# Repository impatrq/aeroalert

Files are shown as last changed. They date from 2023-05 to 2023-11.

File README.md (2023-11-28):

<div align="center">

# **AeroAlert**

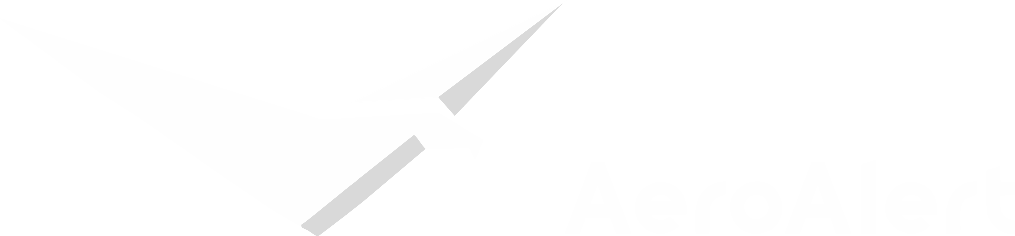
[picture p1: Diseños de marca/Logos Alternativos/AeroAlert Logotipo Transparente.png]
Logo proyecto


</div>

# ¿Qué es AeroAlert?

Aeroalert es un prototipo de sistema de emergencia para aeronaves basado en el monitoreo constante de parámetros de salud de los pilotos para prevenir accidentes aeronauticos.
El sistema cuenta con una pulsera dotada de los sensores necesarios. Si se detecta un estado de salud urgente que implique que el piloto este incapaz de controlar la aeronave, se le otorga el control al piloto automático nativo, el cual, a través de dos equipos de procesamiento diseñados por nosotros, entabla una comunicación con la CTRT correspondiente para llevar la aeronave a una situación que permita evitar el riesgo de accidente.

 * 🎞️ Video presentación: [Aeroalert](https://www.youtube.com/watch?v=lwCH7T5NRF8&ab_channel=ProyectoAeroAlert)

 * 📰 [Notas y difusión](https://docs.google.com/document/d/1UdKEXQvbZDQbbGeclpEPnfsf2L1TE1_X/edit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)

### ¿Quiénes lo desarrollan?
AeroAlert es un proyecto realizado por alumnos de 7mo Año de la **Escuela de Educación Secundaria Técnica N°7 "Taller Regional Quilmes"**, especialidad Aviónica.

<p align="center">
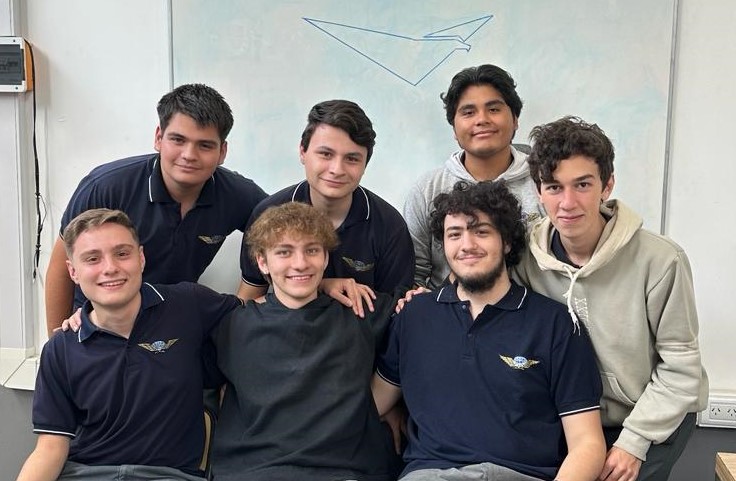
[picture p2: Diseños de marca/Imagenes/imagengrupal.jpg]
Imagen Grupal
  
</p>

# Integrantes

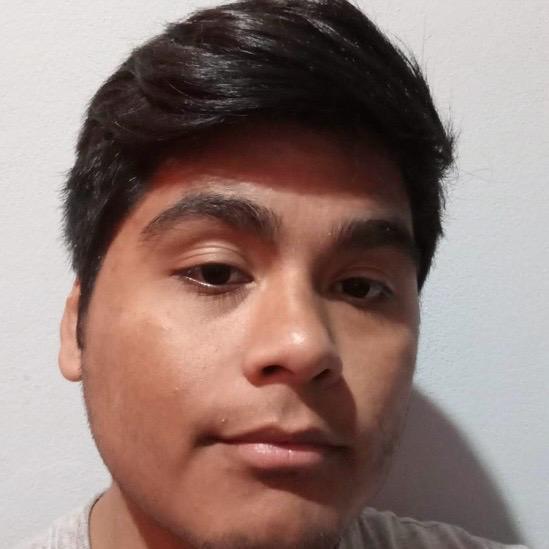
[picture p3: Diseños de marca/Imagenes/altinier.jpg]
Altinier
 * ### *Altinier, Mauro*

    *    📷 Instagram: [@agustin_altinier](https://www.instagram.com/agustin_altinier/)
    *    📧 Email: [mauro.altinier@gmail.com](mailto:mauro.altinier@gmail.com)         
    *    LinkedIn LinkedIn: [Mauro-Agustin-Altinier](https://www.linkedin.com/in/Mauro-Agustín-Altinier)

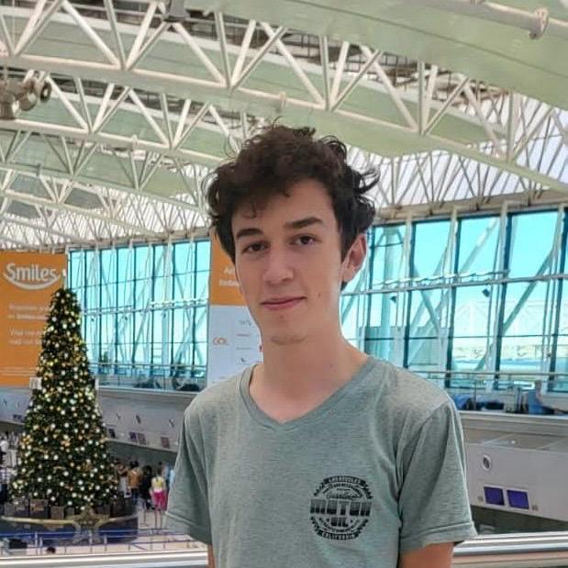
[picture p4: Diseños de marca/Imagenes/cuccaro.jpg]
Cuccaro
 * ###  *Cuccaro, Juan*

    *    📷 Instagram: [@cuccaro_juan](https://www.instagram.com/cuccaro_juan/)
    *    📧 Email: [manucucca10@gmail.com](mailto:manucucca10@gmail.com)
    *    LinkedIn LinkedIn: [juan-cuccaro](https://www.linkedin.com/in/juan-cuccaro/)

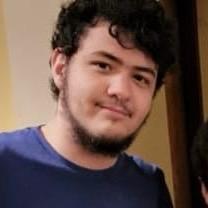
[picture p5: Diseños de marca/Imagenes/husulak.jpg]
Husulak
 * ###  *Husulak, Mateo*

    *    📷 Instagram: [@matehusu_2](https://www.instagram.com/matehusu_2/)
    *    📧 Email: [matehusu@gmail.com](mailto:matehusu@gmail.com)
    *    LinkedIn LinkedIn: [mateo-gaston-husulak-ledo](https://www.linkedin.com/in/mateo-gaston-husulak-ledo-52b742270/)

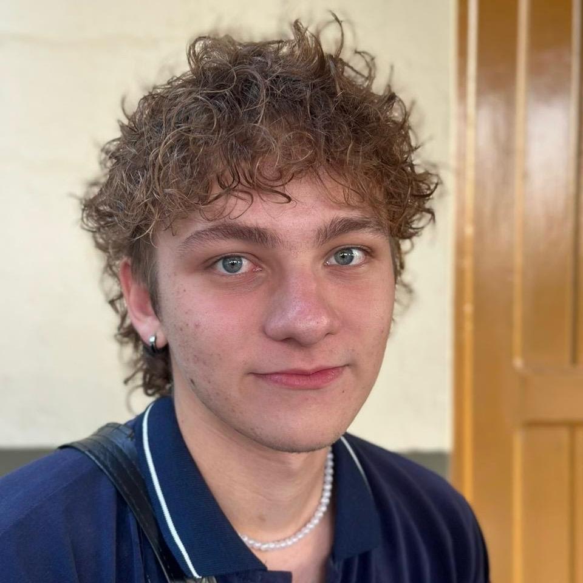
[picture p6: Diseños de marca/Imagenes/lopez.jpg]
Lopez
 * ###  *López, Teo*

    *    🧾 Curriculum vitae: [CVLópezTeoNicolas](https://drive.google.com/file/d/1_G5UPTjoewlIe7h19vwuFQ2f_dssRR7e/view?usp=sharing)
    *    📷 Instagram: [@nico67676](https://www.instagram.com/nico67676/)
    *    📧 Email: [teonicolaslopez8@gmail.com](mailto:teonicolaslopez8@gmail.com)
    *    LinkedIn LinkedIn: [teo-lópez](https://www.linkedin.com/in/teo-lópez/)

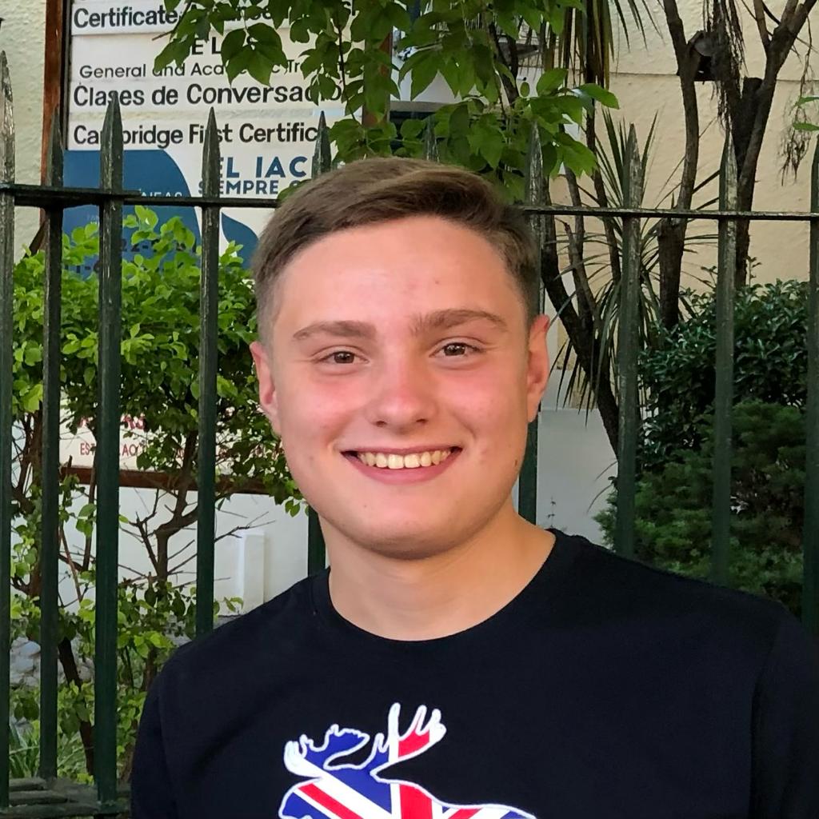
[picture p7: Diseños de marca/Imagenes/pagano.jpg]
Pagano
 * ###  *Pagano, Jonás*

    *    📷 Instagram: [@jonaspagano](https://www.instagram.com/jonaspagano/)
    *    📧 Email: [paganojonas@gmail.com](mailto:paganojonas@gmail.com)
    *    LinkedIn LinkedIn: [jonaspagano](https://www.linkedin.com/in/jonaspagano/)

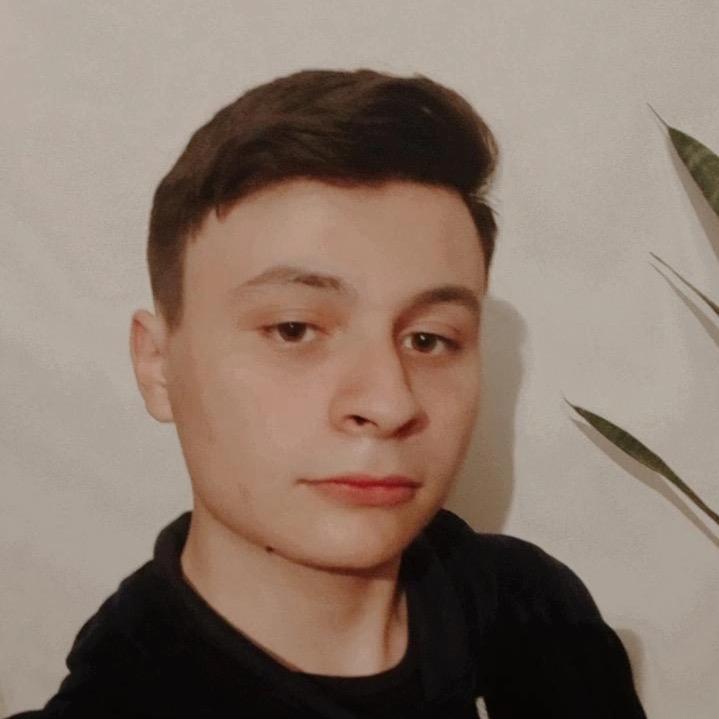
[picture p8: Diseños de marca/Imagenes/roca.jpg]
Roca
 * ###  *Roca, Leandro*

    *    📷 Instagram: [@lean_ro64](https://www.instagram.com/lean_ro64/)
    *    📧 Email: [leandroroca49@gmail.com](mailto:leandroroca49@gmail.com)
    *    LinkedIn LinkedIn: [leandro-roca](https://www.linkedin.com/in/leandro-roca/)

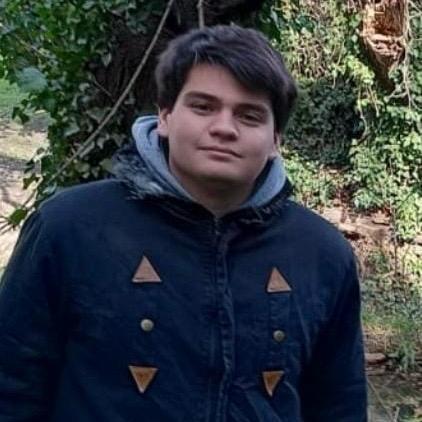
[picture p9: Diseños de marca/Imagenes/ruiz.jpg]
Ruiz
 * ###  *Ruíz, Nicolás*
    *    📷 Instagram: [@nicoo__ruiz](https://www.instagram.com/nicoo__ruiz/)
    *    📧 Email: [ruizagustinnicolas20@gmail.com](mailto:ruizagustinnicolas20@gmail.com)
    *    LinkedIn LinkedIn: [](https://www.linkedin.com/)

# **Contactos** 

* ####    📧 Email: [proyectoaeroalert@gmail.com](mailto:proyectoaeroalert@gmail.com)
* ####    🌐 Página Web: [www.aeroalert.com.ar](https://www.aeroalert.com.ar/)
* ####    📷 Instagram: [@aeroalert.impa](https://www.instagram.com/aeroalert.impa/)
* ####    LinkedIn LinkedIn: [AeroAlert](https://www.linkedin.com/company/aeroalert/)

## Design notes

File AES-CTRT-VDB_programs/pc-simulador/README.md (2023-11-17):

## Requerimientos

```shell
# Recepcion UART para reproduccion de alertas
$ pip install pyserial

# Reproducción alertas
$ pip install playsound==1.3

# Interfaz protocolos
$ pip install arcade
```
Tambien sera necesario instalar los plugins de X-plane

# Procedimiento

Luego de ejecutar el programa en el AES, ejecutar el programa GUI.py y ejecutar UART_X-plane mientras el simulador X-plane se esta ejecutando.

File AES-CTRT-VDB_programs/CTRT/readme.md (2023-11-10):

# Procedimiento
Guardar todos los archivos en la ESP32 con las carpetas en el orden en el que estan
Para esto se puede abrir una pestaña de thonny en  "ver" --> "archivos" y subir todos con click derecho

ejecutar "microdot_mas_keypad..... .py"

Luego de que se ejecuto el programa del AES en la ESP32 y el de la ESP32 de la CTRT , conectarse a la red WiFi ESP32 con la contraseña que este asignada en "accesssv9.py"
En la consola de la ESP32 aparecera la configuracion de la conexion wifi y en que direccion se hosteo la pagina web

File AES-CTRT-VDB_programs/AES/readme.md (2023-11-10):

# Procedimiento

Guardar ambos archivos en el microcontrolador ESP32
Manteniendola conectada a la PC se le da a reset para que se ejecute el programa (sin tener ninguna consola viendo la informacion de la ESP32 ya que esto interferiria en la comunicacion UART)

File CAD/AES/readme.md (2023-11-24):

<div align="left">

# **Automatic Emergency System (AES)**
Acrónimo en idioma inglés de Automatic Emergency System, es el módulo que se se encuentra alojado en cabina, encargado de recibir y procesar la información recopilada por la instrumentación sensorial del sistema (módulo V.D.B). Este equipo desempeña un papel crucial al emitir avisos pertinentes en cabina, establecer comunicación con el equipo en tierra y, en situaciones críticas, interactuar con el piloto automático nativo de la aeronave. La capacidad de establecer comunicación bidireccional con el equipo en tierra permite la transmisión efectiva de datos relevantes y la recepción de instrucciones actualizadas, lo cual es esencial para la coordinación durante operaciones de emergencia.

<p align="center">
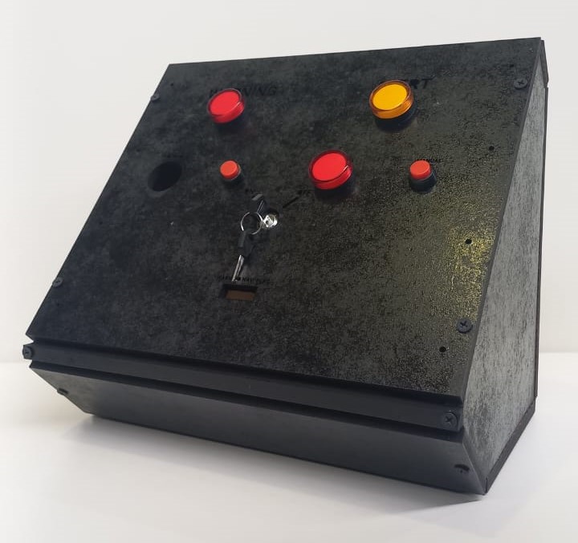
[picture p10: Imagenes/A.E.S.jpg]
AES
  
</p>

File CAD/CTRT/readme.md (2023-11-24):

<div align="left">

# **Control Tower Reciever - Transmitter (CTRT)**
Acrónimo en idioma inglés alusivo a Control Tower Reciever and Transmitter (en español: Receptor y Transmisor de la Torre de Control), es un módulo alojado en tierra y a disposición del control de tráfico aéreo, cuyo propósito es el de recibir, representar visualmente e informar a los controladores aéreos de emergencias, alertas y/o peticiones. Además de su rol informativo, el módulo C.T.R.T se encarga de generar y transmitir instrucciones al equipo en cabina, específicamente al módulo A.E.S. Su propósito primordial es facilitar la ejecución de aterrizajes de emergencia en caso de que esta acción sea necesaria, garantizando una comunicación efectiva y coordinada entre la torre de control y la aeronave, contribuyendo así a la seguridad y eficiencia en situaciones críticas.

<p align="center">
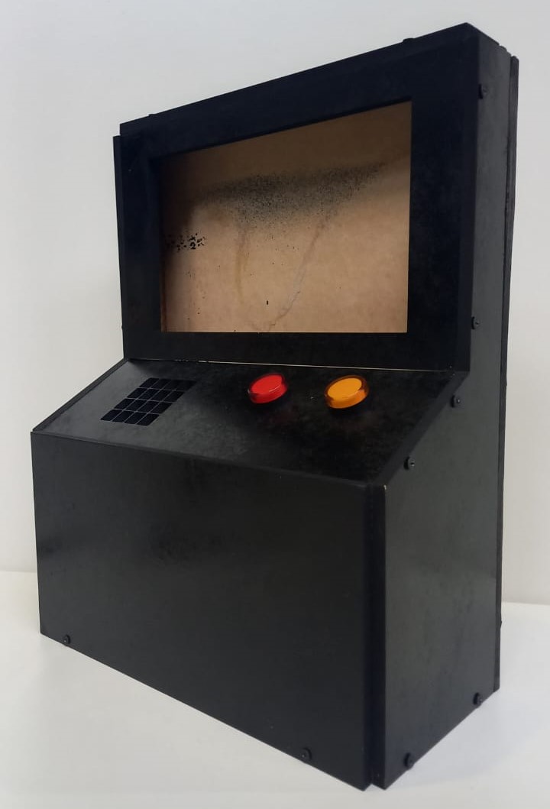
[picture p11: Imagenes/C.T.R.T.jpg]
CTRT
  
</p>

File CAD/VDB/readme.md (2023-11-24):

<div align="left">

# **Vital Data Bracelet (VDB)**
Acrónimo en idioma inglés de Vital Data Bracelet (en español: Pulsera Detectora de Signos Vitales), corresponde al dispositivo pulsera portado tanto por piloto como por copiloto (en caso de existir este último). Su función principal es aquella relacionada al relevamiento de datos asociados a la salud de los conductores de la aeronave (llámese comandante y su potencial compañero de fórmula en caso de existir), con el objetivo de proveer un monitoreo permanente de las variables a medir tanto en cabina como en tierra, de forma tal que exista la posibilidad de generar alertas y/o emergencias tanto de manera presencial (en el medio de transporte físico del vuelo) como remota (por medio del control de tráfico aéreo) en función de las variables de salud relevadas por el módulo descrito previamente, permitiendo la detección temprana de posibles problemas de salud y la toma de medidas adecuadas. La integración de esta tecnología se alinea con el enfoque del proyecto para garantizar la monitorización efectiva de los signos vitales y la rápida respuesta ante cualquier eventualidad.

<p align="center">
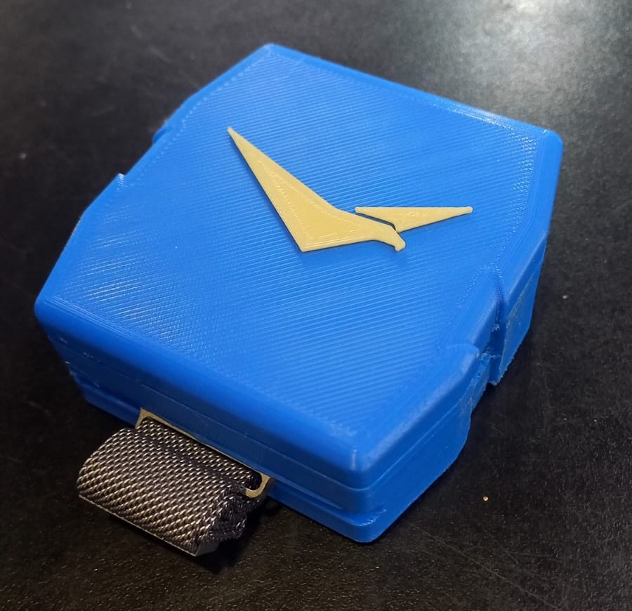
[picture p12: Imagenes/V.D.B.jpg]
VDB
  
</p>

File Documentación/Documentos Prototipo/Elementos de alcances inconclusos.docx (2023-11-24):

Alumnos: Altinier, Mauro / Cuccaro, Juan Manuel / Husulak, Mateo / López, Teo / Pagano, Jonás / Roca, Leandro / Ruiz, Nicolás

Curso y Comisión: 7mo 1ra Aviónica (Comisión A)

Nombre del Proyecto: AeroAlert

Listado de Pendientes

La evaluación del estado de finalización del proyecto en relación a los objetivos de desarrollo del mismo planteados durante el inicio del ciclo lectivo permitió arrojar las siguientes funcionalidades pendientes:

- Procedimientos para cambio de tripulación: El procedimiento de cambio de tripulación no alcanzó su desarrollo, concluyendo que su prueba resultaría desprolija y se alejaría del objetivo principal del proyecto en cuanto a detección y respuesta ante emergencias en vuelo, entorpeciendo su demostración funcional. Por lo tanto, se procedió al descarte del mismo.
- Base de datos de salud: Desde un principio, se planteó la idea de relevar las mediciones del dispositivo pulsera a una base de datos que por medio de la cual se enseñarían valores de salud en la página web del proyecto. Si bien se trabajó y logró un modelo de base de datos, por decisión del equipo de trabajo de dedicarse a demás áreas en pro de generar avances en cuanto a las funcionalidades demostrables del proyecto, el muestreo de datos en la web fue descartado.
- Procedimientos de descanso reglamentario: Este procedimiento, al igual que el anterior, se valdría de la utilización del dispositivo pulsera para su demostración funcional. Sin embargo, fue descartado bajo las mismas consignas que el pendiente anterior.
- Encendido de dispositivo pulsera: El pendiente en cuestión destacaba la implementación de componentes lumínicos y sonoros / vibratorios para la alerta de encendido del dispositivo. Sin embargo, dicha propuesta fue descartada tras la obtención de resultados similares por medio de la detección de encendido y operación del sensor integrado (el mismo emite un haz de luz cuando se encuentra en funcionamiento), lo cual permitió la optimización de espacio en la plaqueta, y un diseño de carcasa de mayor ergonomía.

Por otro lado, los distintos dispositivos requieren de conexión a una computadora por medio de un cable microUSB para alimentación, lo cual resulta en un impedimento para la autonomía de los equipos (necesaria para una demostración lo más fidedigna posible en relación al entorno aeronáutico). Sin embargo, y aunque resulte en una pérdida de calidad en el acabado de dichas unidades para con su funcionamiento, la autonomía de las mismas en cuanto a alimentación nunca fue planificada en el desarrollo del proyecto. Particularmente, un error de diseño en el dispositivo pulsera en cuanto a la regulación de voltaje requiere que el mismo se encuentre conectado a una fuente de alimentación externa por medio del módulo de carga integrado, siendo esta la única unidad del proyecto planteada como autónoma desde el inicio.

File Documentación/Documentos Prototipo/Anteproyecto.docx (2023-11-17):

AeroAlert

Presentación de anteproyecto

# Título del proyecto:

El nombre del proyecto busca encerrar en sí mismo el objetivo a alcanzar. El prefijo Aero enuncia la orientación aeronáutica del proyecto, mientras que la palabra Alert hace referencia al segmento en que se enfoca el sistema (la respuesta ante emergencias en vuelo).

# Integrantes:

- Altinier, Mauro Agustín
- Cuccaro, Juan Manuel
- Husulak Ledo, Mateo Gastón
- López, Teo Nicolás
- Pagano, Jonás
- Roca, Leandro Gabrel
- Ruiz, Nicolás Agustín

# Objetivo del proyecto:

AeroAlert es un sistema de emergencia, el cual tiene como meta prevenir un amplio rango de accidentes aéreos. En pro de tal objetivo, implementa un procesamiento y monitoreo constante de parámetros que involucran tanto a los pilotos de aeronaves como al entorno que los rodea.

Alrededor del 70% de los accidentes aéreos ocurren debido a fallas humanas, entre las cuales destacan algunas como las imprudencias, el cansancio y el vuelo en condiciones de salud no óptimas, entre otras.

En base a lo previamente dicho, AeroAlert propone el desarrollo de equipos que permitan no solo un monitoreo constante, sino también que provean de una respuesta eficiente ante emergencias que, al día de hoy, no son capaces de resolverse de forma íntegra, y con mínimos o nulos daños, lo cual reduciría enormemente los costos económicos y humanos para las distintas partes implicadas en la industria aeronáutica.

# Utilidades de el proyecto:

El sector aeronáutico ha tenido un progreso notable en todas las dimensiones a lo largo de las últimas décadas de la historia. Hoy en día, los aviones son ampliamente considerados como el medio de transporte más seguro que existe. A pesar de esto, y aunque ocurren con poca frecuencia, los accidentes aéreos siguen teniendo un enorme potencial destructivo: se cargan la vida de pasajeros y civiles, la reputación de empresas e ingenieros, e inclusive la existencia de corporaciones enteras.

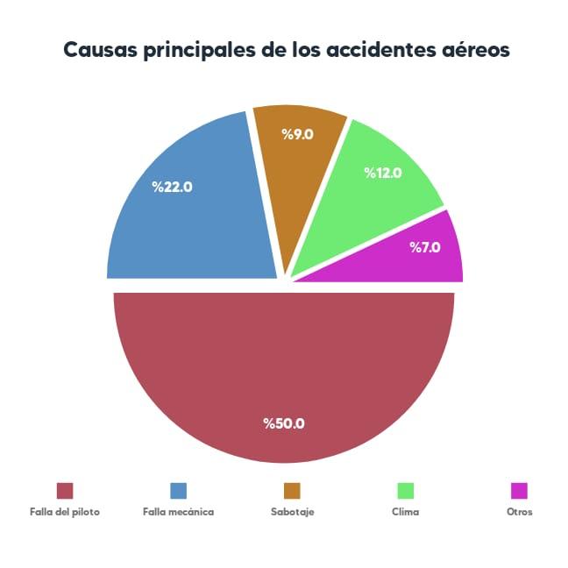
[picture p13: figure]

Estadísticas sobre las causas de accidentes aéreos

AeroAlert tiene como utilidad la prevención de accidentes aéreos, cuya principal causa sigue siendo el factor humano. El censado constante de las condiciones de salud de los pilotos, sumado a la implementación de equipos que permiten tener un control tanto automático como manual (a través del piloto) y externo (por medio de la torre de control) será capaz de reducir considerablemente el riesgo de siniestros aéreos, permitiendo la preservación de la vida y de recursos económicos en el sector aeronáutico.

Descripción del funcionamiento:

Para lograr el objetivo se confeccionará una pulsera, que enviará los datos al “PAE”(Piloto Automático de Emergencia) que estaría en la cabina, de este se enviará a un equipo que se encuentra en una torre de control donde se pueden analizar los datos recibidos y mandar instrucciones al PAE.

La pulsera tendra un sensor Max30102 que medira las pulsaciones y la saturación de oxígeno en sangre, con una Esp32 Wroom, este procesara los datos censados para que sean datos de menor peso y posteriormente mandarlos al sistema PAE mediante Bluetooth, la pulsera se alimentara con una batería de litio con un regulador de voltaje Step down 3,3v.

El PAE tendrá una Esp32 que los procesa y dependiendo el resultado pedirá una reacción del piloto, deberá tocar el botón para avisar que no es una urgencia, los datos se mandarán igualmente a la torre de control mediante una red WiFi (en caso real con otro protocolo), en la torre de control habrá otra persona que analizara los datos recibidos y enviar o no, instrucciones al PAE para mantener la seguridad del vuelo.

- En el caso del oxígeno en sangre, por ejemplo, si se está por debajo del 96%, se toma en cuenta junto a las pulsaciones para definir si el piloto podria está dormido y mandar una alerta, a la vez pedirá la reacción del piloto, si reacciona a tiempo entonces y no será una alerta; y en caso de inferioridad al 90% se envía un alerta de alta importancia al R.T.D.C, ya que probablemente el piloto se encuentre en riesgo.
- Cuando las pulsaciones sean inferiores a 20 ppm, también se mandará una alerta al R.T.D.C, ya que la vida del piloto corre peligro; si superan las 140 ppm también, ya que esto podría indicar algún problema, naturalmente en un vuelo no deberían tener tan altas las pulsaciones por minuto, por lo tanto podría significar un posible problema.
- En la ocasión de que el piloto decida activar el P.A.E de forma manual, lo puede hacer presionando el botón de activación manual.
- Si el P.A.E tiene alguna falla por índole eléctrico, el piloto podrá desactivar el sistema mediante un botón.
- También se pueden evitar accidentes con siniestros aeronáuticos, cuando se detecte la torre de control activará el piloto automático de emergencia sin que el avión pueda evitarlo.
- En adición, aunque como un tramo opcional del proyecto, se buscará realizar la implementación del sistema en el simulador Avis.

# Análisis de factibilidad:

En el grupo, decidimos dividir el trabajo del proyecto en 4 sectores:

- Diseño y construcción: Dentro de este sector de trabajo, se llevará a cabo el diseño estructural de los equipos, su ensamblaje y su disposición en un espacio que resulte no intrusivo.
  - El alumno Ruiz Nicolás Agustín se encargará del diseño estructural
  - El alumno Altinier Mauro Agustín llevará a cabo la tarea de ensamblaje y acabado final
- Electrónica: Este sector se encarga del diseño y planificación de circuitos electrónicos (a través de simulaciones y planos CAD), el ensamblaje de componentes, el armado de placas y de la instalación eléctrica del piloto automático de emergencia.
  - Los alumnos Pagano Jonás y Roca Leandro Gabriel trabajarán en conjunto en el diseño esquemático y simulación preliminar de los circuitos electrónicos de los equipos
  - El alumno Pagano Jonás se encargará de la implementación de los circuitos en PCB.
  - El alumno Lopez Teo Nicolás se encargará del ensamblaje de componentes y comprobación de correcto funcionamiento de los circuitos electrónicos.
- Programación: Este entorno de trabajo se encarga de toda la programación del sistema de emergencia propuesto (conexión bluetooth entre pulsera y PAE, PAE con RTdc, programa del PAE para cálculos, programa RTdc y el desarrollo del código de la página web).
  - Los alumnos Cuccaro Juan Manuel y Husulak Ledo Mateo Gastón trabajarán simultaneamente realizando los programas necesarios para la pulsera, el PAE y la RTdc
  - Los alumnos Pagano Jonás y Roca Leandro Gabriel trabajarán con el programa que permita entablar una comunicación entre el simulador X-Plane y el PAE.
  - Los alumnos Husulak Ledo Mateo Gastón y Ruiz Nicolás Agustín se encargarán del desarrollo de la página web del proyecto.
- Marketing: En esta área de trabajo se desarrollará un trabajo conjunto entre todos los miembros del grupo, los cuales tendrán como objetivo mantener actualizados los perfiles de redes sociales del proyecto con material informativo y avances de las labores realizadas. Al mismo tiempo, y complementandose con el área de programación, se desarrollará una página web que provea la información básica y esencial de nuestro proyecto.
  - El alumno Lopez Teo Nicolás se encargará del diseño de la representación visual y gráfica de la página web y sus elementos.
  - Todos los integrantes tendrán control directo sobre las redes sociales. Se prevé crear perfiles tanto en Instagram como en LinkedIn
  - El alumno López Teo Nicolás será el encargado de diseñar el material publicitario alternativo (pegatinas, folletos, etc.) Como un objetivo de cumplimiento opcional, nos propondremos la confección de camisetas AeroAlert para el equipo de trabajo.
  - También en este entorno, intentaremos encontrar empresas interesadas en apoyar el proyecto ya sea aportando dinero o alguna herramienta que podamos usar.

# Costo del proyecto:

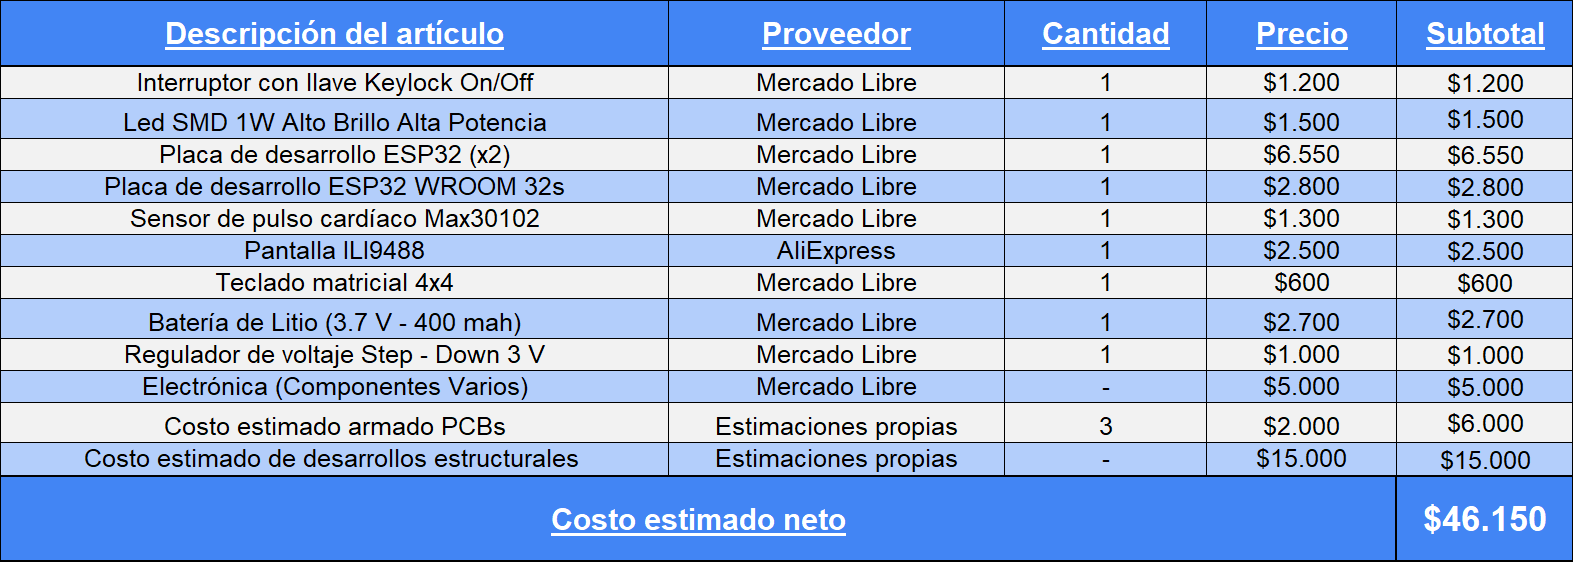
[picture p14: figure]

Nota: Los precios se encuentran actualizados al día 10/3/23.

# Análisis de costo/beneficio:

Inclusive siendo considerado como el medio de transporte más seguro en todo el mundo, el avión (así como quienes lo pilotan y se transportan en él) no se encuentra exento de sufrir accidentes por desperfectos técnicos y, principalmente, por cuestiones humanas.

Además, y por increíble que resulte en una industria tal como la aeronáutica, existen casos de emergencia que, al día de hoy, no tienen una respuesta completa que minimice el riesgo de accidentes y muertes tanto de pasajeros como de la tripulación y potenciales civiles en tierra. Tan solo se debe pensar qué ocurre si todos los ocupantes de una aeronave quedan inconscientes por hipoxia, o qué pasaría si un piloto desea acabar con su vida estrellando un avión comercial. A pesar de que existan protocolos contra estos casos, ninguno es capaz de reducir al mínimo la posibilidad de accidentes y muertes, ya sea a través de un control automático o el monitoreo de la situación por parte de la torre de control.

Durante las investigaciones preliminares llevadas a cabo por miembros de este grupo, se han detectado un total de 27 casos relacionados (de los cuales 15 cuentan con desenlaces fatales) en un lapso de 35 años hasta la actualidad). Esta idea sería capaz de despertar interés en fabricantes de equipos aeronáuticos, aerolíneas y/o agencias reguladoras nacionales e internacionales, que podrían buscar llevar a cabo la idea propuesta de una forma que hoy en día el grupo de trabajo, con sus recursos disponibles, no sería capaz.

# Diagrama en bloques del prototipo:

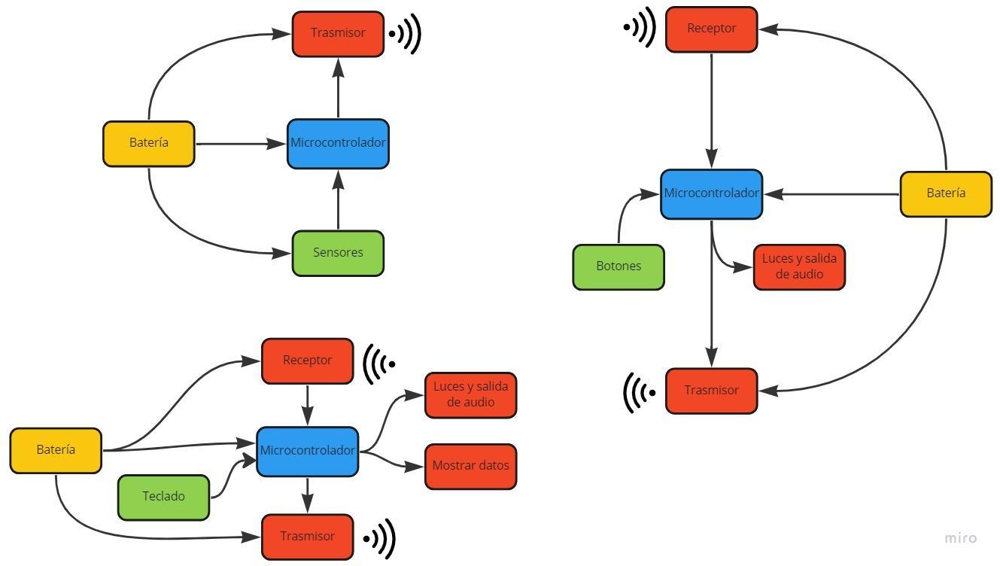
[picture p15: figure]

Diagrama de tiempo de desarrollo:

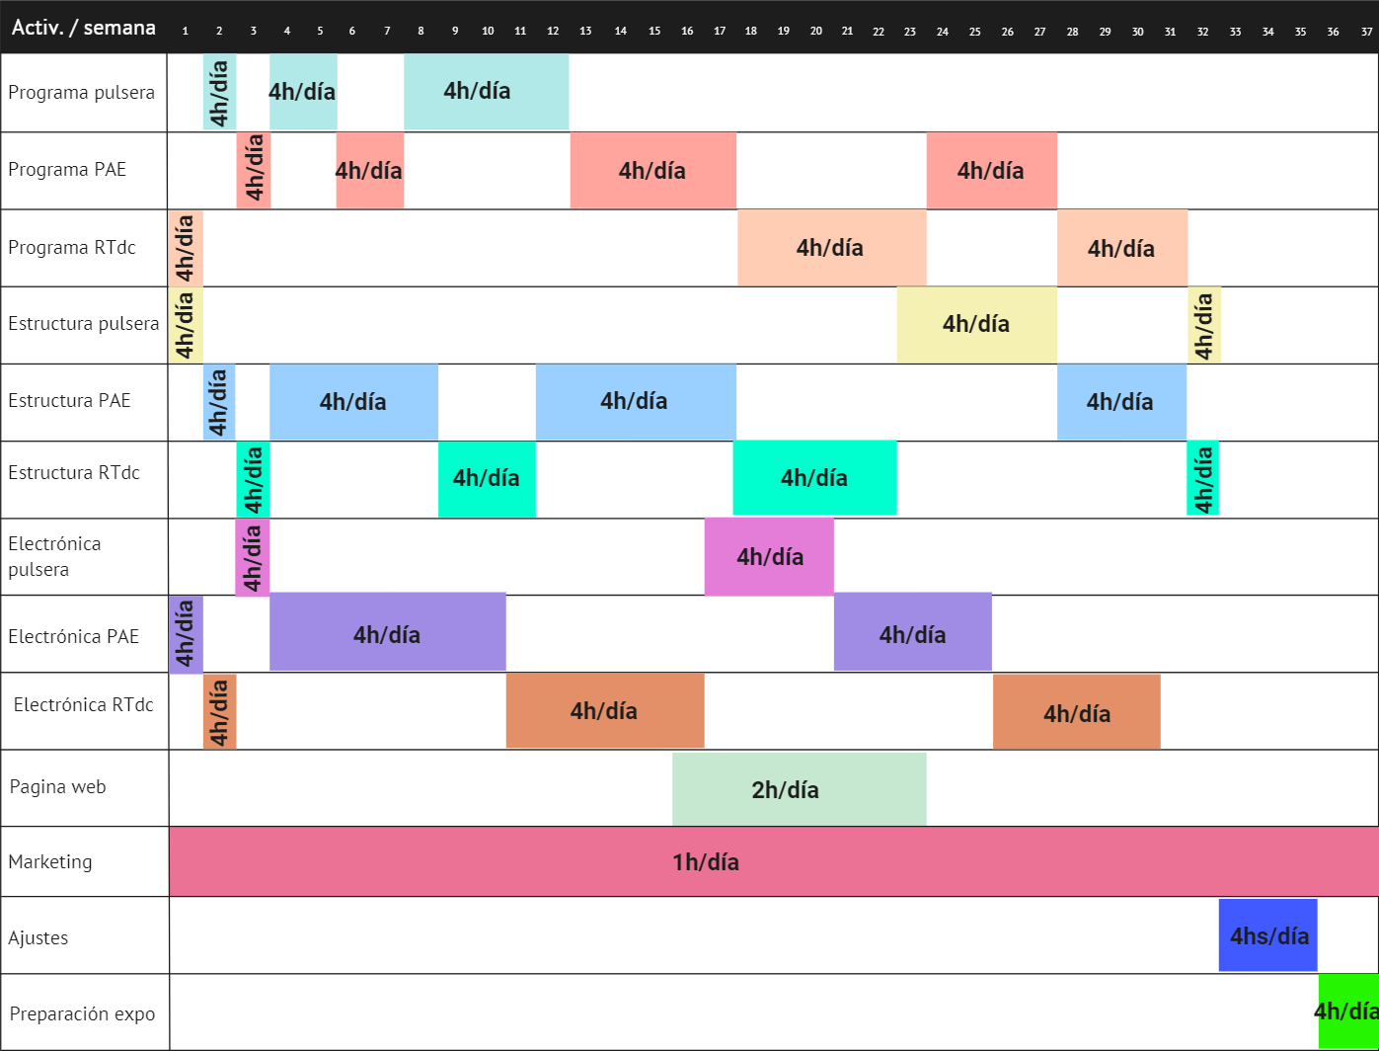
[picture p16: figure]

Fuentes

(1) https://docs.google.com/document/d/1L2hu_MUP8gzjOCmHIrkDrV9m0Blvit6O/edit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

Escuela de Educación Técnica Nº7 Taller Regional Quilmes Prácticas Profesionalizantes: Especialidad Aviónica

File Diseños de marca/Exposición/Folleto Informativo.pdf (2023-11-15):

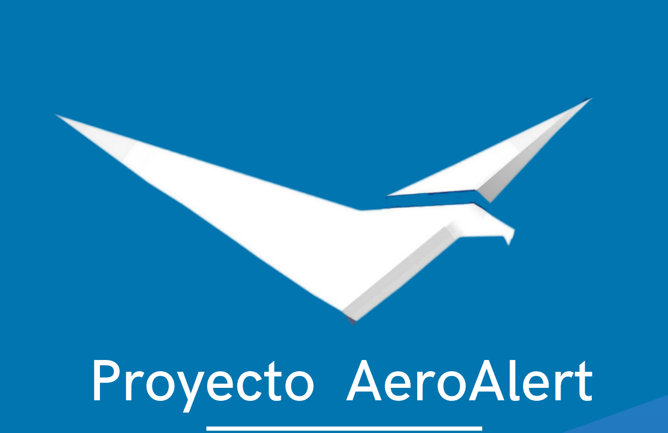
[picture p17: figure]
Proyecto AeroAlert

Sistema de emergencia para aeronaves

Hoy en día la seguridad de las aeronaves no ha parado de aumentar, pero a pesar de su crecimiento acelerado en las últimas décadas todavía hay determinados casos en los cuales no existen protocolos adecuados o eficientes.

Situaciones como desmayos de los pilotos, muerte de ambos, inconsciencia por hipoxia, casos de siniestros dolosos (secuestro, suicidio por parte de la tripulación), son ejemplos claros en donde no existe un protocolo eficaz.

Nuestra meta es proponer una solución funcional para estos casos, permitiendo así vuelos más seguros y desarrollar un sistema de control más sofisticado en las aeronaves.

Nuestro objetivo

### ¿Quiénes somos?

Somos un grupo de estudiantes de 7mo 1ra Aviónica, conformado por:

•Altinier Mauro
•Cuccaro Juan Manuel
•Husulak Mateo
•Lopez Teo

•Pagano Jonás
•Roca Leandro
•Ruiz Nicolás

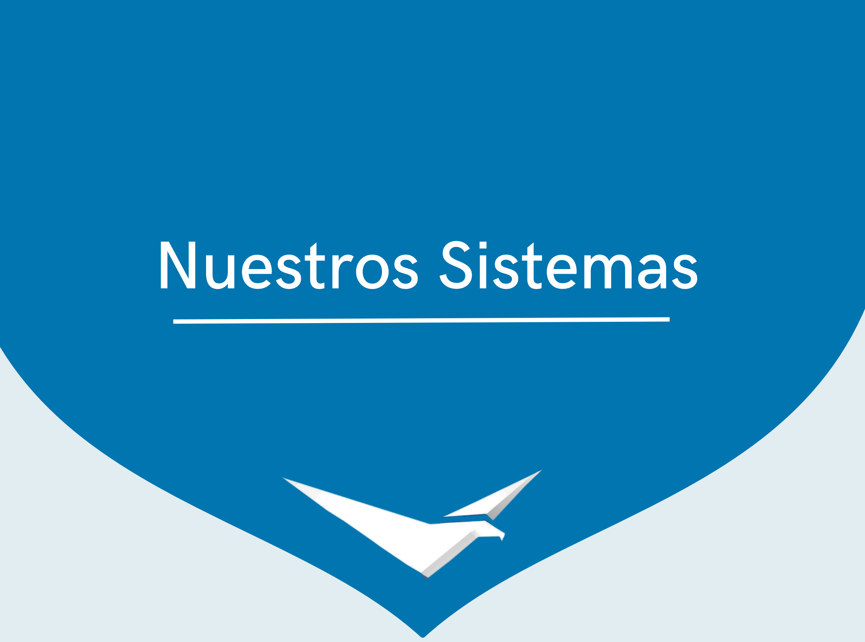
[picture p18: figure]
Nuestros Sistemas

ICERS - I | ICERS - II

## Características de ambos sistemas

No requiere de una
intervención estructural en la
cabina

Puede ser implementado
en cualquier aeronave

Prevé de alertas para los
pilotos

Puede alertar a tierra con precisión del hecho ocurrido

Permite que la aeronave
pueda realizar aterrizajes de forma automática

Prevé ocasiones de
índole doloso

Es el sistema más
completo, diseñado para
aeronaves modernas.

Este sistema pretende ser
básico y económico para la implementación en
aeronaves pequeñas y/o
antiguas. | Tiene como objetivo evitar accidentes y alertar los mismos entre
| sus equipos.

Prioriza la transmisión de alertas dentro y fuera de
la aeronave, para una
mayor seguridad.

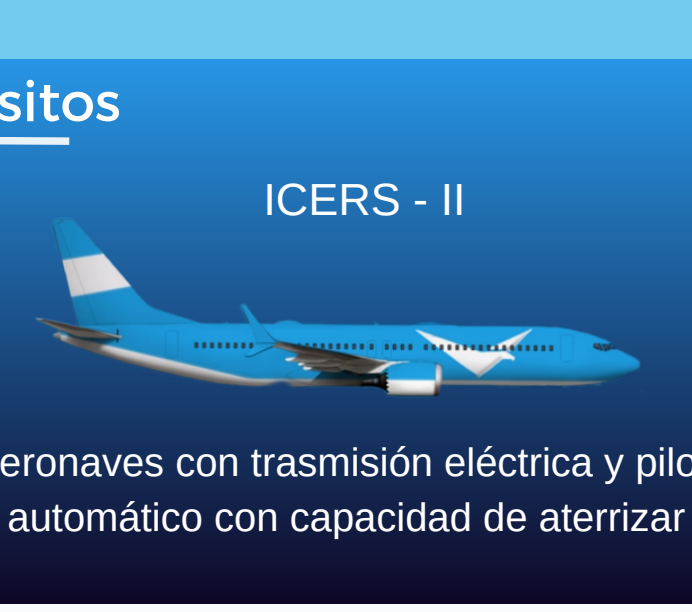
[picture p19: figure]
ICERS - II; automático con capacidad de aterrizar
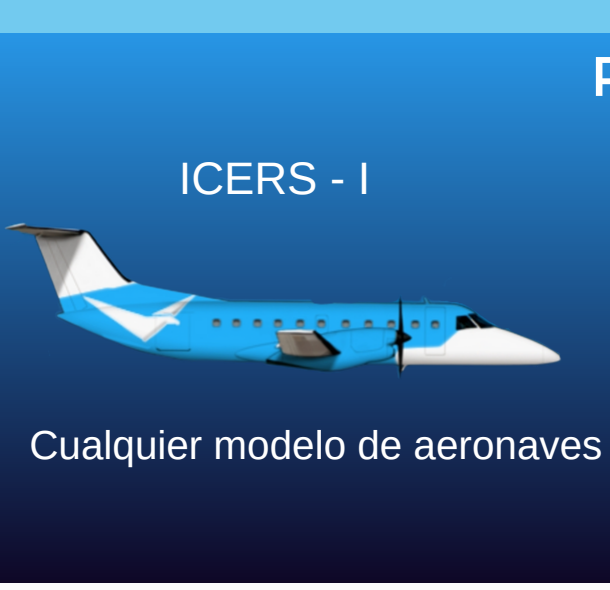
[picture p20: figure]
ICERS - I; Cualquier modelo de aeronaves

### Requisitos

Aeronaves con trasmisión eléctrica y piloto

In - Cockpit Emergency Resolution System - I In - Cockpit Emergency Resolution System - II

Además de poseer estas 2 versiones, también se puede adaptar el sistema ICERS para una aeronave en específico, obteniendo una versión personalizada.

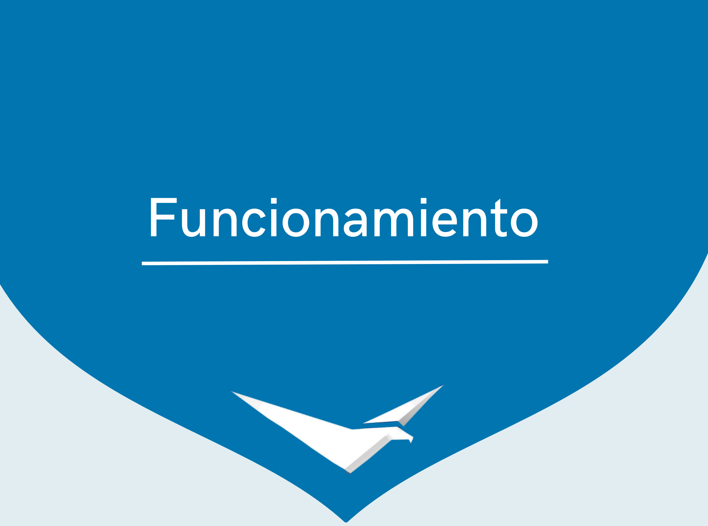
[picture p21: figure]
Funcionamiento

Posee 2 equipos, uno en cabina y otro en tierra, a disposición del control de trafico aéreo. El equipo en cabina se denomina A.E.S y debe procesar los datos enviados por los sensores y dependiendo de ellos activar o no un aviso, una alarma o una señal de emergencia.

Cuando esto último ocurre, procede a contactar con el equipo en tierra (denominado C.T.R.T), por medio del cual se transmiten comandos / instrucciones al A.E.S, cuya recepción y procesamiento de información transmitida desde tierra permitirá, por medio de una comunicación con la computadora de vuelo de la aeronave, efectuar aterrizajes de emergencia

## ICERS I

Solo posee un equipo y este es el de cabina, de igual manera puede poseer los mismos sensores que el ICERS II, pero en su funcionamiento se encuentran ligeras diferencias. A la hora de ocurrir un incidente, el A.E.S solo activa una baliza de radiofrecuencia de emergencia y muestra indicaciones en cabina.

## ICERS II

## Especificaciones del sistema

El sistema provee la implementación de cualquier tipo de sensor que pueda indicar un peligro para los tripulantes. En nuestro caso realizaremos las lecturas de las pulseras, que pueden medir las pulsaciones y la saturación del oxígeno de los pilotos.

El sistema posee protocolos para su utilización y para las acciones que deberán tomar los distintos actores (Pilotos y controladores aéreos) en caso de emergencia.

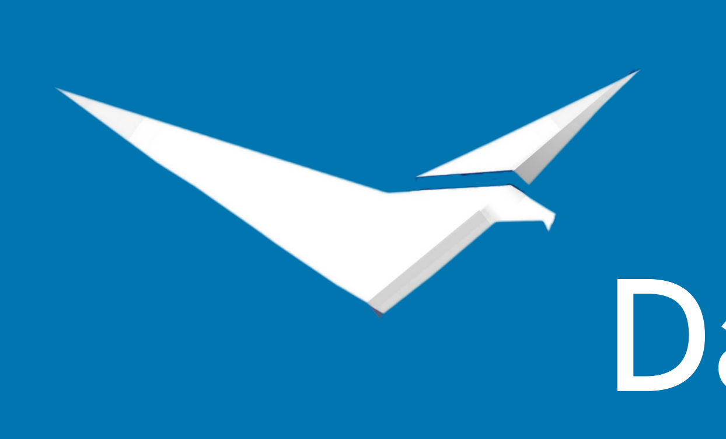
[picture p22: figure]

# Datos

Desde el año 1988 hasta la actualidad (2023) hemos registrando casi 40 accidentes producidos por los casos previamente dados, de los cuales 17 fueron fatales, llevándose consigo casi 1000 personas y con un costo estimado de 2 mil millones de dólares, sin contar indemnizaciones.

Algunos casos:

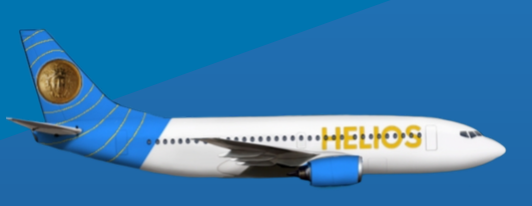
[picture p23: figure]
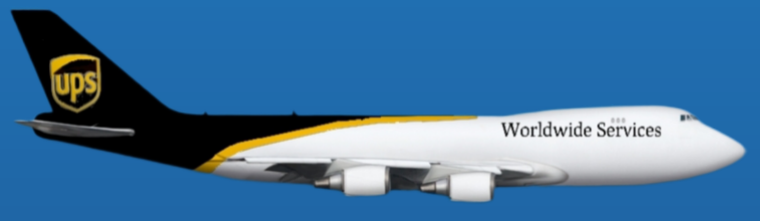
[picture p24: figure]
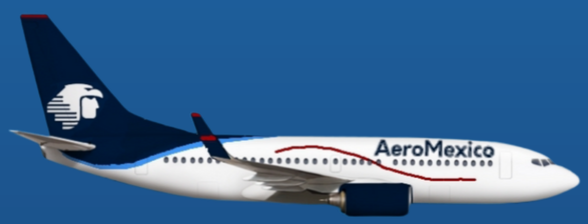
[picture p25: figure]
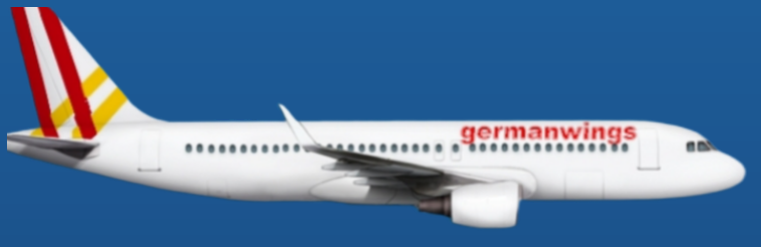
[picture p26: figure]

## Contacto

Vuelo 522 de Helios Airways | Vuelo 6 de UPS
Vuelo 9525 de Germanwings | Vuelo 576 de Aeroméxico

Empresas afectadas

American airlines
Helios Airways
Kalitta Flying
Aeroflot
Ups
United Airlines
British Airways
Germanwings
Royal Air marc
Air France
Singapore Airlines

Egyptair
Silkair
Continental Airlines
Etheopian Airlines
Citilink
Air India
Norwest Airlines
Envoy Air
China Eastern Airlines
Fedex
Scandinavian Airlines

Aeroméxico
LAM
Afriqiyah Airways
India Airlines
Avianca
All Nippon Airways
Air Botswana
Hemus Air
PIA
Lufthansa
Kuwait Airways
AeroAlert | proyectoaeroalert@gmail.com | aeroalert.impa

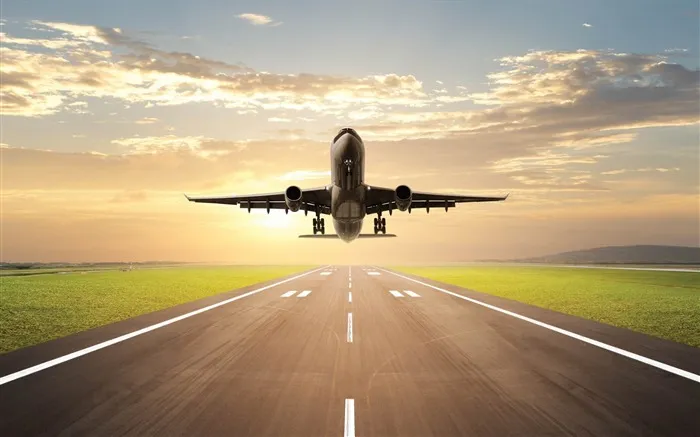
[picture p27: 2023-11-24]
Pagina Web/imgs/airplane_ready_to_take_off-Aircraft_HD_Wallpaper_medium.webp

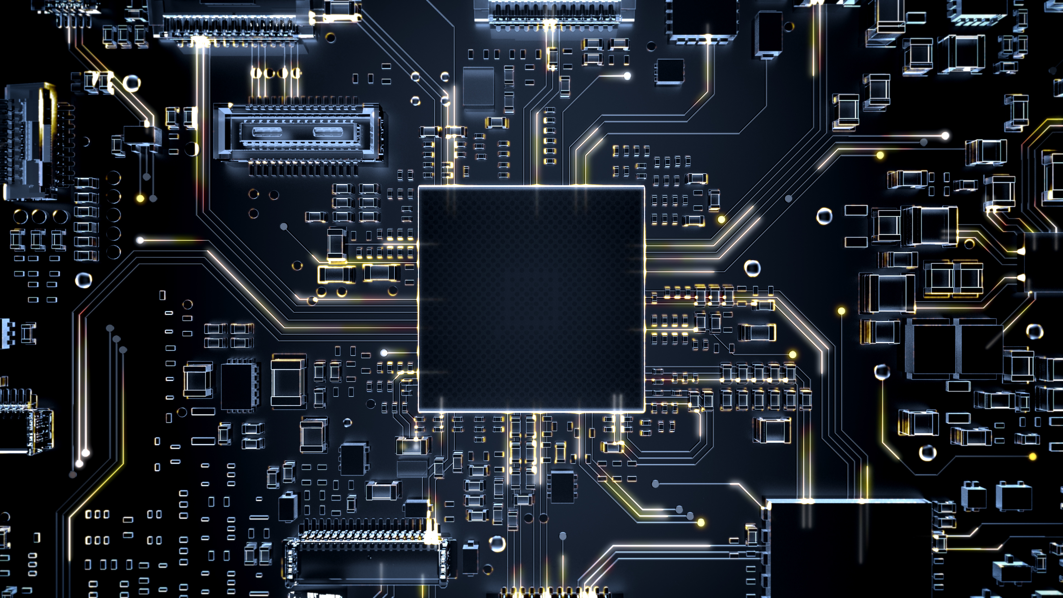
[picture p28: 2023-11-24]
Pagina Web/imgs/Electronica.jpg

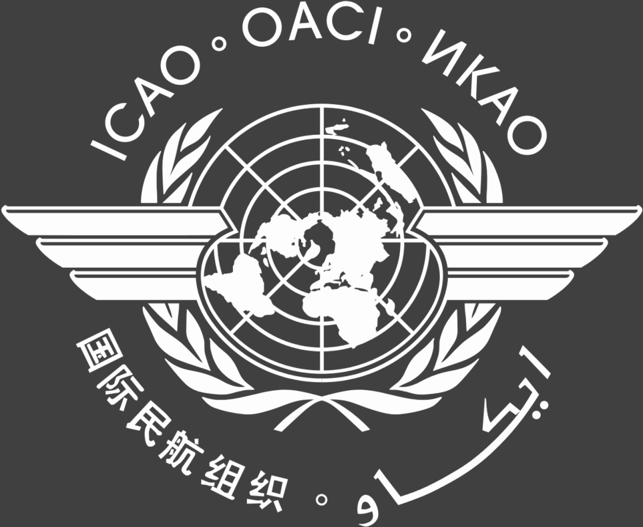
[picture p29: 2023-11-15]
Diseños de marca/Recursos adicionales/139-1392107_icao-united-nations-spa.png

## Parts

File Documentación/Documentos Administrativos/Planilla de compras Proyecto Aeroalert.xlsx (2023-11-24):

Adquirido | Cantidad | Componente | Link de referencia | Mejor precio | Por cantidad | Prestado? | Escuela? | Compra? | Proveedor | Devolver a:
TRUE | 1 | Interruptor con llave Keylock On/Off | CLICK (https://articulo.mercadolibre.com.ar/MLA-1297766235-interruptor-conllaves-%20keylock-switch-onoff-pc-omicron-%20_JM) | $800,00 | $800,00 | FALSE | TRUE | FALSE | Mercado Libre | -
TRUE | 1 | Teclado Matricial 4x4 | CLICK (https://articulo.mercadolibre.com.ar/MLA-726324320-tecladomembrana-%20matricial-4x4-keypad-arduino-autoadhesivo-_JM) | $450,00 | $450,00 | FALSE | TRUE | FALSE | Mercado Libre | -
TRUE | 2 | Modulo de desarrollo ESP32 | CLICK (https://articulo.mercadolibre.com.ar/MLA-1339854427-2-x-nodemcuesp32-%20wifi-bluetooth-38-pines-%20_JM) | $6.550,00 | $13.100,00 | FALSE | TRUE | FALSE | Mercado Libre | -
TRUE | 1 | Placa de desarrollo ESP32 WROOM 32s | CLICK (https://articulo.mercadolibre.com.ar/MLA-767959204-modulo-esp32wifi-%20y-bluetooth-41-esp-wroom-32-80211-b-g-n-_JM) | $2.900,00 | $2.900,00 | FALSE | TRUE | FALSE | Mercado Libre | -
TRUE | 1 | Sensor Pulsoximétrico Max 30102 | CLICK (https://articulo.mercadolibre.com.ar/MLA-1143512095-%20max30102oximetro-de-pulso-arduino-_JM) | $1.890,00 | $1.890,00 | FALSE | TRUE | FALSE | Mercado Libre | -
TRUE | 1 | Batería LiPol LP692530 | CLICK (https://articulo.mercadolibre.com.ar/MLA-835793454-bateria-37-%20v500mah-602530-3x25x60mm-_JM) | $2.160,00 | $2.160,00 | FALSE | TRUE | FALSE | Mercado Libre | -
TRUE | 1 | Regulador de voltaje LM2596T (3.3v) | CLICK (https://articulo.mercadolibre.com.ar/MLA-786025400-lm2596-) | $750,00 | $750,00 | FALSE | TRUE | FALSE | Mercado Libre | -
TRUE | 1 | Adaptador USB a UART PL2303 | CLICK (https://articulo.mercadolibre.com.ar/MLA-620762335-%20adaptadorconversor-usb-ttl-serie-pl2303-5v-33v-ptec-_JM) | $700,00 | $700,00 | FALSE | TRUE | FALSE | Mercado Libre | -
TRUE | 1 | Regulador de voltaje LM1117 (3.3v) | CLICK (https://articulo.mercadolibre.com.ar/MLA-721532318-lm-1117-lm-1117-lm-1117t-lm1117-lm1117t-33-ldo-8-a-to220-_JM) | $670,00 | $670,00 | FALSE | FALSE | TRUE | Electrónica RC | -
TRUE | 1 | Placa adaptadora para ESP32 | CLICK (https://articulo.mercadolibre.com.ar/MLA-737667310-wifi-esp32-placa-adaptador-para-esp32s-a-pines-itytarg-_JM) | $810,00 | $810,00 | FALSE | TRUE | FALSE | Mercado Libre | -
TRUE | 1 | Pack x10 unidades resistencias de 10KΩ SMD 0805 | CLICK (https://articulo.mercadolibre.com.ar/MLA-911446391-resistencia-10k-10000-ohm-0805-smd-10-unidades-5-_JM) | $629,00 | $629,00 | FALSE | TRUE | FALSE | Mercado Libre | -
TRUE | 1 | Integrado CD4027 Doble Flip Flop JK | CLICK (https://articulo.mercadolibre.com.ar/MLA-698259379-cd4027-doble-flip-flop-jk-pack-x1-unidades-_JM) | $1.513,00 | $1.513,00 | FALSE | TRUE | FALSE | Mercado Libre | -
TRUE | 1 | Pack x20 unidades capacitor 10uf SMD 0805 | CLICK (https://articulo.mercadolibre.com.ar/MLA-759069327-20x-capacitorsmd-0805-10uf-10-10v-106k-x5r-cl21a106kpfnnne-_JM) | $955,00 | $955,00 | FALSE | TRUE | FALSE | Mercado Libre | -
TRUE | 1 | Pack x10 unidades resistencias de 2,2KΩ SMD 0805 | CLICK (https://articulo.mercadolibre.com.ar/MLA-1108268953-resistencia-22k-ohm-0805-2201-smd-10-unidades-1-_JM) | $617,00 | $617,00 | FALSE | TRUE | FALSE | Mercado Libre | -
TRUE | 1 | Pack x50 unidades resistencias de 560Ω SMD 0805 | CLICK (https://articulo.mercadolibre.com.ar/MLA-1383276998-50-x-resistencia-smd-0805-18w-5-valores-a-eleccion-_JM) | $700,00 | $700,00 | FALSE | TRUE | FALSE | Mercado Libre | -
TRUE | 1 | Pack x20 unidades capacitor 1nf SMD 0805 | CLICK (https://articulo.mercadolibre.com.ar/MLA-759069327-20x-capacitorsmd-0805-10uf-10-10v-106k-x5r-cl21a106kpfnnne-_JM) | $955,00 | $955,00 | FALSE | TRUE | FALSE | Mercado Libre | -
TRUE | 1 | Pack x15 unidades resistencias de 10KΩ SMD 0603 | CLICK (https://articulo.mercadolibre.com.ar/MLA-1390167382-resistencia-10-k-ohm-01c-1-smd-0603-pack-x-15-unidades-_JM) | $587,00 | $587,00 | FALSE | TRUE | FALSE | Mercado Libre | -
TRUE | 2 | Módulo step - up MT 3608 | CLICK (https://articulo.mercadolibre.com.ar/MLA-1222236602-fuente-boost-elevador-de-tension-step-up-2a-mt3608-pack-x2-_JM) | $1.980,00 | $3.960,00 | FALSE | TRUE | FALSE | Mercado Libre | -
TRUE | 1 | Pack x2 relé 5v | CLICK (https://articulo.mercadolibre.com.ar/MLA-1129168135-pack-x2-rele-5v-simple-inversor-10a-relay-srd-05vdc-sl-c-_JM) | $2.029,00 | $2.029,00 | FALSE | TRUE | FALSE | Mercado Libre | -
TRUE | 1 | Display LED 3 digitos 7 segmentos rojo | CLICK (https://articulo.mercadolibre.com.ar/MLA-606854172-1-display-led-3-digitos-7-segmentos-color-rojo-catodo-comun-_JM) | $2.950,00 | $2.950,00 | FALSE | TRUE | FALSE | Mercado Libre | -
TRUE | 1 | Driver BCD a 7 segmentos | CLICK (https://articulo.mercadolibre.com.ar/MLA-698258898-cd4511-decodif-driver-latch-bcd-a-7-segmentos-_JM) | $1.583,00 | $1.583,00 | FALSE | TRUE | FALSE | Mercado Libre | -.
TRUE | 1 | Indicador luminoso ojo de buey 12V rojo | CLICK (https://articulo.mercadolibre.com.ar/MLA-898941925-ojo-de-buey-led-rojo-tablero-12v-22mm-indicador-led-rojo-_JM) | $2.765,00 | $2.765,00 | FALSE | TRUE | FALSE | Mercado Libre | -
TRUE | 1 | Indicador luminoso ojo de buey 12V amarillo | CLICK (https://articulo.mercadolibre.com.ar/MLA-898953384-ojo-de-buey-led-amarillo-tablero-12v-22mm-indicador-led-_JM) | $2.765,00 | $2.765,00 | FALSE | TRUE | FALSE | Mercado Libre | -
TRUE | 2 | Mecha dremel Router CNC (0,5mm y 0,7mm) | CLICK (https://articulo.mercadolibre.com.ar/MLA-1213164430-micro-mecha-dremel-router-cnc-tungsteno-varias-medidas-_JM) | $1.200,00 | $2.400,00 | FALSE | TRUE | FALSE | Mercado Libre | -
TRUE | 1 | Tira pines hembra 2.54mm 90° | CLICK (https://articulo.mercadolibre.com.ar/MLA-627587730-tira-de-pines-hembra-1x40-254mm-90-grados-ptec-_JM) | $435,00 | $435,00 | FALSE | TRUE | FALSE | Mercado Libre | -
TRUE | 1 | Módulo Step - up MT 3608 | CLICK (https://articulo.mercadolibre.com.ar/MLA-912188461-fuente-convertidor-mt3608-boost-elevador-dc-step-up-2a-28v-_JM) | $1.526,00 | $1.526,00 | FALSE | TRUE | FALSE | Mercado Libre | -
TRUE | 2 | Relé 5V | CLICK (https://articulo.mercadolibre.com.ar/MLA-927639709-rele-relay-5v-dc-simple-inversor-10a-220v-arduino-hobb-_JM) | $1.285,00 | $2.570,00 | FALSE | TRUE | FALSE | Mercado Libre | -
TRUE | 2 | Pack x5 borneras 5 vías | CLICK (https://articulo.mercadolibre.com.ar/MLA-1106799423-terminal-conector-pcb-2x1-5mm-calidad-electronica-hobb-_JM) | $1.626,00 | $3.252,00 | FALSE | TRUE | FALSE | Mercado Libre | -
TRUE | 1 | Pack x5 tiras 40 pines hembra 2.54mm | CLICK (https://articulo.mercadolibre.com.ar/MLA-927569939-pack-5-tiras-peine-40-pines-hembra-standard-paso-254mm-hobb-_JM) | $1.651,00 | $1.651,00 | FALSE | TRUE | FALSE | Mercado Libre | -
TRUE | 2 | Pack x5 Diodos Rectificadores | CLICK (https://articulo.mercadolibre.com.ar/MLA-904528470-pack-5-diodo-rectificador-1n4001-1a-50v-arduino-hobbytronica-_JM) | $1.029,00 | $2.058,00 | FALSE | TRUE | FALSE | Mercado Libre | -
TRUE | 1 | Display LED barras 10 segmentos rojo | CLICK (https://articulo.mercadolibre.com.ar/MLA-1161021649-display-led-barras-indicador-dip-10-segmentos-rojo-hobb-_JM) | $1.244,00 | $1.244,00 | FALSE | TRUE | FALSE | Mercado Libre | -
TRUE | 2 | Indicador luminoso ojo de buey 12V rojo | CLICK (https://articulo.mercadolibre.com.ar/MLA-898941925-ojo-de-buey-led-rojo-tablero-12v-22mm-indicador-led-rojo-_JM) | $5.006,00 | $10.012,00 | FALSE | TRUE | FALSE | Mercado Libre | -
TRUE | 1 | Indicador luminoso ojo de buey 12V amarillo | CLICK (https://articulo.mercadolibre.com.ar/MLA-898953384-ojo-de-buey-led-amarillo-tablero-12v-22mm-indicador-led-_JM) | $5.006,00 | $5.006,00 | FALSE | TRUE | FALSE | Mercado Libre | -
TRUE | 3 | Pack x3 transistor BJT NPN BC 337 (TO-92) | CLICK (https://articulo.mercadolibre.com.ar/MLA-729121617-bc-337-bc-337-bc337-transistor-npn-nxp-45v-08a-pack-x-3-_JM) | $608,00 | $1.824,00 | FALSE | TRUE | FALSE | Mercado Libre | -
TRUE | 1 | Plaquetas para circuitos (10x10, 10x5, 20x20 y 5x5) | CLICK (https://radian.com.ar/web/) | $2.845,65 | $2.845,65 | FALSE | TRUE | FALSE | Electrónica Radián | -
TRUE | 1 | Dominio "aeroalert.com.ar" | CLICK (https://nic.ar/) | $855,00 | $855,00 | FALSE | TRUE | FALSE | nic.ar | -
TRUE | 1 | Plaquetas para circuitos (10x10, 10x5, 20x20 y 5x5) (http://aeroalert.com.ar/) | CLICK (https://radian.com.ar/web/) | $2.785,65 | $2.785,65 | FALSE | TRUE | FALSE | Electrónica Radián | -
TRUE | 1 | Plaquetas para circuitos (10x10, 20x20 y 5x5) (http://aeroalert.com.ar/) | CLICK (https://radian.com.ar/web/) | $4.985,65 | $4.985,65 | FALSE | TRUE | FALSE | Electrónica Radián | -
TRUE | 1 | Pack x5 transistores BJT 2SB624 PNP SMD Sot-23 (http://aeroalert.com.ar/) | CLICK (https://articulo.mercadolibre.com.ar/MLA-928831291-5x-2sb624-marcado-bv4-transistor-pnp-30v-17a-sot23-_JM) | $963,56 | $963,56 | FALSE | TRUE | FALSE | Mercado Libre | -
TRUE | 1 | Transistor MOSFET Canal N BSH SMD Sot-23 (http://aeroalert.com.ar/) | CLICK (https://articulo.mercadolibre.com.ar/MLA-709287423-bsh-103-bsh-103-bsh103-transistor-mosfet-n-sot23-_JM) | $865,00 | $865,00 | FALSE | TRUE | FALSE | Mercado Libre | -
TRUE | 1 | Pack x20 capacitores 100nf SMD encapsulado 0805 | CLICK (https://articulo.mercadolibre.com.ar/MLA-759071956-20x-capacitorsmd-0805-100nf-10-50v-104k-x7r-cl21b104kbcnnn-_JM) | $1.431,00 | $1.431,00 | FALSE | TRUE | FALSE | Mercado Libre | -
TRUE | 2 | Relé 5V Simple inversor | CLICK (https://articulo.mercadolibre.com.ar/MLA-740724363-rele-5v-simple-inversor-contactos-de-10a-220v-nubbeo-_JM) | $1.244,00 | $2.488,00 | FALSE | TRUE | FALSE | Mercado Libre | -
TRUE | 1 | Placa de cobre virgen 20x20 cm (resina epoxi) | CLICK (https://radian.com.ar/web/) | $5.600,00 | $5.600,00 | FALSE | TRUE | FALSE | Electrónica Radián | -
TRUE | 2 | Kit x5 llave palanca (3 pines) | CLICK (https://articulo.mercadolibre.com.ar/MLA-745522981-kit-x-5-llave-palanca-simple-switch-on-on-3a-250v-_JM) | $3.490,00 | $6.980,00 | FALSE | TRUE | FALSE | Mercado Libre | -
TRUE | 4 | Relé Simple inversor (5V-10A) | CLICK (https://articulo.mercadolibre.com.ar/MLA-927639709-rele-relay-5v-dc-simple-inversor-10a-220v-arduino-hobb-_JM) | $1.728,00 | $6.912,00 | FALSE | TRUE | FALSE | Mercado Libre | -
TRUE | 2 | Pack x5 diodos rectificadores | CLICK (https://articulo.mercadolibre.com.ar/MLA-904528470-pack-5-diodo-rectificador-1n4001-1a-50v-arduino-hobbytronica-_JM) | $1.235,00 | $2.470,00 | FALSE | TRUE | FALSE | Mercado Libre | -
TRUE | 5 | Borneras PCB 2x1 Smm | CLICK (https://articulo.mercadolibre.com.ar/MLA-1106799423-terminal-conector-pcb-2x1-5mm-calidad-electronica-hobb-_JM) | $2.187,00 | $10.935,00 | FALSE | TRUE | FALSE | Mercado Libre | -
TRUE | 1 | Cables para protoboard Hembra - Hembra x40 | CLICK (https://articulo.mercadolibre.com.ar/MLA-661946678-cables-para-protoboard-hembra-hembra-20cm-40unidades-arduino-_JM) | $1.200,00 | $1.200,00 | FALSE | TRUE | FALSE | Mercado Libre | -
TRUE | 2 | Display barras Led 10 segmentos color rojo | CLICK (https://articulo.mercadolibre.com.ar/MLA-1161021649-display-led-barras-indicador-dip-10-segmentos-rojo-hobb-_JM) | $1.673,00 | $3.346,00 | FALSE | TRUE | FALSE | Mercado Libre | -
TRUE | 1 | Malla Loop Apple Watch 38 mm | CLICK (https://articulo.mercadolibre.com.ar/MLA-919663187-malla-metalica-loop-para-apple-watch-de-38mm-40mm-42mm-44mm-_JM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) | $5.980,00 | $5.980,00 | FALSE | TRUE | FALSE | Mercado Libre | -
TRUE | 1 | Pack x5 tira de 40 pines hembra 2.54 mm | CLICK (https://articulo.mercadolibre.com.ar/MLA-641854544-pack-x-5-tira-de-40-pines-hembra-paso-254mm-arduino-_JM) | $1.686,00 | $1.686,00 | FALSE | TRUE | FALSE | Mercado Libre | -
TRUE | 2 | Tira de 40 pines macho 90° | CLICK (https://articulo.mercadolibre.com.ar/MLA-732456359-tira-de-pines-macho-1x40-254mm-90-grados-arduino-_JM) | $822,00 | $1.644,00 | FALSE | TRUE | FALSE | Mercado Libre | -
TRUE | 1 | Selector con llaves 2 posiciones Keylock On/Off | CLICK (https://articulo.mercadolibre.com.ar/MLA-1311959311-selector-con-llaves-2-posiciones-keylock-switch-onoff-pc-_JM) | $2.455,00 | $2.455,00 | FALSE | TRUE | FALSE | Mercado Libre | -
TRUE | 1 | Ojo de buey rojo 12V | CLICK (https://articulo.mercadolibre.com.ar/MLA-898941925-ojo-de-buey-led-rojo-tablero-12v-22mm-indicador-led-rojo-_JM) | $5.006,00 | $5.006,00 | FALSE | TRUE | FALSE | Mercado Libre | -
TRUE | 1 | Ojo de buey amarillo 12V | CLICK (https://articulo.mercadolibre.com.ar/MLA-898953384-ojo-de-buey-led-amarillo-tablero-12v-22mm-indicador-led-_JM) | $5.006,00 | $5.006,00 | FALSE | TRUE | FALSE | Mercado Libre | -
TRUE | 1 | Servicio de ploteado placas MDF 9mm via láser | CLICK (https://articulo.mercadolibre.com.ar/MLA-1362379463-pulsador-retorno-de-resorte-22mm-1-na-schneider-xa2ea21-_JM) | $48.000,00 | $48.000,00 | FALSE | TRUE | FALSE | Mercado Libre | -
TRUE | 1 | Pack x5 interruptor dip switch 1 via | CLICK (https://articulo.mercadolibre.com.ar/MLA-759074811-pack-x-5-interruptor-mini-dip-switch-1p-dip-254mm-_JM) | $1.384,00 | $1.384,00 | FALSE | TRUE | FALSE | Mercado Libre | -
TRUE | 2 | Batería 9V | CLICK (https://radian.com.ar/web/) | $2.200,00 | $4.400,00 | FALSE | FALSE | FALSE | Electrónica Radián | -
TRUE | 2 | Lijas para madera | CLICK (https://ferreteriasanmartin.com.ar/) | $400,00 | $800,00 | FALSE | TRUE | FALSE | Ferretería San Martín (ferreteriasanmartin.com.ar) | -
TRUE | 3 | Brillosparay Max Negro | CLICK (https://www.colorshop.com.ar/) | $3.350,00 | $10.050,00 | FALSE | TRUE | FALSE | Colorshop (https://www.colorshop.com.ar/) | -
TRUE | 3 | Capuchones para pilas | CLICK (https://radian.com.ar/web/) | $500,00 | $1.500,00 | FALSE | FALSE | FALSE | Electrónica Radián | -
TRUE | 2 | Batería 9V | CLICK (https://radian.com.ar/web/) | $2.200,00 | $4.400,00 | FALSE | FALSE | FALSE | Electrónica Radián | -
FALSE | 1 | Cable micro USB | - | - | - | TRUE | FALSE | FALSE | - | Sergio Medina
TRUE | 1 | Pulsador Rasante 22mm | CLICK (https://articulo.mercadolibre.com.ar/MLA-1362379463-pulsador-retorno-de-resorte-22mm-1-na-schneider-xa2ea21-_JM) | $3.399,00 | $3.399,00 | FALSE | TRUE | FALSE | Mercado Libre | -
TRUE | 1 | Placa de Desarrollo ESP32 NodeMCU | CLICK (https://articulo.mercadolibre.com.ar/MLA-880524284-placa-nodemcu-esp32-wifi-bluetooth-dual-coret-_JM) | $9.999,00 | $9.999,00 | FALSE | TRUE | FALSE | Mercado Libre | -
TRUE | 2 | Sensor digital Max30102 | CLICK (https://articulo.mercadolibre.com.ar/MLA-881599272-sensor-de-pulso-cardiaco-y-oxigeno-max30102-arduino-nubbeo-_JM) | $4.257,00 | $8.514,00 | FALSE | TRUE | FALSE | Mercado Libre | -
TRUE | 1 | Módulo de Carga TP4056 18650 | CLICK (https://articulo.mercadolibre.com.ar/MLA-1393425773-modulo-carga-generico-tp4056-protect-micro-usb-37v-1a-18650-_JM) | $670,00 | $670,00 | FALSE | FALSE | TRUE | Electrónica RC | -

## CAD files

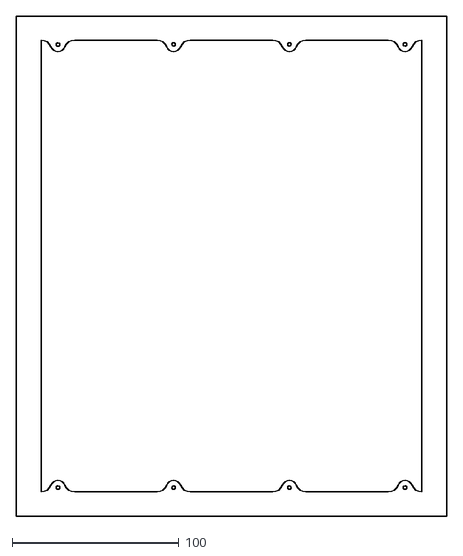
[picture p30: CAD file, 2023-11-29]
CAD/CNC Routing/AES/Part 1/C1 Main Case - Part 1.dxf
258.3 x 300.0

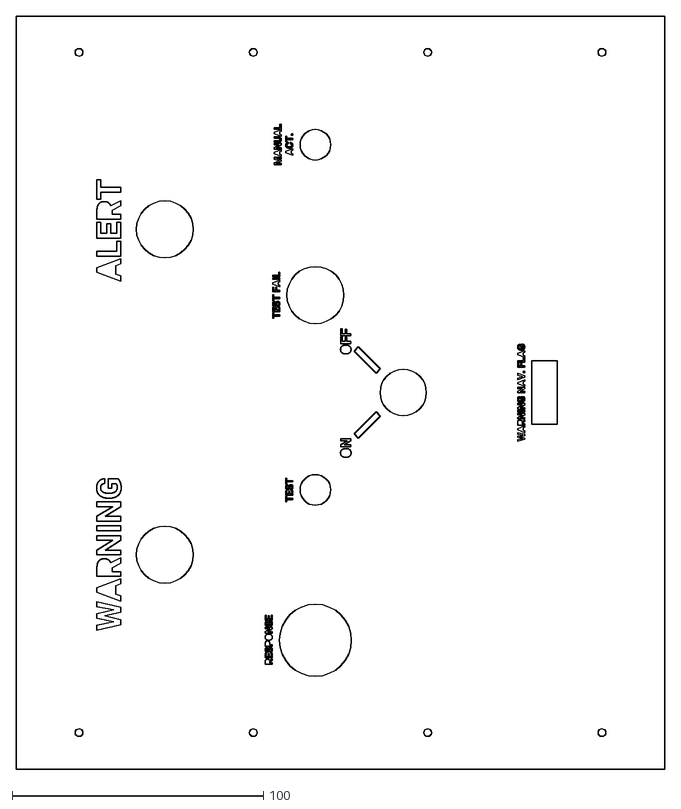
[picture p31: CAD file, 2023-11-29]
CAD/CNC Routing/AES/Part 4/C1 Main Case - Part 4.dxf
258.3 x 300.0

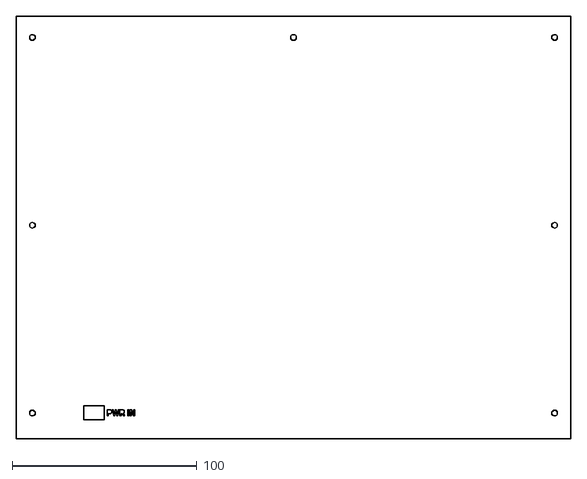
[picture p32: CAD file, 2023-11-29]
CAD/CNC Routing/AES/Part 5/C1 Main Case - Part 5.dxf
300.0 x 228.5

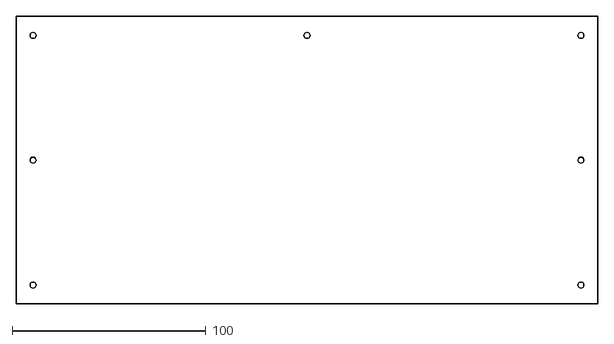
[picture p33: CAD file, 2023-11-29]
CAD/CNC Routing/AES/Part 6/C1 Main Case - Part 6.dxf
300.0 x 148.0

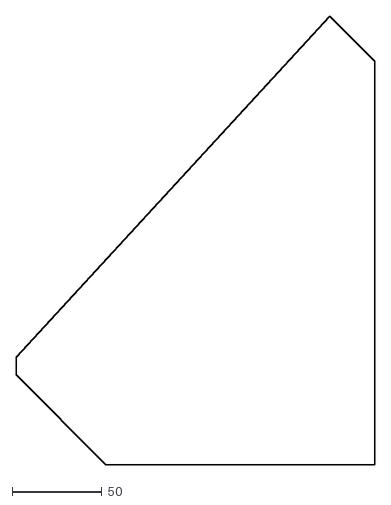
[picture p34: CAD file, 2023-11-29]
CAD/CNC Routing/AES/Part 1/C1 Main Case - Part 1-4.dxf
200.0 x 250.0

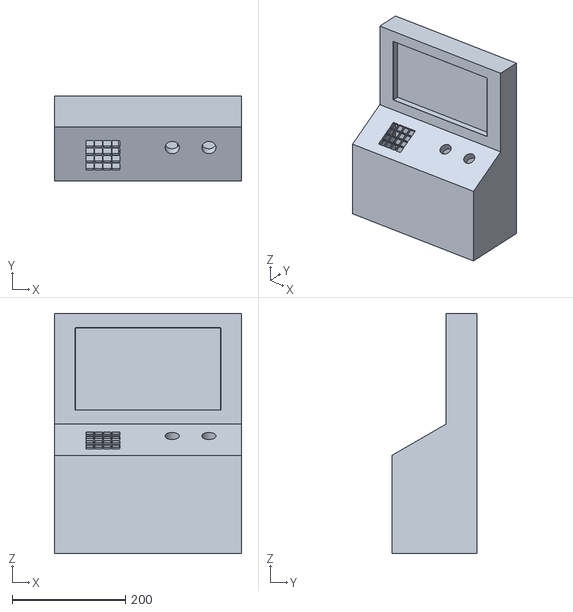
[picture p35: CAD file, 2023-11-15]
CAD/CTRT/CTRT - Main Struct.stl
330.0 x 150.0 x 423.0

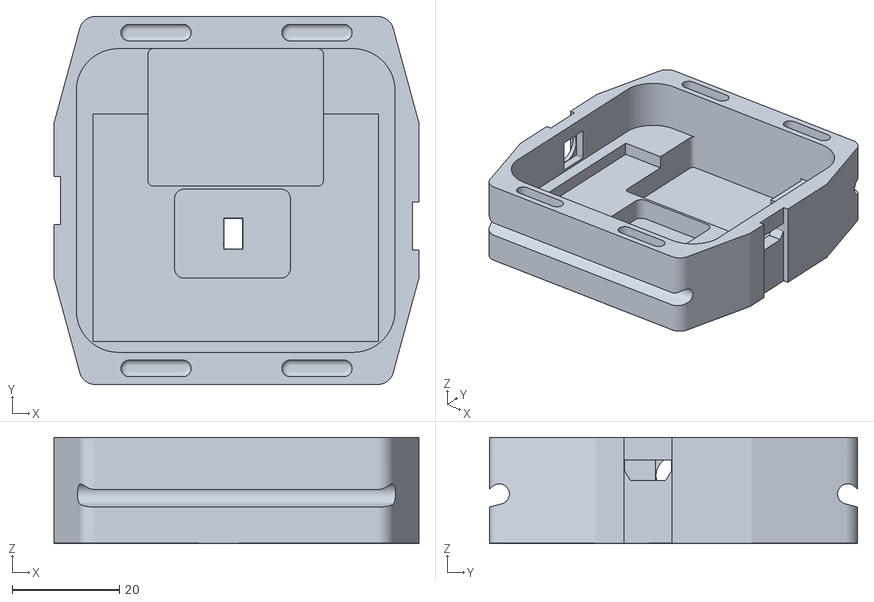
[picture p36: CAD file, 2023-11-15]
CAD/VDB/VDB - Main Struct.stl
68.0 x 68.6 x 19.8

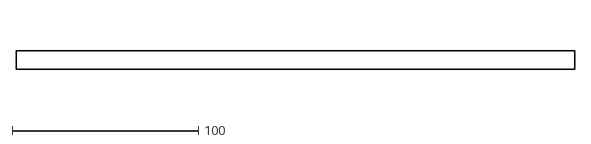
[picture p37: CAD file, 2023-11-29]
CAD/CNC Routing/AES/Part 1/C1 Main Case - Part 1-5.dxf
300.0 x 10.0

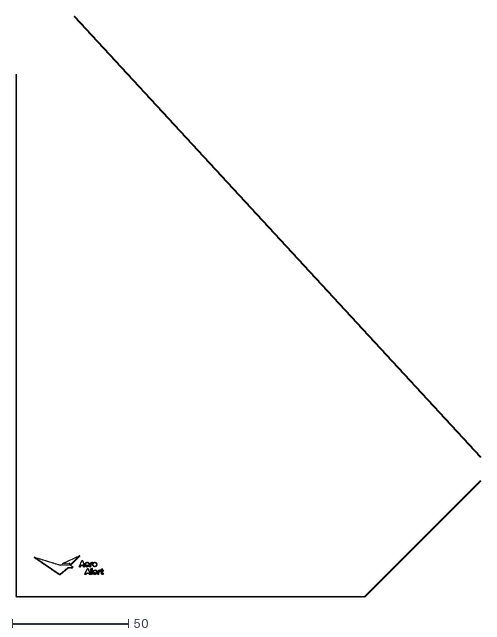
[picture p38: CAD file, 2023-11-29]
CAD/CNC Routing/AES/Part 1/C1 Main Case - Part 1-2.dxf
200.0 x 250.0

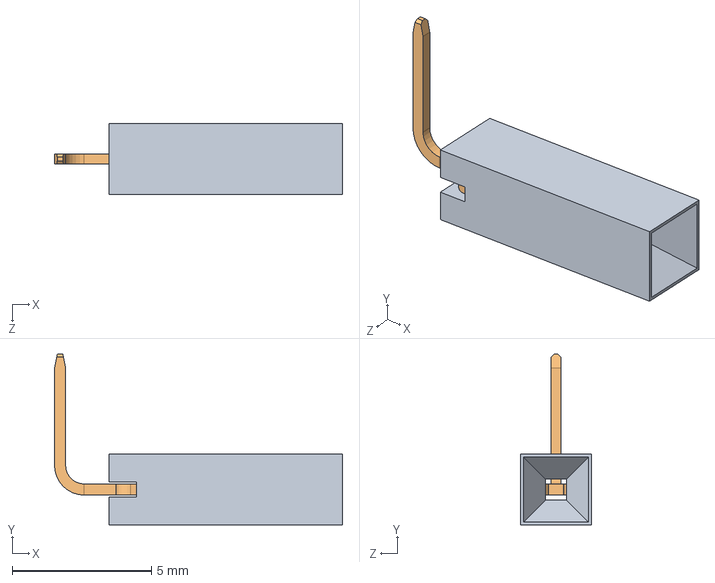
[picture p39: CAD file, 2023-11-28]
CAD/STEP Templates/FrameAndPin_H254_90deg.sldasm
10.4 x 6.14 x 2.54 mm
frame_H254
pin-90deg

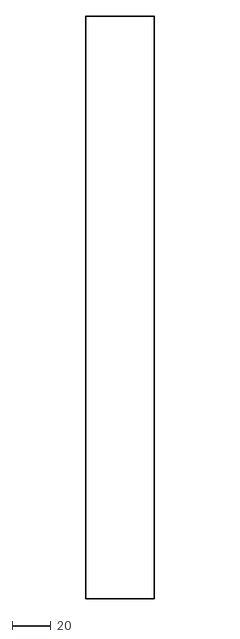
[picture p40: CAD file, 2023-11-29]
CAD/CNC Routing/AES/Part 1/C1 Main Case - Part 1-3.dxf
35.4 x 300.0

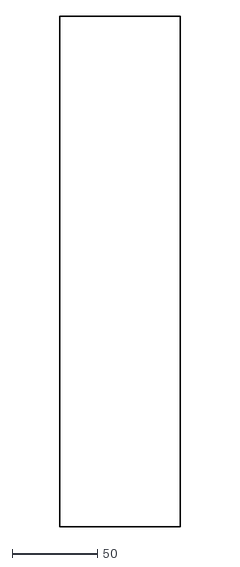
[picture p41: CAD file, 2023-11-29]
CAD/CNC Routing/AES/Part 1/C1 Main Case - Part 1-6.dxf
70.7 x 300.0

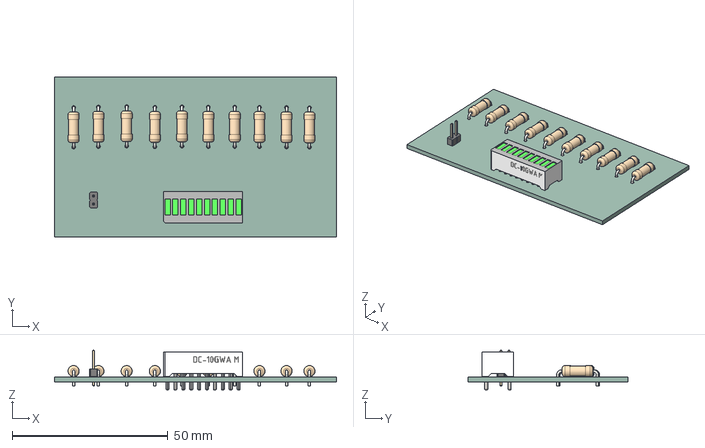
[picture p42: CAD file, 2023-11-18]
CAD/AES/A.E.S - STEP File.step
90.7 x 51.4 x 12.7 mm
PCB

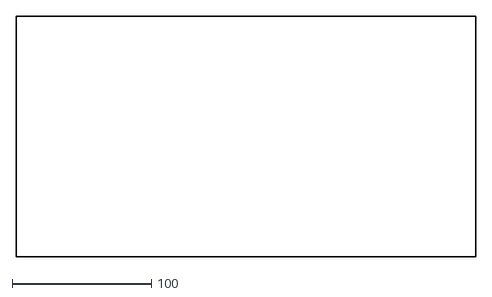
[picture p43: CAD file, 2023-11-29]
CAD/CNC Routing/CTRT/Part 1/Part Studio 1 - Part 1-6.dxf
330.0 x 173.0

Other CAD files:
CAD/CNC Routing/CTRT/Part 3/Part Studio 1 - Part 3.dxf
CAD/CNC Routing/Plancha 120 x 80 cm.dxf
CAD/CTRT/CTRT - Keycaps.stl
CAD/STEP Templates/10-segment-linear-display-1/Display_10SegBlue.SLDPRT
CAD/CNC Routing/CTRT/Part 1/Part Studio 1 - Part 1-2.dxf
CAD/CNC Routing/CTRT/Part 1/Part Studio 1 - Part 1-3.dxf
CAD/CNC Routing/CTRT/Part 1/Part Studio 1 - Part 1-4.dxf
CAD/CNC Routing/CTRT/Part 1/Part Studio 1 - Part 1-5.dxf
CAD/CNC Routing/CTRT/Part 1/Part Studio 1 - Part 1-7.dxf
CAD/CNC Routing/CTRT/Part 1/Part Studio 1 - Part 1.dxf
CAD/STEP Templates/10-Pin Header - Female - 2.54mm.step
CAD/STEP Templates/10-Pin Header - Male - 2.54mm.step
CAD/STEP Templates/10-segment-linear-display-1/Display_10Seg.SLDPRT
CAD/STEP Templates/10-segment-linear-display-1/Display_10Seg.STEP
CAD/STEP Templates/10-segment-linear-display-1/Display_10SegRed.SLDPRT
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

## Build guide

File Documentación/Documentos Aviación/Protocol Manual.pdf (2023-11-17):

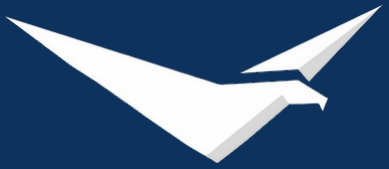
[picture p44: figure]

# PROTOCOL MANUAL

# For pilots and air traffic controllers

# AeroAlert Project

# INDEX

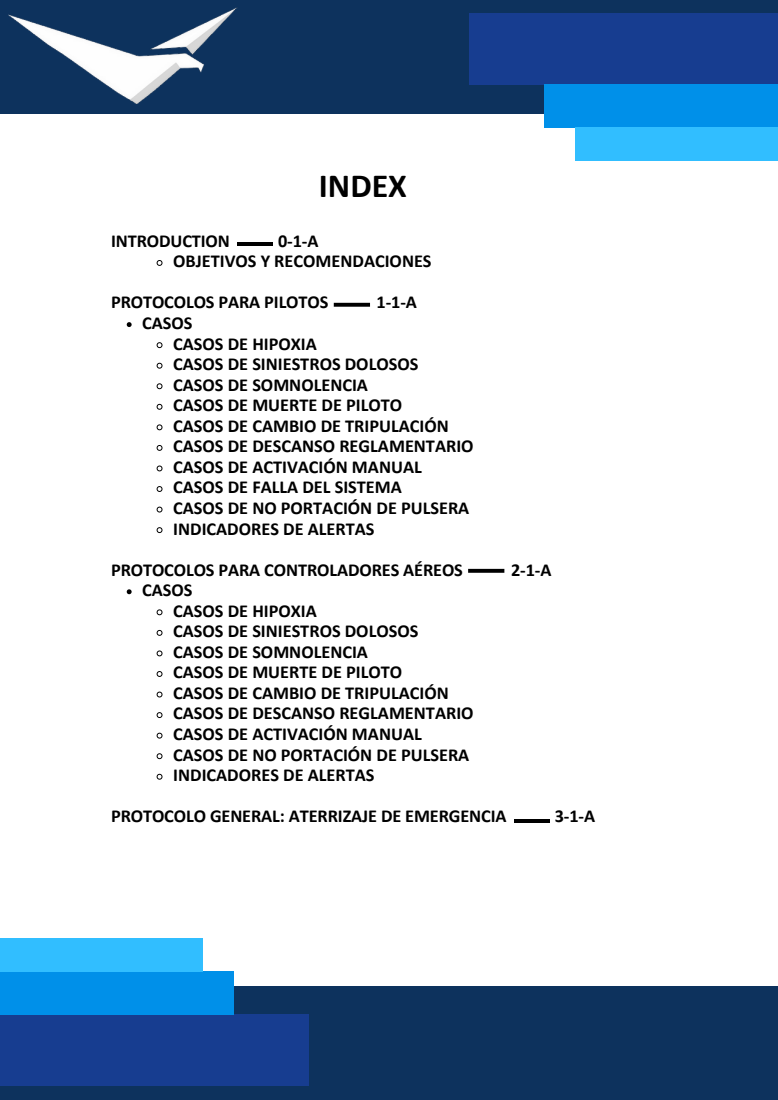
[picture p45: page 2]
OBJETIVOS Y RECOMENDACIONES; INTRODUCTION; PROTOCOLOS PARA PILOTOS; PROTOCOLOS PARA CONTROLADORES AÉREOS; PROTOCOLO GENERAL: ATERRIZAJE DE EMERGENCIA

CASOS
CASOS DE HIPOXIA
CASOS DE SINIESTROS DOLOSOS
CASOS DE SOMNOLENCIA
CASOS DE MUERTE DE PILOTO
CASOS DE CAMBIO DE TRIPULACIÓN
CASOS DE DESCANSO REGLAMENTARIO
CASOS DE ACTIVACIÓN MANUAL
CASOS DE FALLA DEL SISTEMA
CASOS DE NO PORTACIÓN DE PULSERA
INDICADORES DE ALERTAS

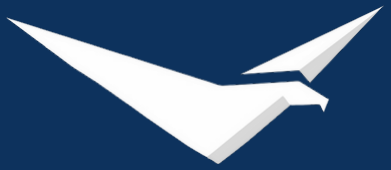
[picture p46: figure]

## Recommendations

0-1-A

# INTRODUCTION

CASES OF HYPOXIA
CASES OF INTENTIONAL ACCIDENTS CASES OF SOMNOLENCE
CASES OF PILOT'S DEATH
CASES OF CREW CHANGES
CASES OF REGULATORY REST
CASES OF SYSTEM FAILURE
CASES OF MANUAL ACTIVATION CASES OF NOT WEARING A WRISTBAND

Strict adherence to the protocols set forth in this document is strongly recommended to ensure satisfactory emergency operations, thus avoiding potential undesirable consequences.

Both pilots and air traffic controllers must rationally take into account the dimension of the situation that it presents, understand their responsibilities and competencies, as well as the consequences of their actions.

This manual has been prepared with the purpose of providing a reference, both for pilots and air traffic controllers, that will allow them to act satisfactorily given the functionalities of the ICERS system in the corresponding in-flight emergency situations covered by the aforementioned system.
The respective cases reached by ICERS and, as a consequence, with sufficient usefulness to be mentioned and analyzed in this document, are:

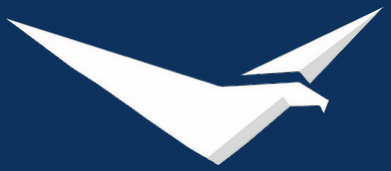
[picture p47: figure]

## Hypoxia Cases

1-1-A

# PROTOCOLS FOR PILOTS

When this condition is met, pilots must put on their oxygen masks and continue establishing contact with the corresponding A.T.C.

Hypoxia events warrant both manual activation (if symptoms are noticeable) and automatic activation (via the wrist device). It is recommended to reserve manual activation for situations in which the system is not able to protect.

In this section, we proceed to define the action protocols corresponding to pilots in cases covered by the ICERS system.
As previously mentioned, it is strongly recommended to strictly follow the procedures described in this document, in order to guarantee their effectiveness, as well as a satisfactory resolution to certain in-flight emergency situations.

By definition, in the event that the bracelet registers a blood oxygen saturation of less than 90% in the pilot and copilot, an alert will be provided in the cockpit, as well as to the A.T.C.

In the event that pilots feel that they are unable to continue the flight optimally due to the effects of hypoxia, they may activate the ICERS system manually or automatically with the bracelet, after due contact with the A.T.C., whether such activation is transient (pending recovery of their capabilities) or permanent under the condition that the effects suffered are such that the pilots are unable to continue the flight.

## Cases of fraudulent claims

## Cases of Sleepiness

1-2-A

In case the attack is perpetuated by a passenger (or group of them), pilots may communicate with the A.T.C., and wait for an activation of the Automatic Emergency System, or place the hijack code on the Transponder, in order to activate the same
system.

The recommended procedure is, first of all, to place the hijack code in the Transponder, and then to establish communication with the A.T.C. so that it can be established.

The initial response to cases of this nature, if it is only one pilot, will be the activation of a light in the cockpit, so that the pilot and/or third parties in question recognize the pilot's Sleepiness. After this, the pilot, by his own or third party means, will have to wake up and press the reaction button.

After an event of this category, the only way to generate an emergency response is for the A.T.C. to become aware of the situation and thus activate the Automatic Emergency System.
If the incident is caused by a crew member(s), contact the ground as soon as possible.

In case both pilots are in the same situation, the amber light in the cockpit and an alarm will be activated and a warning will be sent to the A.T.C. A maximum reaction time of 30 seconds will be contemplated for this specific situation, after which, if the reaction button has not been pressed, both pilots will be considered in a state of unconsciousness.
If the drowsy condition affects only one of the pilots, there is no emergency, it
is an alert.

## Cases of pilot death

## Crew change cases

1-3-A

Upon the death of a pilot the A.E.S. will detect it, and an amber light will be lit in the cockpit and the A.T.C. will be notified of the event.

If the crew change protocol is required during a flight, the buttons on the bracelet must be held down to execute the change.

After the procedure has been enabled, a 40-second period will be allowed for the changeover, at which time the previous crew must transfer their wristbands to the new crew.

In the event that both pilots are lifeless, the system will alert the A.T.C., and will turn on an amber light in the cockpit with a specific audible alert.

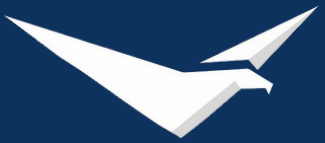
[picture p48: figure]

## System failure cases

## Statutory rest cases

1-4-A

In case of obvious failures in the ICERS system, either due to erroneous measurements of the wristbands or communication problems with the A.T.C., it is strongly recommended to deactivate the system, thus avoiding erroneous messages to the A.T.C.
If you notice that your wristband is malfunctioning, you may notify the
A.T.C. of such situation, after which it is recommended to proceed with its deactivation.

System failures can be determined in flight if there is an alert in the cockpit that has no correlation with the events taking place in the cockpit, or if the warning flag is
activated. The first case mentioned will determine that the failure is in the bracelet and/or its data reading system. The second case will indicate another type of technical failure, related to the power supply of the equipment, or in case of being out of range of any C.T.A.
To deactivate the system, the corresponding key must be connected to the override switch of the Automatic Emergency System.

On occasions in which the pilot wishes to use his regulatory rest, he should press the button to set his bracelet in rest mode, so as not to have any inconvenience.
If his rest is authorized, the pilot will have a period of 20 minutes in which his bracelet will not detect his low cardiac activity as a case of Sleepiness, although the bracelet will remain functional.
After 20 minutes, the system will resume its functions normally, and the pilot will have to wait a few minutes to be able to make another request within the same aircraft. It should be noted that only one pilot at a time will be able to activate this mode of operation, and only once per flight.

It is recommended to use 15 of the 20 minutes of the process for rest, allocating the
remaining 5 minutes to the recovery of the capabilities, thus preventing the bracelet
from taking erroneous and/or unwanted measurements.

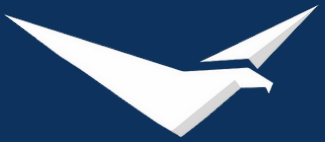
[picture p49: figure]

## Cases of non-wearing of bracelets

## Manual activation cases

## Alert indicators

1-5-A

Amber color: indicates unconsciousness, Sleepiness, death, not wearing a bracelet and high or low pulse rate.

In the aircraft cockpit, alerts will be displayed by means of light indicators under the following coding:

In case pilots are not wearing their bracelets, or are not wearing them correctly, they will be alerted with an amber light in the cockpit, warning of the lack of connection/incorrect connection of the bracelet.
The notice will be generated from the corresponding T.C.A.

Red color: indicates hypoxia conditions, manual activation and C.T.A. activation.

Manual activation is understood as a protocol of last resort. Therefore, it is
recommended only when the equipment does not have enough tools to give an alert by its own means, or if it is unable to generate alerts due to a failure.
Should such a situation occur, proceed by pressing the manual activation button, after which the Automatic Emergency System will be activated immediately.

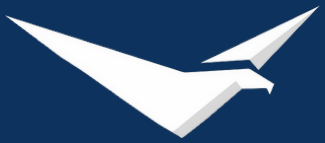
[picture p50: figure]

## Hypoxia Cases

2-1-A

# PROTOCOLS FOR AIR TRAFFIC CONTROLLERS

When a case of cabin hypoxia occurs, an emergency alarm will be activated and a red light will be illuminated in the air traffic control office. The A.T.C. shall immediately contact the aircraft by radio. In principle, it should be corroborated that the measurement given is real.

In this section, the emergency action protocols corresponding to air traffic controllers are defined, given the emergency cases covered by the ICERS system.
As previously mentioned, it is strongly recommended to strictly follow the procedures described in this document, in order to guarantee their effectiveness, as well as a satisfactory resolution to certain in-flight emergency situations.

After the A.T.C. contact with the crew, the pilots will return an answer or not according to the state of consciousness in which they are due to the effects of hypoxia. In case of answering, the veracity of the measurements will be corroborated. If this condition is met, an emergency landing will be made.
In case the pilots do not answer the A.T.C.'s query, it will be declared that they are not in optimal conditions to fly the aircraft after 3 unsuccessful attempts. Subsequently, a general unconsciousness alarm will be activated, and an emergency landing will be made, activating the automatic emergency system from the control tower.

## Cases of fraudulent claims

## Cases of Sleepiness

2-2-A

It is recommended to try to communicate with the aircraft in any case, mainly for safety reasons.

In cases of this nature, the air traffic controller must contact the aircraft immediately upon any indication that the aircraft is damaged, or in such process, if such suspicion is affirmed (either through the Transponder system, or via direct communication with the pilot), the Automatic Emergency System is activated remotely and, consequently, an emergency landing begins to be organized.
In cases of manual activation, system deactivation, death of one or both pilots, route deviations, deactivation of the Transponder and/or other communication systems and calls by the crew, the aircraft must always be marked as a possible hijack suspect, after which all its movements must be monitored.

In the event of Sleepiness, the air traffic controller will receive an audible alert and an amber light will turn on if both pilots are drowsy.
After such a stimulus, the A.T.C. shall contact the aircraft and wait for the pilots to wake up, giving a maximum response time of 40 seconds. In the affirmative case, the protocol will not entail any further action, but the aircraft should be monitored given the
potential fatigue of the pilots. In the negative case, an audible alarm and a red light will be activated at the air traffic office.
In the event that one of the pilots does not wake up, he/she will be classified as unconscious, after which the air traffic controller will contact his/her partner on board to make an emergency landing.

If no response is received from any of the pilots, the ICERS system itself will request
commands to the A.T.C. to perform the emergency landing.

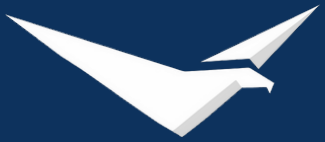
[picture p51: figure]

## Cases of pilot death

## System failure cases

2-3-A

In the event of system failures, the A.T.C. may be in a position to receive erroneous values and alerts for a given flight. For this reason, in any case, the A.T.C. must communicate with the aircraft in conflict to verify the veracity of the information received.
In the event that the information provided constitutes a system error, the air traffic controller may authorize the deactivation of the ICERS system taking into account the magnitude and severity of the errors present.

In case of death of both pilots, a red light and an audible alarm will be activated. In this case, the aircraft must be contacted and an emergency landing must be made.

In the event of a pilot's death, notification will be given by activation of an audible alarm and a warning light to notify.
The aircraft should be contacted immediately, in principle to verify the information received. If so, proceed with the execution of an emergency landing.

## Cases of non-wearing of bracelets

## Manual activation cases

## Alert indicators

2-4-A

Red color: for emergencies

Amber color: for alerts and warnings

In case of detecting the non-wearing (or incorrect wearing) of the corresponding bracelet, the air traffic control will be notified through the lighting of an amber light indicator in its office.
After such notice, the aircraft must be notified of the incorrect wristband.

In the control tower, the following arrangement of indicators is available to facilitate and optimize the understanding of the situation and its subsequent resolution:

When an aircraft manually activates the Automatic Emergency System, the air traffic controller in question will be notified by the lighting of a red indicator light in his control tower. In these cases, it is of utmost importance to contact the aircraft involved, in order to obtain details and reasons for the event.

3-1-A

# GENERAL PROTOCOL: EMERGENCY LANDING

It is important to note that the aircraft's A.E.S. will be in charge of sending the landing parameters sent from the CTRT to the aircraft's flight computer.

In order to send accurate commands to the A.E.S., the C.T.R.T. must take several
factors into account. First, the model of the aircraft in question must be known, since each model has its own characteristics and flight requirements. It must also consider nearby airports that may be suitable for an emergency landing and the maneuvers necessary to reach them safely, taking into account the surrounding air traffic, as this affects the aircraft's ability to maneuver safely.

When an air traffic controller receives an alert from an aircraft, which corresponds to the cases previously seen, quick and effective measures must be taken to ensure a safe emergency landing. Once the veracity of the alert has been verified, the air traffic controller should approach the C.T.R.T. and send commands to the aircraft's Automatic Emergency System for the aircraft to perform the necessary maneuvers.

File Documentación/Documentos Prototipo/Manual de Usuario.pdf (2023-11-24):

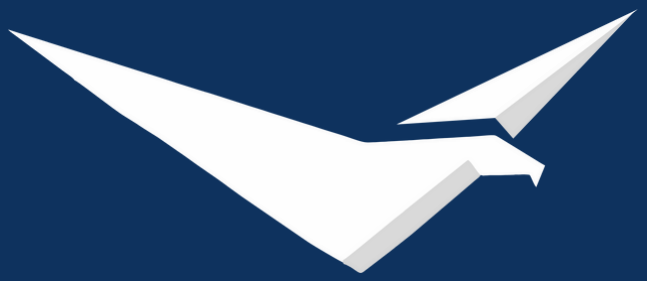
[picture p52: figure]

# MANUAL DE USUARIO

# Proyecto AeroAlert

# Índice

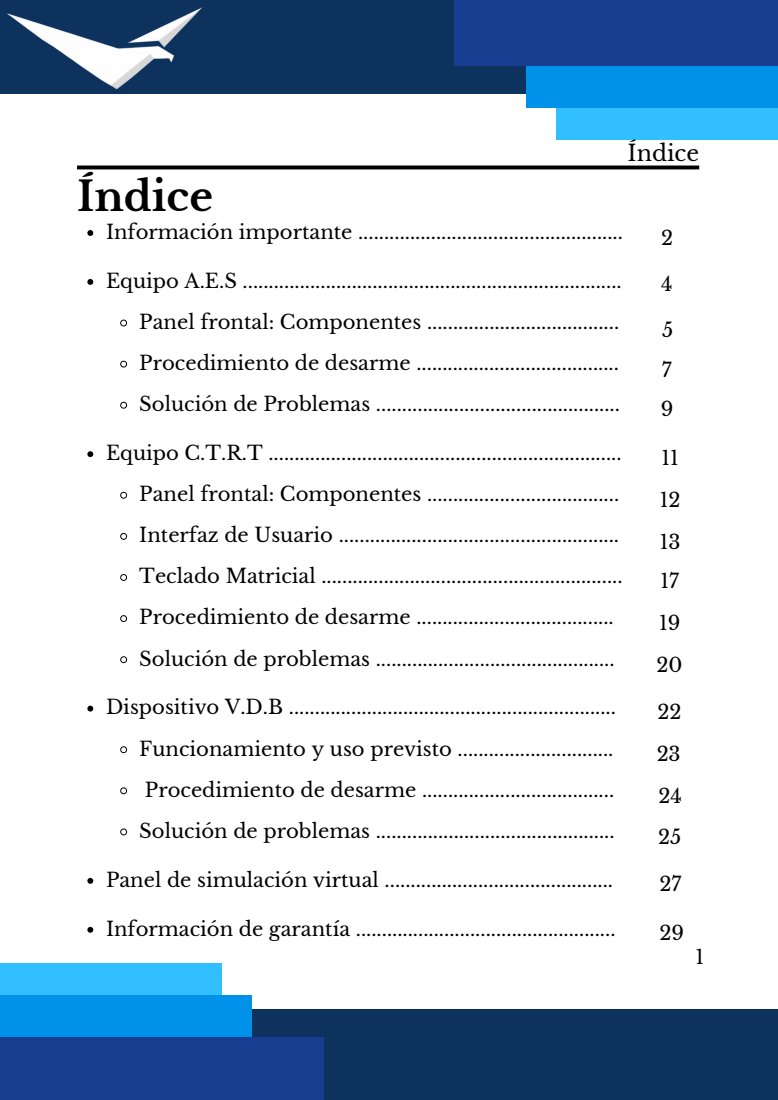
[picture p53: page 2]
Información importante ...................................................; Índice

Equipo A.E.S .........................................................................
Panel frontal: Componentes .....................................
Procedimiento de desarme .......................................
Solución de Problemas ...............................................

Equipo C.T.R.T ....................................................................
Interfaz de Usuario ......................................................
Teclado Matricial ..........................................................
Procedimiento de desarme ......................................
Solución de problemas ..............................................

Dispositivo V.D.B ...............................................................
Funcionamiento y uso previsto ..............................
Procedimiento de desarme .....................................

Panel de simulación virtual ............................................

Información de garantía ..................................................

### PRECAUCIÓN

Desde ya, AeroAlert agradece su confianza a la hora de adquirir el producto. Nuestro sistema proveerá de dispositivos y equipamiento aeronáutico para el monitoreo de la situación en cabina en función de parámetros asociados a las condiciones de salud del piloto.

Este manual abarca una enumeración de todas las piezas del producto, acompañadas de explicaciones técnicas para cada componente, así como los procedimientos que se deben seguir en relación con la operación del sistema con el objetivo de un manejo satisfactorio por parte del usuario. El presente manual detalla a su vez los correctos criterios de utilización, mantenimiento y solución de problemas con el fin de proteger al

usuario y el equipamiento incluido.

Este manual proporciona explicaciones técnicas respectivas al funcionamiento del sistema ICERS II. Recomendamos encarecidamente la lectura de los otros manuales, incluyendo Manual de Usuario, Guía de Piloto y Guía de C.T.R.T., antes de proceder a la utilización del producto. De lo contrario, existe un riesgo potencial para con su vida y la de terceros.

Es importante tener en cuenta que no se aceptan devoluciones por daños causados a los equipos debido a un uso inadecuado. Se recomienda encarecidamente utilizar el cargador proveído en la compra para alimentar el dispositivo V.D.B.

# Información importante

2

En caso de requerir asistencia, puede ponerse en contacto a través de nuestra página web aeroalert.com.ar o por medio de la dirección de correo electrónico proyectoaeroalert@gmail.com.

## Productos y accesorios incluidos

Manual de Usuario del sistema ICERS Guía de Piloto
Guía de C.T.R.T.
Dispositivo V.D.B.
Equipo A.E.S.
Equipo C.T.R.T.
Cargador de 20W para el dispositivo V.D.B. Software de simulación virtual

La adquisición del producto en cuestión incluye con su respectiva compra los siguientes elementos:

Se sugiere revisar la inclusión de los componentes previamente listados a la hora de recibir el sistema. En el caso de faltante de elementos, material informativo o desperfectos, el usuario tiene derecho a efectuar reclamos de cambio o devolución con reintegro económico completo.

AeroAlert se reserva todos los derechos sobre la publicación y distribución del presente documento.

3

Equipo A.E.S.

## Especificaciones

Equipo A.E.S.

4

El equipo A.E.S cumple la función de procesar la información recibida de la instrumentación sensórica, con el propósito de transmitir alertas en cabina y hacia el equipo en tierra.

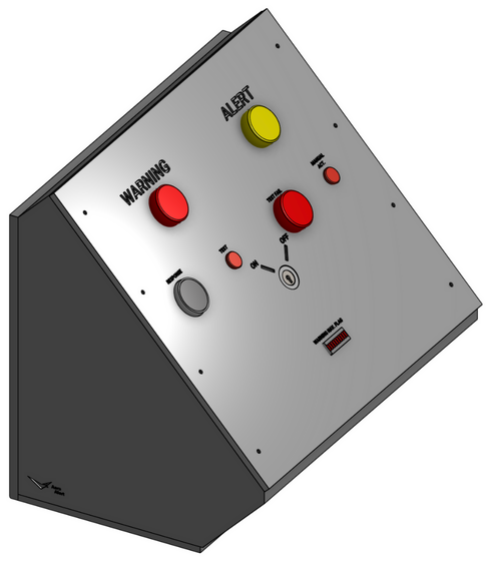
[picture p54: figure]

La disposición de componentes para la correcta representación visual y frontal de información se encuentra sujeta al ensamblaje en la respectiva carcasa del equipo, compuesta en un material de madera tipo MDF (espesor 9mm). La correspondiente imagen enseña las distintas aberturas asignadas a la luminaria del equipo, así como para los distintos interruptores relativos al ingreso manual de información e instrucciones inherente a la operación del equipo

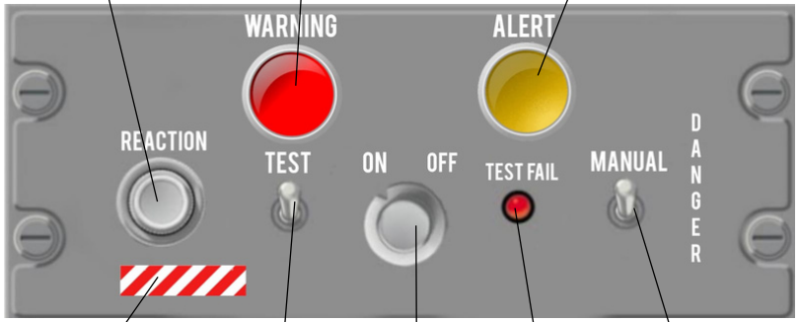
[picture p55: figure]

5

1 | 2 | 3
4 | 5 | 7 | 6 | 8

## Panel frontal.: Componentes

Equipo A.E.S.

REACTION: Refiere a un botón (de tipo pulsador sin retención mecánica) con la utilidad de generar el aviso de reconocimiento de alertas y capacidad de retomar normalmente las operaciones aéreas.

1.

El siguiente esquema enseña la topología de componentes del panel frontal del módulo AE.S, orientados tanto a la representación de alertas en vuelo como al ingreso manual de información e instrucciones.

Por medio de la nomenclatura numérica establecida en el esquema, se enseña, refiere y explica el componente asociado y su objetivo particular dentro del panel

WARNING: Luminaria indicadora en color rojo. Se activa en caso de presentarse emergencias en cabina (situaciones de inconsciencia por hipoxia, muerte de piloto y/o generación remota de instrucciones provenientes del control del tráfico aéreo)

ALERT: Luminaria indicadora en color ámbar, de activación sujeta a eventos en cabina que no
comprometan seriamente la integridad del vuelo (detección temprana de anomalías de salud del piloto o no portación de dispositivo de adquisición de datos).

WARNING NAVIGATION FLAG: Flag de advertencia del equipo A.E.S, con activación sujeta a la detección de casos de no recepción de señal C.T.R.T., falta de alimentación del equipo o pérdida de enlace con módulos C.T.R.T.

TEST: Switch dedicado a la inicialización de procesos de prueba del equipo. Cuenta con luminaria asociada para indicaciones de resultado de la prueba.

TEST FAIL: Luminaria asociada al interruptor de testeo previamente mencionado. Su activación es funcional a la detección de fallas.

SWITCH ON/OFF: Interruptor con funciones de permisión o anulación de la normal operación del equipo y sus funcionalidades.

MANUAL: Interruptor con funciones de activación manual de declaración de emergencia del equipo.
6

Equipo A.E.S.

7

## Procedimiento de desarme

Equipo A.E.S.

El procedimiento de desarme se encuentra detallado, para óptima comprensión del mismo, por medio de la siguiente imagen, a través de la cual se enseña una vista explotada del equipo, representando la ubicación y disposición tanto de componentes de representación externa, como aquellos presentes en la plaqueta madre y del flag de advertencia del circuito interno del módulo.

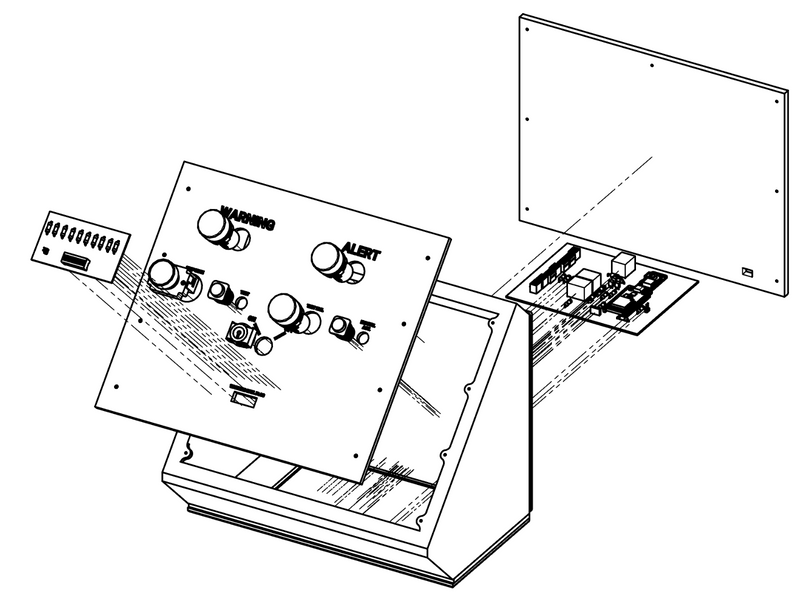
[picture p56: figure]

A fin de acceder al conexionado interno del equipo A.E.S, se sugiere remover la tapa trasera de la carcasa contenedora tal como enseña la imagen previa. De dicha forma, se reduce el contacto y rozamiento con circuitos y elementos conductores de los mismos. Posterior a ello, el usuario será capaz de acceder a las distintas plaquetas del equipo.

8

Equipo A.E.S.
En caso de requerirse intervención sobre el circuito del flag de advertencia, se deberá desmontar su correspondiente plaqueta, ajustada por medio de atornillamiento a la tapa frontal del módulo, según enseña la siguiente imagen. La segunda ilustración enseña la plaqueta del flag de advertencia desde una perspectiva isométrica.:

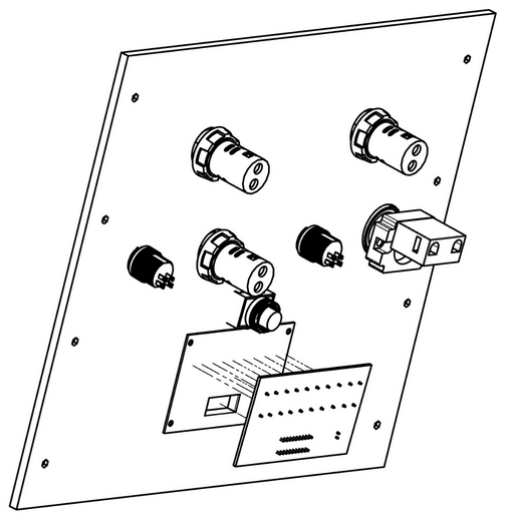
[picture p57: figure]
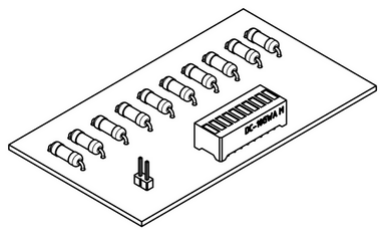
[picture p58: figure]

9

## Solución de problemas

Equipo C.T.R.T.

La siguiente sección sugiere una serie de procedimientos a ejecutar en caso de presentarse fallas en el funcionamiento del módulo A.E.S.. Los problemas más frecuentes a encontrar son:

La luminaria indicadora no se enciende tras recepción de alertas, o no se activan las alarmas sonoras:
Este tipo de casos pueden ocurrir principalmente debido a errores momentáneos de software y/o hardware (en este último caso, destacan potenciales falsos contactos entre componentes del circuito como principal factor). Para eventos de tal índole, se recomienda reiniciar el módulo. De persistir el inconveniente, contáctese con el fabricante: podría tratarse de una problemática que requiera de la intervención del servicio técnico. Si el artículo afectado se encuentra en garantía, el cliente tiene derecho a reclamar un reembolso o una reparación sin coste, así como la sustitución integra en caso de tratarse de un desperfecto crítico.

La luminaria indicadora se enciende o se activan las alarmas sonoras sin previa recepción de alertas:
En caso de ocurrir inconvenientes de este tipo (los cuales pueden surgir como consecuencia de desperfectos técnicos relacionados con el hardware y/o software del equipo), se recomienda proceder con el reinicio de la unidad, a fin de eliminar toda potencial falla ocasional que atente contra el

10

Equipo C.T.R.T.
correcto funcionamiento de la misma.
Si el inconveniente persiste, se deberá desactivar la unidad en su totalidad y contactar inmediatamente con el fabricante, notificando la decisión al control del tráfico aéreo. Si el producto se encuentra dentro de su garantía, el usuario tiene el derecho a reclamar un reembolso o una reparación sin coste alguno, así como una sustitución de la unidad en caso de la existencia de fallas críticas.

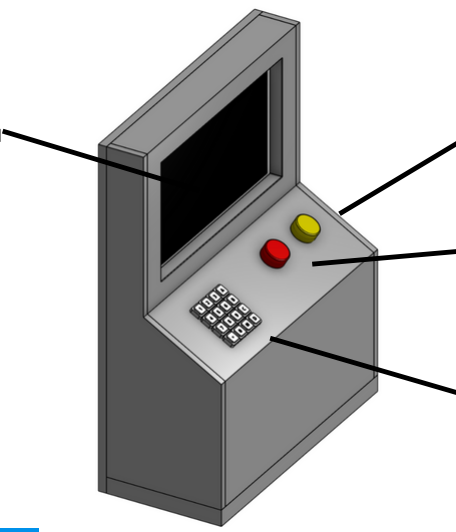
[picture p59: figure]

4

1

2

3
11

Equipo C.T.R.T.
Equipo C.T.R.T.

## Especificaciones

El equipo C.T.R.T. tiene como función objetivo el establecimiento de enlace para con módulos A.E.S circundantes, permitiendo así un seguimiento externo de la situación en cabina y el envío de instrucciones de maniobra en caso de ser estas requeridas. Se encuentra planeada su ubicación en tierra, a disposición del control del tráfico aéreo.

El acabado estructural del módulo C.T.R.T se encuentra desarrollado en material madera, del tipo MDF (9 mm de espesor). El mismo asume el alojamiento de un arreglo par de luminarias a modo de indicación del nivel del incidente en proceso, un teclado con objetivos de ingreso de instrucciones y navegación a través de la interfaz gráfica, así como un display para representación de información de vuelos y sus estados.

12

Luminaria color ámbar: Su encendido se encuentra sujeto a advertencias en vuelo, particularmente durante los primeros 30 segundos tras la detección sostenida de casos de hipoxia, casos de muerte de piloto, los primeros 30 segundos tras la detección de somnolencia, falta de portación de dispositivo de adquisición de datos y/o desactivación de equipo A.E.S. Se recomienda al usuario del equipo permanecer en constante alerta tras ocurrir un evento de dicha índole.
Luminaria color rojo: Su activación se reserva a casos de emergencia que requieren tiempos críticos de respuesta por parte del control del tráfico aéreo. Específicamente, dicha luminaria es encendida tras más de 30 segundos de la detección sostenida de hipoxia, muerte de ambos pilotos, detección sostenida de somnolencia por más de 30 segundos y toda activación manual efectuada.
Teclado: El teclado alojado en el módulo C.T.R.T cumple la función de interactuar con la información en pantalla, sea para generación de instrucciones o desplazamiento dentro de la interfaz gráfica.
Display: Por medio del mismo, se provee al usuario de una interfaz gráfica frontal que informa la situación en cabina de los vuelos circundantes sobre los cuales el módulo cuenta con enlace.

1.

2.

3.

4.

Equipo C.T.R.T.

## Panel frontal.: Componentes

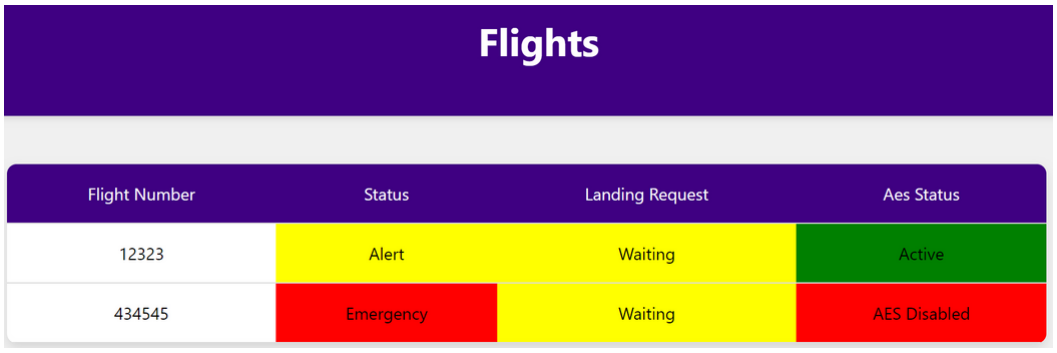
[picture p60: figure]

13

Equipo C.T.R.T.

## Interfaz de Usuario

Por medio del display embebido en el módulo C.T.R.T, se presenta una interfaz de usuario en la cual se lista el estado de las aeronaves circundantes que cuentan con enlace A.E.S -C.T.R.T.

En la pestaña inicial del sistema, se enseña una lista contenedora de vuelos a los que se ha logrado enlazar con el equipo A.E.S asociado a la aeronave. En esta vista, se proporciona información sobre el estado actual de cada vuelo, si se ha solicitado instrucciones de emergencia y si su equipo A.E.S. se encuentra activado y operativo. Se reservan los botones "2" y "8" para la navegación sobre los distintos ítems de la lista de vuelos, cumpliendo los mismos funciones de subida y bajada respectivamente.

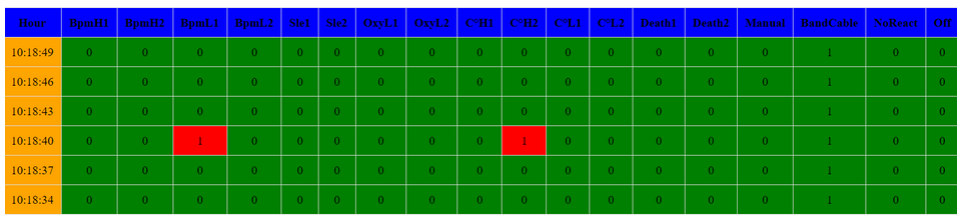
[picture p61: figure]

14

Equipo C.T.R.T.

La selección de un vuelo específico de la lista inicial llevará al usuario a la siguiente pestaña:

Hour (Hora): Indica el momento temporal en que ocurrió el evento.
BpmH1/2 (Frecuencia cardíaca, Piloto 1/2): Representa la frecuencia cardíaca en pulsaciones por minuto de los pilotos 1 y 2, respectivamente. Valores elevados en esta métrica indican un ritmo cardíaco anormalmente alto (umbral alto de la medición).
BpmL1/2 (Frecuencia cardíaca, Piloto 1/2): Estos campos denotan la frecuencia cardíaca de los pilotos 1 y 2, donde valores bajos señalan una frecuencia cardíaca anormalmente baja (umbral bajo de la medición).

En esta sección, se proporcionan detalles acerca del estado de la aeronave particular en un momento específico, indicando en color rojo las condiciones que generan una situación de alerta. Los datos presentados se desglosan de la siguiente manera:

Sle1/2 (Somnolencia, Piloto 1/2): Estos indicadores se encargan de enseñar la potencial existencia de somnolencia por parte del piloto.
Oxy1/2 (Nivel de Oxígeno en Sangre, Piloto 1/2): La activación de estos campos señala un nivel de oxígeno en sangre anormalmente bajo por parte de al menos uno de los pilotos.
C°H1/2 (Temperatura Alta, Piloto 1/2): Estos campos informan acerca de la existencia de sobrecalentamientos del módulo de adquisición de datos.
C°L1/2 (Temperatura Baja, Piloto 1/2): Estos indicadores denotan una temperatura de operación excesivamente baja en el módulo de adquisición de datos.
Death 1/2 (Muerte, Piloto 1/2): La activación de estos campos indica el fallecimiento por parte de uno de los pilotos. Manual (Activación Manual): Esta condición se registra en

casos de activación manual por parte de la tripulación. BandCable (Desconexión del Cable): Se utiliza este campo para informar la desconexión del módulo de adquisición de datos.
NoReact (Sin Reacción): Este indicador se activa ante la falta de reacción frente a estímulos de alerta por parte de los pilotos.
Off (Desconexión): Se emplea este campo si se detecta que el equipo A.E.S asociado no se encuentra operativo.
15

Equipo C.T.R.T.

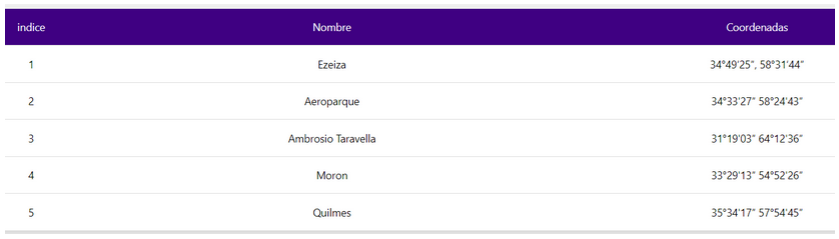
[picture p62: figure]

16

Equipo C.T.R.T.

A través del menú principal previamente descrito, es posible enviar instrucciones que permitan efectuar un aterrizaje de emergencia. Por medio de la utilización de la tecla “A” del teclado, el usuario es enviado a una nueva pestaña con la siguiente información:

Nota: En caso de presionar accidentalmente la tecla “A”, se puede
anular sus efectos al pulsar el botón “B”.
Por medio de la interfaz gráfica de esta pestaña, se puede proceder a seleccionar el aeropuerto en el cual efectuar las maniobras de emergencia. Haciendo uso de las teclas numéricas, se podrá seleccionar el aeropuerto de destino para la aeronave en conflicto con solo presionar el número asociado al aeropuerto de interés (se destaca que, como se puede apreciar en la ilustración, cada aeropuerto tiene un carácter numérico asociado para su selección). En caso de equivocaciones al momento de la selección de destino, el pulsado de la tecla “B” permite el borrado de la opción previamente elegida.

17

Equipo C.T.R.T.

## Teclado Matricial

Por medio de la utilización del teclado embebido del módulo C.T.R.T, el usuario es capaz de navegar a través de las distintas opciones de aeronaves y sus parámetros relevados que se presenten en pantalla, haciendo uso de la interfaz gráfica. Los caracteres reservados para la navegación dentro de la mencionada interfaz son:

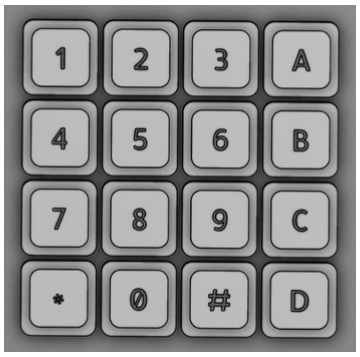
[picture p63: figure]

"2" para subida dentro de la selección principal de vuelos.

"8" para bajada dentro de la selección principal de vuelos.

"6" para ingresar al historial de estados del vuelo.

Dentro de la interfaz inicial:

18

Equipo C.T.R.T.

"4" para retroceder en la interfaz de vuelos.
"6" para cambiar a la interfaz de aeropuertos.
"A" para enviar instrucciones de emergencia al vuelo seleccionado en la primer interfaz.
"B" para cancelar la instrucción de emergencia previamente establecida.

"<numero>" A cada aeropuerto de alcance se le asigna un número dentro de la interfaz. Al apretar el numero asociado en el teclado se procede a seleccionar el aeropuerto equivalente como destino de la serie de maniobras de emergencia.
"B" Eliminar la selección de instrucciones de emergencia previas.
"C" Para retroceder hacia la página anterior de la interfaz gráfica.
"D" Refresca la información presentada en la interfaz.

En la interfaz de historial de estados del vuelo:

En la interfaz de aeropuertos:

19

## Procedimiento de desarme

Equipo C.T.R.T.

El procedimiento de desarme se encuentra detallado, para óptima comprensión del mismo, por medio de la siguiente imagen, a través de la cual se enseña una vista explotada del equipo, representando la ubicación y disposición tanto de componentes de representación externa, como aquellos presentes en la plaqueta madre del circuito interno del módulo.

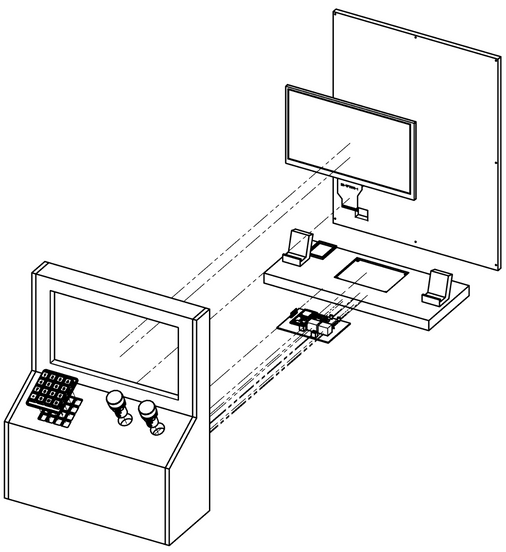
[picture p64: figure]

A fin de acceder al conexionado interno del equipo C.T.R.T, se sugiere remover la tapa trasera de la carcasa contenedora tal como enseña la imagen previa, reduciendo así el contacto y rozamiento con circuitos y elementos conductores de los mismos. Posterior a ello, el usuario será capaz de acceder a la plaqueta madre, el ordenador embebido y su respectiva fuente de alimentación.

20

## Solución de problemas

Equipo C.T.R.T.

La siguiente sección sugiere una serie de procedimientos a ejecutar en caso de presentarse fallas en el funcionamiento del módulo C.T.R.T.. Los problemas más frecuentes a encontrar son:

La luminaria indicadora no se enciende tras recepción de alertas, o no se activan las alarmas sonoras:
Este tipo de casos pueden ocurrir principalmente debido a errores momentáneos de software y/o hardware (en este último caso, destacan potenciales falsos contactos entre componentes del circuito como principal factor). Para eventos de tal índole, se recomienda reiniciar el módulo. De persistir el inconveniente, contáctese con el fabricante: podría tratarse de una problemática que requiera de la intervención del servicio técnico. Si el artículo afectado se encuentra en garantía, el cliente tiene derecho a reclamar un reembolso o una reparación sin coste, así como la sustitución integra en caso de tratarse de un desperfecto crítico.

La luminaria indicadora se enciende o se activan las alarmas sonoras sin previa recepción de alertas:
En caso de ocurrir inconvenientes de este tipo (los cuales pueden surgir como consecuencia de desperfectos técnicos relacionados con el hardware y/o software del equipo), se recomienda proceder con el reinicio de la unidad, a fin de eliminar toda potencial falla ocasional que atente contra el

21

Equipo C.T.R.T.
correcto funcionamiento de la misma.
Si el inconveniente persiste, se deberá desactivar la unidad en su totalidad y contactar inmediatamente con el fabricante, notificando la decisión a la autoridad de aviación civil y las aeronaves dentro del espacio aéreo. Si el producto se encuentra dentro de su garantía, el usuario tiene el derecho a reclamar un reembolso o una reparación sin coste alguno, así como una sustitución de la unidad en caso de la existencia de fallas críticas.

La información presente por medio de la interfaz gráfica no es actualizada debidamente:
El presente problema sugiere la existencia de un desperfecto de software, o un inconveniente crítico de hardware, relacionado con el sistema de recepción y procesamiento de información.
A modo de solución, se sugiere el reinicio de la unidad y posterior recuperación de enlace con equipos A.E.S de aeronaves circundantes, eliminando cualquier desperfecto ocasional que afectara el normal funcionamiento del sistema. De persistir el problema tras la ejecución de la previa instrucción, se deberá proceder a la desactivación inmediata de la unidad, notificando a la autoridad de aviación civil, así como a las aeronaves que se encuentren dentro del espacio aéreo. Si el producto se encuentra dentro de su ventana de garantía, el cliente se encontrará en su derecho a efectuar reclamos de reintegro económico, reparación sin coste o reemplazo de la unidad de ser la falla encontrada de orden crítico.

22

Dispositivo V.D.B.
Dispositivo V.D.B.

## Especificaciones

El dispositivo V.D.B. cumple el rol de adquisición de datos referenciados a signos vitales básicos de los pilotos a cargo del vuelo. La información relevada por medio de este dispositivo es posteriormente transmitida al equipo A.E.S en cabina.
La carcasa del mismo cuenta con dimensiones de 1,85 cm de alto, 6,8 cm de largo y 5,8 cm de ancho. Se encuentra construido con material plástico de tipo PLA, por medio de técnicas de impresión 3D de filamento. El instrumento de adquisición de datos que integra el dispositivo para las respectivas mediciones es el sensor digital MAX30102 dedicado a la medición de ritmo cardíaco y saturación de oxígeno en sangre, valiéndose de la capacidad que posee la sangre para absorber y reflejar distintos espectros de luz conforme a su composición .

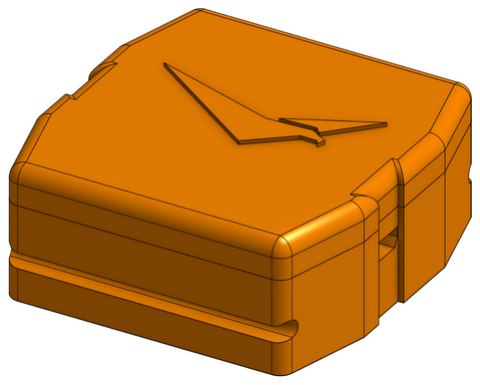
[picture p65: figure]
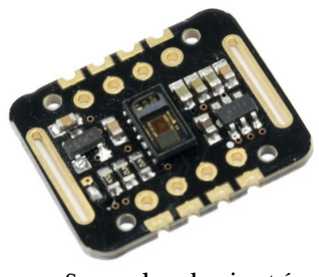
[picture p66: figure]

Sensor de pulsoximetría
MAX30102

23

Dispositivo V.D.B.

## Funcionamiento y uso previsto

El dispositivo se encuentra operativo una vez encendido el módulo A.E.S. Integra un sensor de temperatura por medio del sensor, a través del cual se puede llevar registro de potenciales temperaturas críticas de operación (>40 ºC o <5ºC pueden resultar en comportamientos indeseados en materia de relevamiento de parámetros asociados a la salud de su usuario)
El dispositivo, desarrollado en calidad de pulsera, debe ser colocado a 1 cm del hueso escafoides como indica la imagen, así como correctamente ajustado para garantizar una satisfactoria adquisición de datos (si el instrumento sensor no se encuentra lo suficientemente cercano a la superficie dérmica, podrían producirse mediciones erróneas)

El dispositivo debe encontrarse completamente cargado al inicio de cada vuelo, contando con una autonomía máxima de 24 horas.

24

## Procedimiento de desarme

Dispositivo V.D.B..

El procedimiento de desarme se encuentra detallado, para óptima comprensión del mismo, por medio de la siguiente ilustración, a través de la cual se enseña una vista explotada del dispositivo, representando la ubicación y disposición interna de componentes presentes en la plaqueta interna.

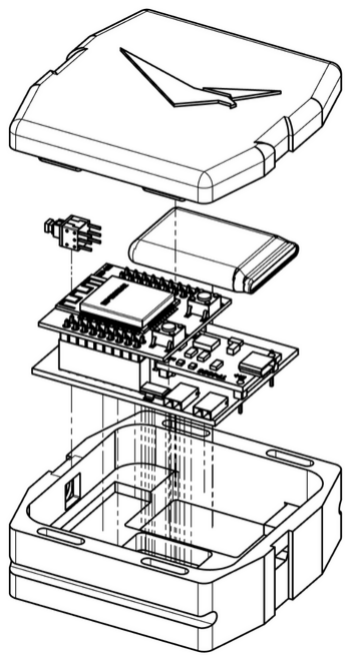
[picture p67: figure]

A fin de acceder al conexionado interno de la plaqueta del dispositivo V.D.B, se debe remover la tapa superior de la carcasa contenedora (sujeta por medio de encastres mecánicos) tal como enseña la imagen previa.

25

## Solución de problemas

Dispositivo V.D.B..

En el caso de presentarse fallas en el funcionamiento del dispositivo V.D.B., se sugiere implementar los procedimientos descritos en la siguiente sección, en la cual se detallan los problemas más frecuentes a encontrar, los cuales son:

Los resultados de las mediciones no coinciden con la manera en que el piloto se siente:
La presencia de errores de medición por parte del dispositivo V.D.B. podría resultar en avisos luminosos en cabina y/o alertas para con la estación terrena inadecuados en relación al corriente estado de salud del portador del dispositivo en cuestión.
Se destaca que se contempla una cierta tolerancia para con las mediciones de signos vitales, por lo que podría simplemente tratarse de un error momentáneo. En tal caso, se recomienda esperar un momento y verificar nuevamente que la operación del dispositivo no accione erróneamente ningún tipo de alerta.
Por otro lado, como fue mencionado anteriormente, ante cualquier evento en el que se produzca una alerta errónea en cabina y/o para con el control del tráfico aéreo, se debe inmediatamente presionar el botón de reacción presente en el panel frontal del equipo A.E.S., dando fe del óptimo estado de salud del portador en cabina.
Si el problema persiste, se recomienda reiniciar el dispositivo V.D.B, para su posterior reenlace con el equipo A.E.S.

26

Dispositivo V.D.B.

Si aún luego de proceder con el reinicio y reenlazamiento del dispositivo, el problema persiste, podría tratarse de un inconveniente relacionado a desperfectos de hardware. Ante tal situación, contáctese con el fabricante del artículo. Si el mismo se encuentra aún dentro de la ventana de garantía, puede solicitar un reembolso económico o el reemplazo por un nuevo dispositivo V.D.B.

27

## Panel de Simulación Virtual

El panel de simulación virtual proporciona una interfaz gráfica especializada para llevar a cabo testeos de funcionamiento, a fin de verificar la correcta operación del sistema, así como en identificar posibles defectos en el mismo. Este se estructura en torno a la disposición de botones que permiten accionar distintos escenarios acordes a la cobertura funcional del sistema. Asimismo, otorga la capacidad de ingresar valores específicos de saturación de oxígeno en sangre y ritmo cardíaco de manera intuitiva mediante el empleo de barras de desplazamiento, aspecto de particular utilidad para llevar a cabo pruebas personalizadas de transmisión de las variables adquiridas por el Vital Data Bracelet.

El panel requiere el accionamiento de un solo botón por vez. Posteriormente, se deberá presionar doblemente el botón de envío, tras lo cual el estado de simulación será forzado en el sistema para el testeo pertinente. Por último, se indica el accionamiento del interruptor de activación, con lo cual se enuncia la utilización del panel hacia el equipamiento. Para casos de simulación con dos (2) pilotos, se deberá presionar el botón de “siguiente”, por medio del cual se presenta una pestaña con la información del segundo piloto (los pasos a seguir para la configuración de escenarios de dicho tripulante son los mismos especificados previamente)

El software de simulación virtual es proveído exclusivamente por medio de la adquisición del sistema.

Panel de Simulación Virtual

## Configuración de escenarios por piloto

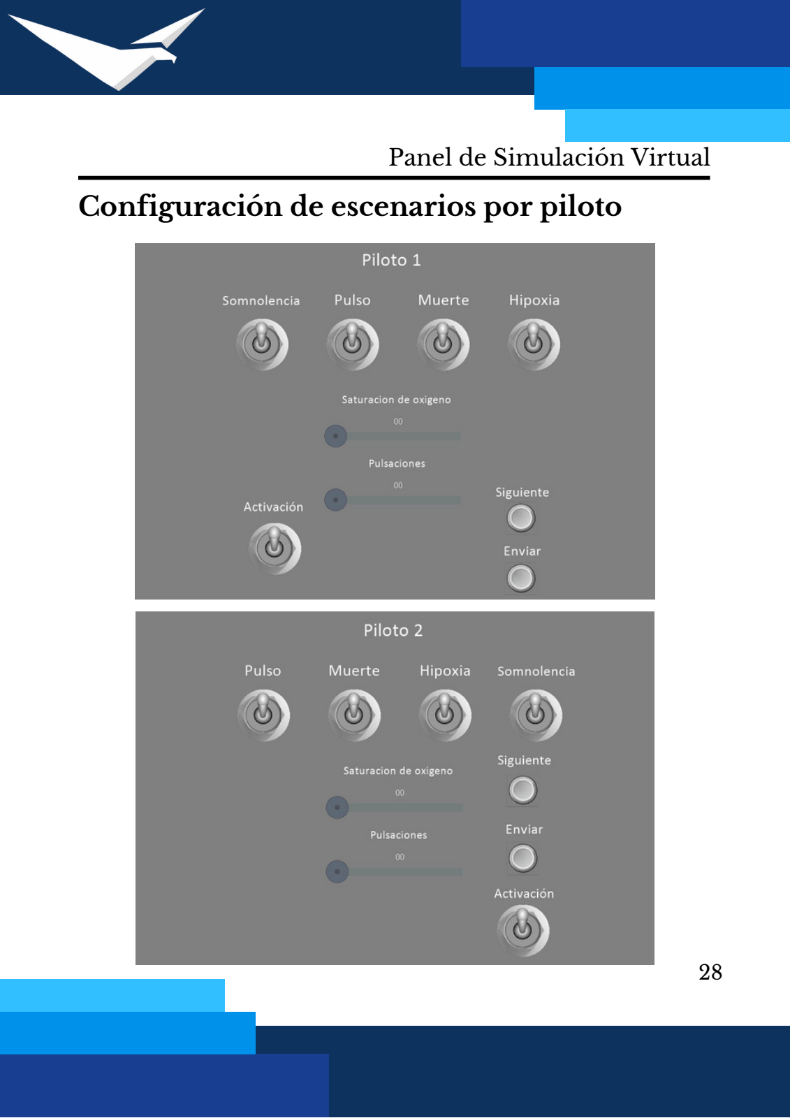
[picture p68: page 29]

28

Panel de Simulación Virtual

29

# Información de garantía

AeroAlert garantiza a sus clientes y usuarios que las unidades proveídas con la adquisición integral del sistema no poseen defectos en su construcción y funcionamiento durante el período de un (1) año. Los equipos deben, durante tal lapso, haberse utilizado en forma y condiciones tal como se encuentra estipulado.
La garantía de cualquier componente del sistema es destituida ante modificaciones y/o reparaciones desautorizadas, o manejos inadecuados de los mismos.
AeroAlert se encuentra con la responsabilidad de reparar y/o reemplazar parcial o totalmente unidades defectuosas sin costo alguno, así como resarcir económicamente al usuario si la situación lo amerita, siempre y cuando el producto adquirido se encuentre cubierto por la presente garantía.
En concordancia con dicha política, se reembolsará el importe pagado por el cliente siempre y cuando ello sea solicitado. La devolución puede ser realizada por medios electrónicos o presenciales, sea frente al fabricante o al distribuidor con el que fue adquirido el sistema íntegro o la unidad afectada.
Para consultas, puede contactarse por medio de la página web aeroalert.com.ar o a través del correo electrónico proyectoaeroalert@gmail.com.

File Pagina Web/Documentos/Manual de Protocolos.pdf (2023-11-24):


# MANUAL DE PROTOCOLOS

# Proyecto AeroAlert

# Para pilotos y controladores aéreos

# ÍNDICE

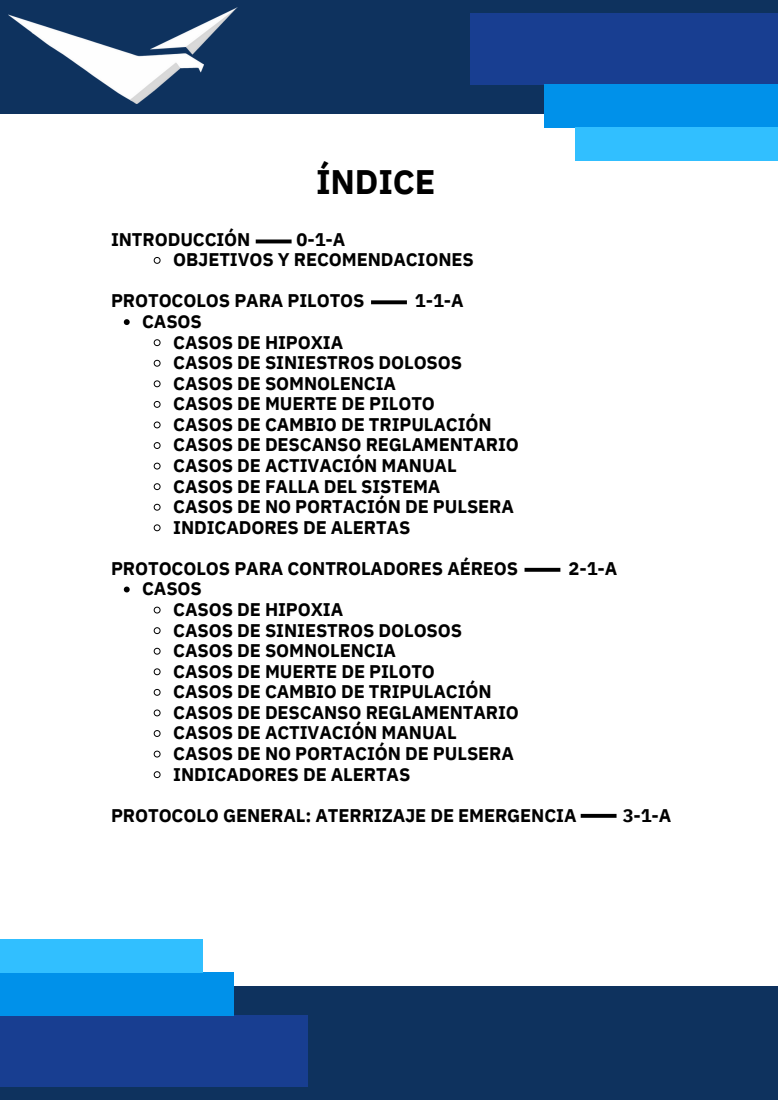
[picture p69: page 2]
INTRODUCCIÓN; PROTOCOLOS PARA PILOTOS; PROTOCOLOS PARA CONTROLADORES AÉREOS; PROTOCOLO GENERAL: ATERRIZAJE DE EMERGENCIA

OBJETIVOS Y RECOMENDACIONES
CASOS
CASOS DE HIPOXIA
CASOS DE SINIESTROS DOLOSOS
CASOS DE SOMNOLENCIA
CASOS DE MUERTE DE PILOTO
CASOS DE CAMBIO DE TRIPULACIÓN
CASOS DE DESCANSO REGLAMENTARIO
CASOS DE ACTIVACIÓN MANUAL
CASOS DE FALLA DEL SISTEMA
CASOS DE NO PORTACIÓN DE PULSERA
INDICADORES DE ALERTAS

CASOS DE HIPOXIA
CASOS DE SINIESTROS DOLOSOS CASOS DE SOMNOLENCIA
CASOS DE MUERTE DE PILOTO
CASOS DE CAMBIO DE TRIPULACIÓN CASOS DE DESCANSO REGLAMENTARIO CASOS DE FALLA DEL SISTEMA
CASOS DE ACTIVACIÓN MANUAL CASOS DE NO PORTACIÓN DE PULSERA

El presente manual ha sido confeccionado bajo propósito de brindar una referencia, tanto a pilotos como a controladores aéreos, que permita obrar de manera satisfactoria dadas las funcionalidades del sistema ICERS en las correspondientes situaciones de emergencia en vuelo que cuenten con cobertura del mencionado sistema.
Los respectivos casos alcanzados por ICERS y, como consecuencia, con una utilidad suficiente como para ser mencionados y analizados en este documento, son:

## Recomendaciones

Tanto pilotos como controladores aéreos deben tomar en cuenta de manera racional la dimensión de la situación que se presente, entender sus responsabilidades y competencias, así como también las consecuencias de sus actos.

Por lo tanto, se recomienda fuerte e imperiosamente el seguimiento estricto de los protocolos enunciados en el presente documento, lo cual permita garantizar operaciones de emergencia satisfactorias, evitando así potenciales consecuencias no deseadas.

# INTRODUCCIÓN

0-1-A

# PROTOCOLOS PARA PILOTOS

En este apartado, se procede a definir los protocolos de actuación correspondientes a pilotos en los casos que se encuentran cubiertos por el sistema ICERS.
Como fue previamente mencionado, se recomienda imperiosamente el estricto seguimiento de los procedimientos descriptos en el presente documento, para así garantizar la efectividad de los mismos, así como una resolución satisfactoria a ciertas situaciones de emergencia en vuelo.

## Casos de Hipoxia

Los eventos de hipoxia ameritan tanto una activación manual (en caso de que los síntomas sean perceptibles) como automática (a través del dispositivo pulsera). Se recomienda reservar la activación manual para situaciones en las cuales el sistema no sea capaz de proteger.

Por definición, en caso de que la pulsera registre en el piloto y el copiloto una saturación de oxígeno en sangre menor al 90%, se brindará una alerta en cabina, así como al A.T.C.

Cuando esta condición se cumpla, los pilotos deberán ocupar sus mascarillas de oxígeno y proseguir estableciendo contacto con el A.T.C correspondiente.

En caso de que los pilotos denoten que no se encuentran en condiciones de continuar óptimamente el vuelo debido a los efectos de hipoxia, pueden activar manualmente el sistema ICERS o de forma automatica con la pulsera, tras el debido contacto con el A.T.C, ya sea que tal activación sea transitoria (a la espera de la recuperación de sus capacidades) o permanente bajo la condición de que los efectos sufridos sean tales que los pilotos no se vean en condiciones de continuar con el vuelo.

1-1-A

## Casos de siniestros dolosos

Tras un evento de esta categoría, la única manera de poder generar una respuesta de emergencia es que el A.T.C tome noción de la situación y, con ello, proceda a activar el Sistema Automático de Emergencia.
De ser el siniestro ejercido por parte de miembro/s de la tripulación, se debe contactar con tierra lo antes posible.

En caso de que el ataque sea perpetuado por parte de un pasajero (o grupo de ellos), los pilotos podrán comunicarse con el A.T.C, y esperar una activación del Sistema Automático de Emergencia, o colocar el código de secuestro en el Transponder, para así poder activar el mismo sistema.

El procedimiento recomendado es, en primer lugar, colocar el código de secuestro en el Transponder, para consecutivamente entablar comunicación con el A.T.C. asi se podra establecer.

## Casos de somnolencia

La respuesta inicial frente a casos de esta índole, si es solo un piloto, será la activación de una luz en cabina, con el objetivo de que el piloto y/o terceros en cuestión reconozcan el estado de somnolencia del primero. Tras esto, el piloto, por medios propios o ajenos, deberá despertarse y presionar el botón de reacción.

En caso de que ambos pilotos se encuentren en la misma situación, de igual manera se activará la luz ámbar en cabina y una alarma, además se enviará un aviso al A.T.C. Se contemplará un tiempo de reacción máximo de 30 segundos para esta situación específica, tras lo cual de no haber presionado el botón de reacción, se considerará a ambos pilotos en estado de inconsciencia.
Si la condición de somnolencia afecta únicamente a uno de los pilotos no hay emergencia, sino que es una alerta.

1-2-A

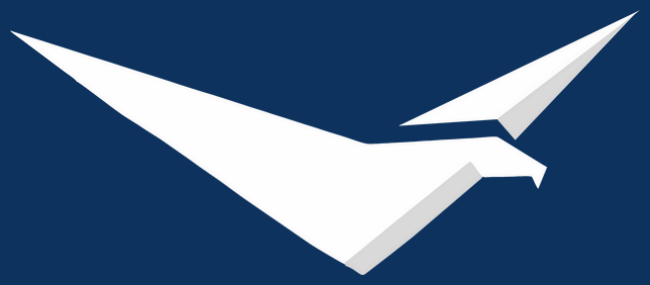
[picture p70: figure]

## Casos de muerte de piloto

Tras la muerte de un piloto el A.E.S lo detectara, y se encenderá una luz ámbar en cabina y se notificará al A.T.C del evento sucedido.

En caso de que ambos pilotos se encuentren sin vida, el sistema avisara al A.T.C, y encenderá una luz ámbar en cabina con una alerta sonora especifica.

## Casos de cambio de tripulación

De ser requerida la ejecución del protocolo de cambio de tripulación durante un vuelo, se deberá mantener pulsado los botones de la pulsera, para poder ejecutar el cambio.

Tras ser el procedimiento habilitado, se otorgará el lapso de 40 segundos para efectuar el cambio, momento en el cual la tripulación anterior deberá traspasar sus pulseras a la tripulación ingresante.

1-3-A

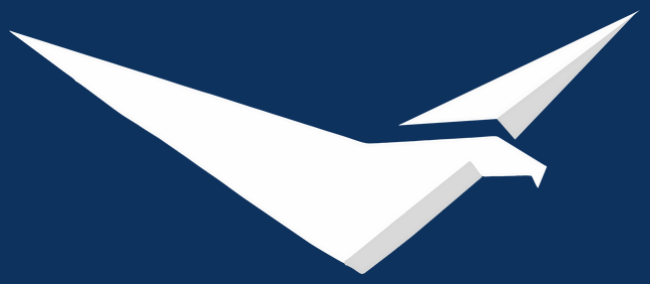
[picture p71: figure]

## Casos de descanso reglamentario

En ocasiones en las cuales el piloto desee hacer uso de su descanso reglamentario, deberá presionar el botón para establecer a su pulsera en modo descanso, y así no tener ningún inconveniente.
De ser su descanso autorizado, el piloto contará con un período de 20 minutos en los cuales su pulsera no detectará su baja actividad cardíaca como un caso de somnolencia, aunque la misma se mantendrá funcional.
Pasados los 20 minutos, el sistema retomará sus funciones normalmente, y se deberá esperar unos minutos para poder realizar otra petición dentro de la misma aeronave. Se destaca que solo un piloto a la vez podrá activar dicho modo de operación, y que solamente podrá hacerlo una vez por vuelo.

Se recomienda usar 15 de los 20 minutos del proceso para descanso, destinando los 5 minutos restantes a la recuperación de las capacidades, evitando así que la pulsera tome mediciones erróneas y/o indeseadas.

## Casos de falla del sistema

En caso de que se presenten notorias fallas en el sistema ICERS, sean estos por mediciones erróneas de las pulseras o por problemas en la comunicación con el A.T.C, se recomienda imperiosamente desactivar el sistema, evitando así avisos erróneos hacia el A.T.C.
De notarse que su pulsera se encuentra funcionando erróneamente, se podrá notificar al A.T.C de tal situación, tras lo cual se recomienda proceder con su desactivación.

Las fallas del sistema pueden determinarse en vuelo de efectuarse alguna alerta en cabina que no tenga correlación con los hechos que transcurren en la misma, o de activarse el flag de advertencia. El primer caso mencionado determinará que la falla se encuentra en la pulsera y/o su sistema de lectura de datos. El segundo caso indicará otro tipo de fallas técnicas, relacionadas a la alimentación del equipo, o en caso de encontrarse fuera de alcance de cualquier A.T.C.
Para efectuar la desactivación del sistema, se deberá conectar la llave correspondiente en el interruptor de anulación del Sistema Automático de Emergencia.

1-4-A

Color rojo: enuncia condiciones de hipoxia, activación manual y activación desde la A.T.C

Color ámbar: enuncia casos de inconsciencia, somnolencia, muerte, no portación de pulsera y altas o bajas pulsaciones.

## Casos de activación manual

La activación manual es entendida como un protocolo de último recurso. Por lo tanto, se recomienda efectuarla exclusivamente cuando el equipo no posea las herramientas suficientes como para dar una alerta por sus propios medios, o en su defecto, que sea incapaz de generar alertas debido a una falla.
De ocurrir una situación de tal índole, se deberá proceder presionando el botón de activación manual, tras lo cual inmediatamente se activará el Sistema Automático de Emergencia.

## Casos de no portación de pulsera

En caso de que los pilotos no se encuentren portando sus pulseras, o no lleven las mismas correctamente colocadas, serán alertados con una luz color ámbar en cabina, dando aviso de la falta de conexión/incorrecta conexión de la pulsera.
El aviso será generado desde el A.T.C correspondiente.

## Indicadores de alertas

En la cabina de la aeronave, las alertas serán mostradas mediante indicadores lumínicos bajo la siguiente codificación:

1-5-A

# PROTOCOLOS PARA CONTROLADORES AÉREOS

En este apartado, se procede a definir los protocolos de actuación en emergencia correspondientes a controladores aéreos dados los casos de emergencia que se encuentran cubiertos por el sistema ICERS.
Como fue previamente mencionado, se recomienda imperiosamente el estricto seguimiento de los procedimientos descriptos en el presente documento, para así garantizar la efectividad de los mismos, así como una resolución satisfactoria a ciertas situaciones de emergencia en vuelo.

## Casos de Hipoxia

Cuando un caso de hipoxia en cabina ocurre, se activará una alarma de emergencia y se encenderá una luz roja en la oficina de control de tráfico aéreo. El A.T.C deberá establecer contacto con la aeronave de forma inmediata por radio. En principio, se deberá corroborar que la medición arrojada sea real.

Tras el contacto del A.T.C con la tripulación, los pilotos devolverán una respuesta o no de acuerdo al estado de consciencia en el que se encuentren producto de los efectos de hipoxia. En caso de contestar, se corroborará la veracidad de las mediciones. De cumplirse dicha condición, se procederá a efectuar un aterrizaje de emergencia.
En caso de que los pilotos no contesten ante la consulta del A.T.C, se declarará que los mismos no se encuentran en condiciones óptimas para la conducción de la aeronave tras 3 intentos fallidos. Posteriormente, se activará una alarma de inconsciencia general, y se procederá a realizar un aterrizaje de emergencia, activando el sistema automático de emergencia desde la torre de control.

2-1-A

## Casos de siniestros dolosos

En casos de esta índole, el controlador aéreo deberá contactarse con la aeronave inmediatamente ante cualquier indicio de que la aeronave se encuentre siniestrada, o en tal proceso, si dicha sospecha se afirma (ya sea mediante el sistema Transponder, o vía comunicación directa con el piloto), se procede a activar el Sistema Automático de Emergencia de forma remota y, por consiguiente, se comienza a organizar un aterrizaje de emergencia.
En casos de activación manual, desactivación del sistema, muerte de uno o ambos pilotos, desvíos de ruta, desactivación del Transponder y/o demás sistemas de comunicación y llamados por parte de la tripulación, siempre se debe marcar la aeronave como posible sospechosa de secuestro, tras lo cual se deberá monitorear todos sus movimientos.

## Casos de somnolencia

Dado un caso de somnolencia, el controlador aéreo recibirá una alerta sonora, así como el encendido de una luz color ámbar en caso de que ambos pilotos se encuentren en dicho estado.
Tras dicho estímulo, el A.T.C deberá contactar con la aeronave y esperar a que los pilotos despierten, dando un tiempo máximo de respuesta de 40 segundos. En caso afirmativo, el protocolo no conllevará más acciones, pero se deberá monitorear la aeronave dada la potencial fatiga de los pilotos. En caso negativo, se activará una alarma sonora y una luz roja en la oficina de tráfico aéreo.
En caso de que uno de los pilotos no despierte, se lo calificará de inconsciente, tras lo cual el controlador aéreo se pondrá en contacto con su compañero a bordo para efectuar un aterrizaje de emergencia.

De ocurrir que no se reciba respuesta de ninguno de los pilotos, el mismo sistema ICERS pedirá comandos al A.T.C para realizar el aterrizaje de emergencia.

Se recomienda tratar de comunicarse con la aeronave bajo cualquier caso, principalmente por razones de seguridad.

2-2-A

## Casos de muerte de piloto

En caso de muerte de un piloto, se notificará mediante la activación de una alarma sonora y una luz de alerta para notificar.
Se debe contactar con la aeronave inmediatamente, en principio para verificar la información recibida. De ser así, se deberá proceder con la ejecución de un aterrizaje de emergencia.

En caso de muerte de ambos pilotos, se notificará mediante la activación de una luz roja y una alarma sonora. En este caso se debe proceder contactando la aeronave y procediendo a realizar un aterrizaje de emergencia.

## Casos de falla del sistema

En caso de que se presenten fallas del sistema, el A.T.C podría encontrarse en situación de recibir valores y alertas erróneas respecto a determinado vuelo. Para ello, ante cualquier caso, deberá comunicarse con la aeronave en conflicto para verificar la veracidad de la información recibida.
En caso de que la información proporcionada constituya un error del sistema, el controlador aéreo podrá autorizar la desactivación del sistema ICERS teniendo en cuenta la magnitud y gravedad de los errores presentes.

2-3-A

Color rojo: para emergencias

Color ámbar: para alertas y avisos

## Casos de activación manual

Cuando una aeronave active manualmente el Sistema Automático de Emergencia, el controlador aéreo en cuestión será notificado con el encendido de un indicador lumínico de color rojo en su torre de control. En estos casos, es de suma importancia contactar con la aeronave involucrada, para así obtener detalles y razones del evento ocurrido.

## Casos de no portación de pulsera

En caso de detectarse la no portación (o incorrecta portación) de la correspondiente pulsera, el control aéreo será notificado a través del encendido de un indicador lumínico de color ámbar en su oficina.
Tras dicho aviso, se deberá notificar a la aeronave la incorrecta portación de pulsera.

## Indicadores de alertas

En la torre de control, se dispone del siguiente arreglo de indicadores, para así facilitar y optimizar el entendimiento de la situación y su posterior resolución:

2-4-A

# PROTOCOLO GENERAL: ATERRIZAJE DE EMERGENCIA

Cuando un controlador aéreo recibe una alerta de una aeronave, el cual corresponda a los casos previamente vistos,se deben tomar medidas rápidas y eficaces para garantizar un aterrizaje de emergencia seguro. Una vez que se ha verificado la veracidad de la alerta, el controlador aéreo deberá acercarse al C.T.R.T y enviar comandos al Sistema Automático de Emergencia de la aeronave para que esta realice las maniobras necesarias.

Es importante destacar que el A.E.S. de la aeronave será el encargado enviar los parámetros para aterrizar, enviados de la CTRT a la computadora de vuelo de la aeronave.

Para poder enviar comandos precisos al A.E.S, el C.T.R.T debe tener en cuenta varios factores. En primer lugar, se debe saber el modelo de la aeronave en cuestión, ya que cada modelo tiene sus propias características y requerimientos de vuelo. También debe considerar los aeropuertos cercanos que puedan ser adecuados para un aterrizaje de emergencia y las maniobras necesarias para llegar a ellos de manera segura para esto se tienen en cuenta el tráfico aéreo circundante, ya que esta afecta la capacidad de la aeronave para maniobrar de manera segura.

3-1-A

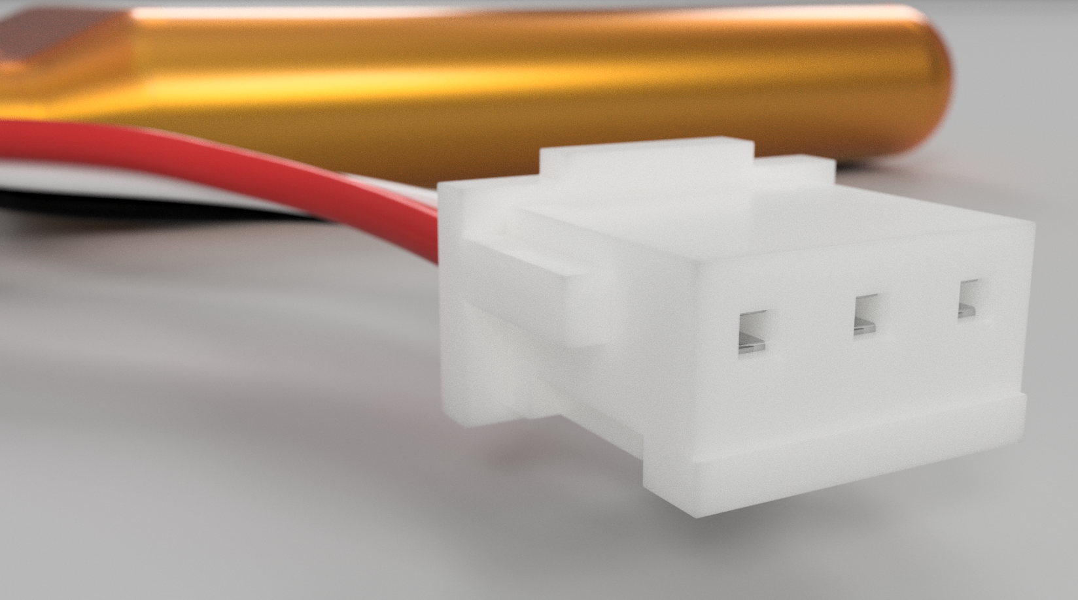
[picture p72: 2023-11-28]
CAD/STEP Templates/Renders/Battery 4.png

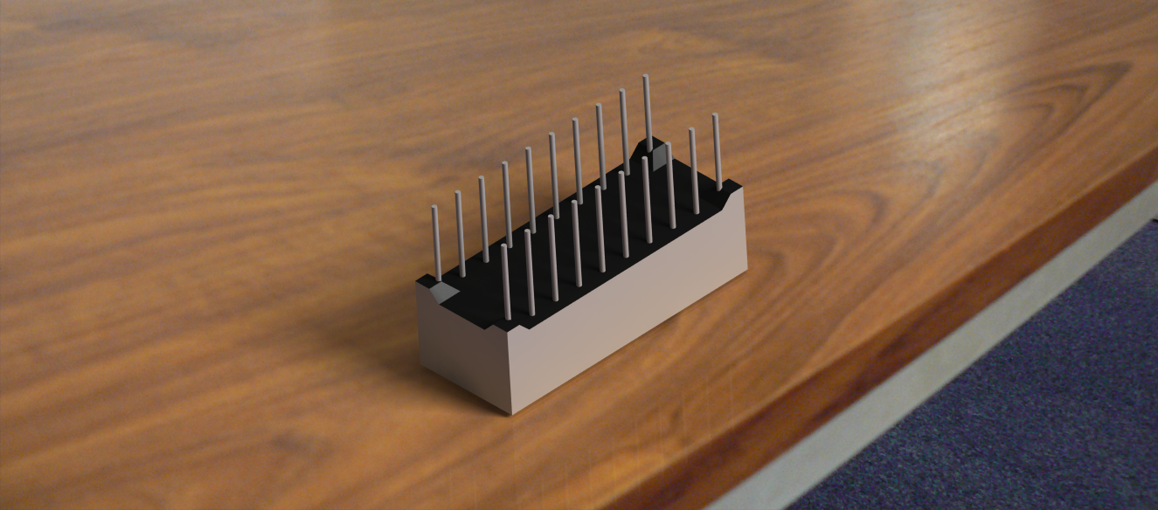
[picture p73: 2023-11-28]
CAD/STEP Templates/10-segment-linear-display-1/Renders/10 segment displayBack.png

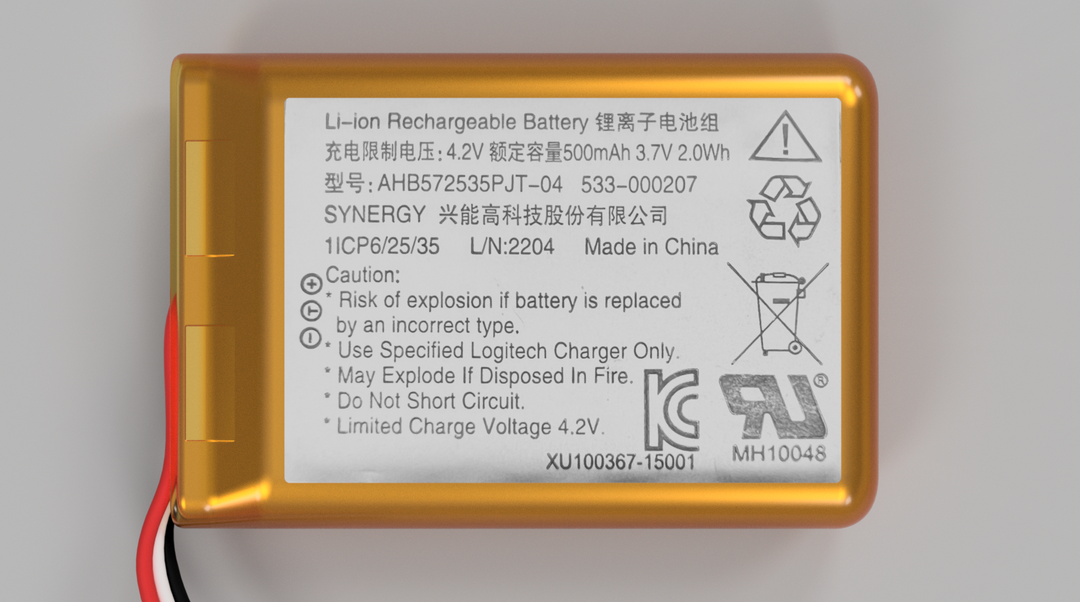
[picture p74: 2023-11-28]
CAD/STEP Templates/Renders/Battery 3.png

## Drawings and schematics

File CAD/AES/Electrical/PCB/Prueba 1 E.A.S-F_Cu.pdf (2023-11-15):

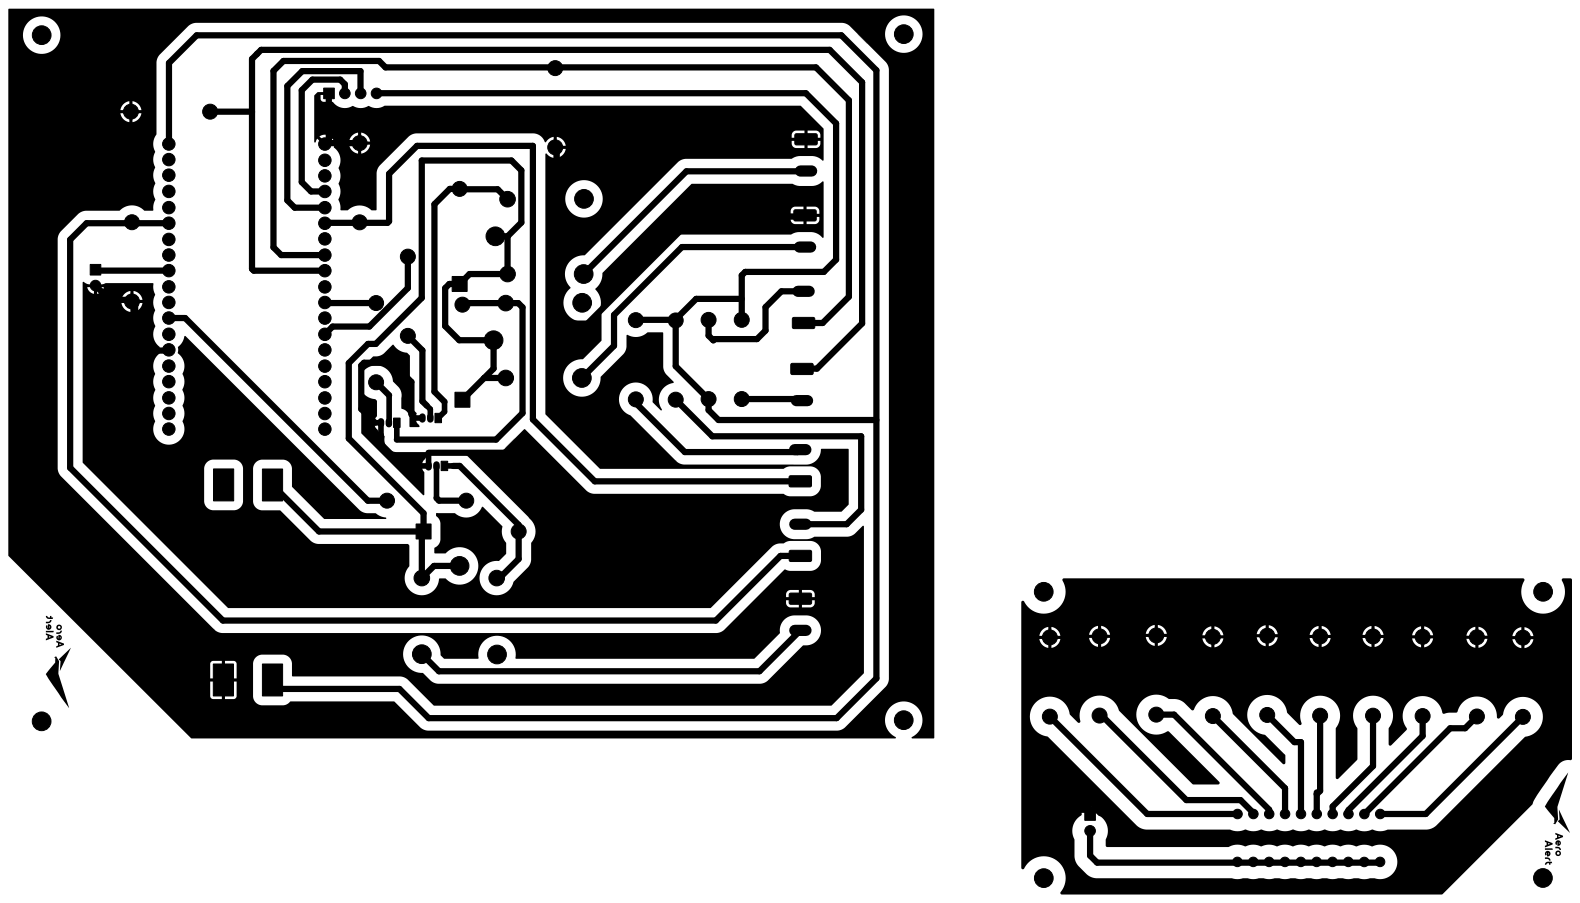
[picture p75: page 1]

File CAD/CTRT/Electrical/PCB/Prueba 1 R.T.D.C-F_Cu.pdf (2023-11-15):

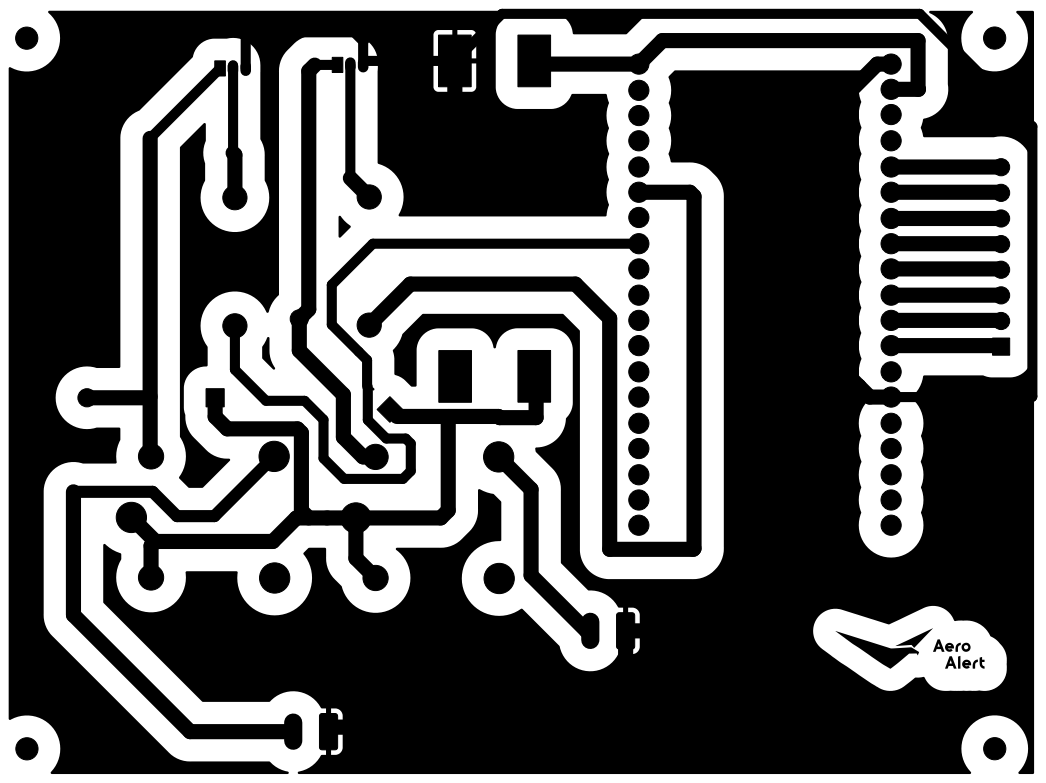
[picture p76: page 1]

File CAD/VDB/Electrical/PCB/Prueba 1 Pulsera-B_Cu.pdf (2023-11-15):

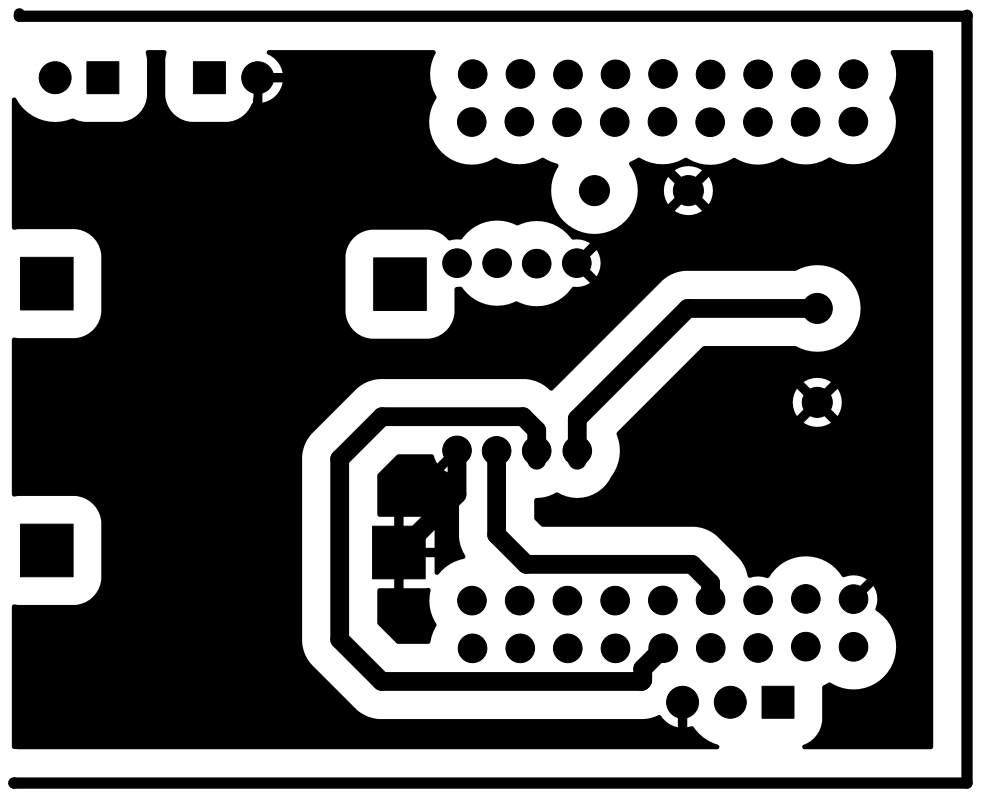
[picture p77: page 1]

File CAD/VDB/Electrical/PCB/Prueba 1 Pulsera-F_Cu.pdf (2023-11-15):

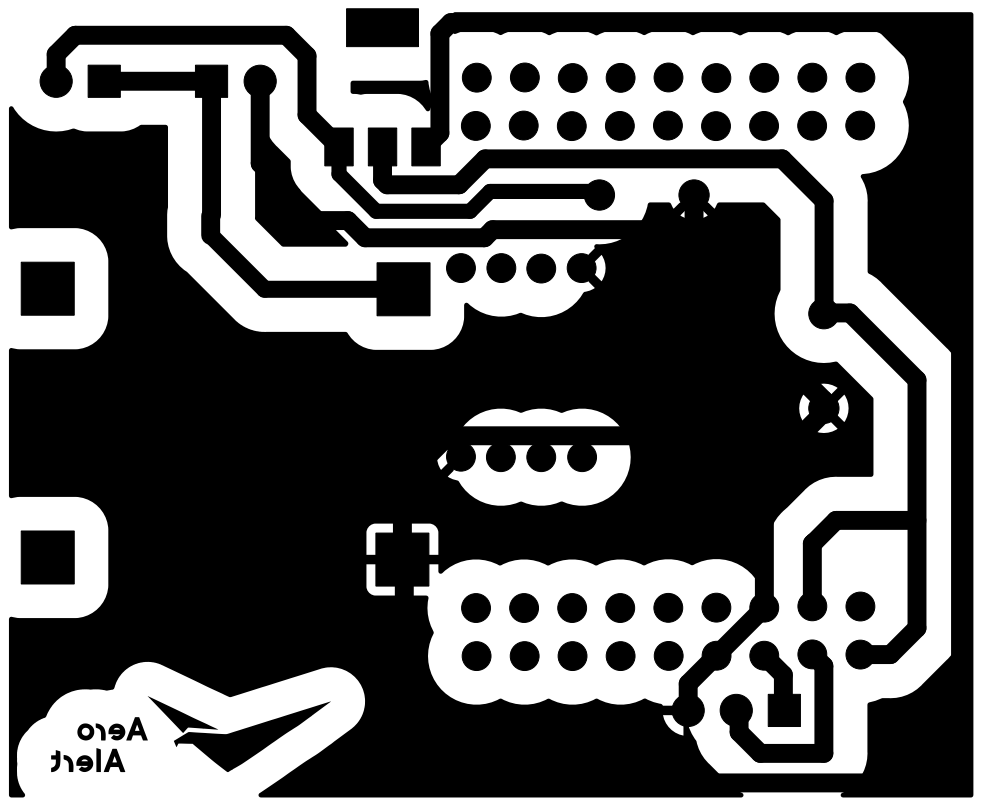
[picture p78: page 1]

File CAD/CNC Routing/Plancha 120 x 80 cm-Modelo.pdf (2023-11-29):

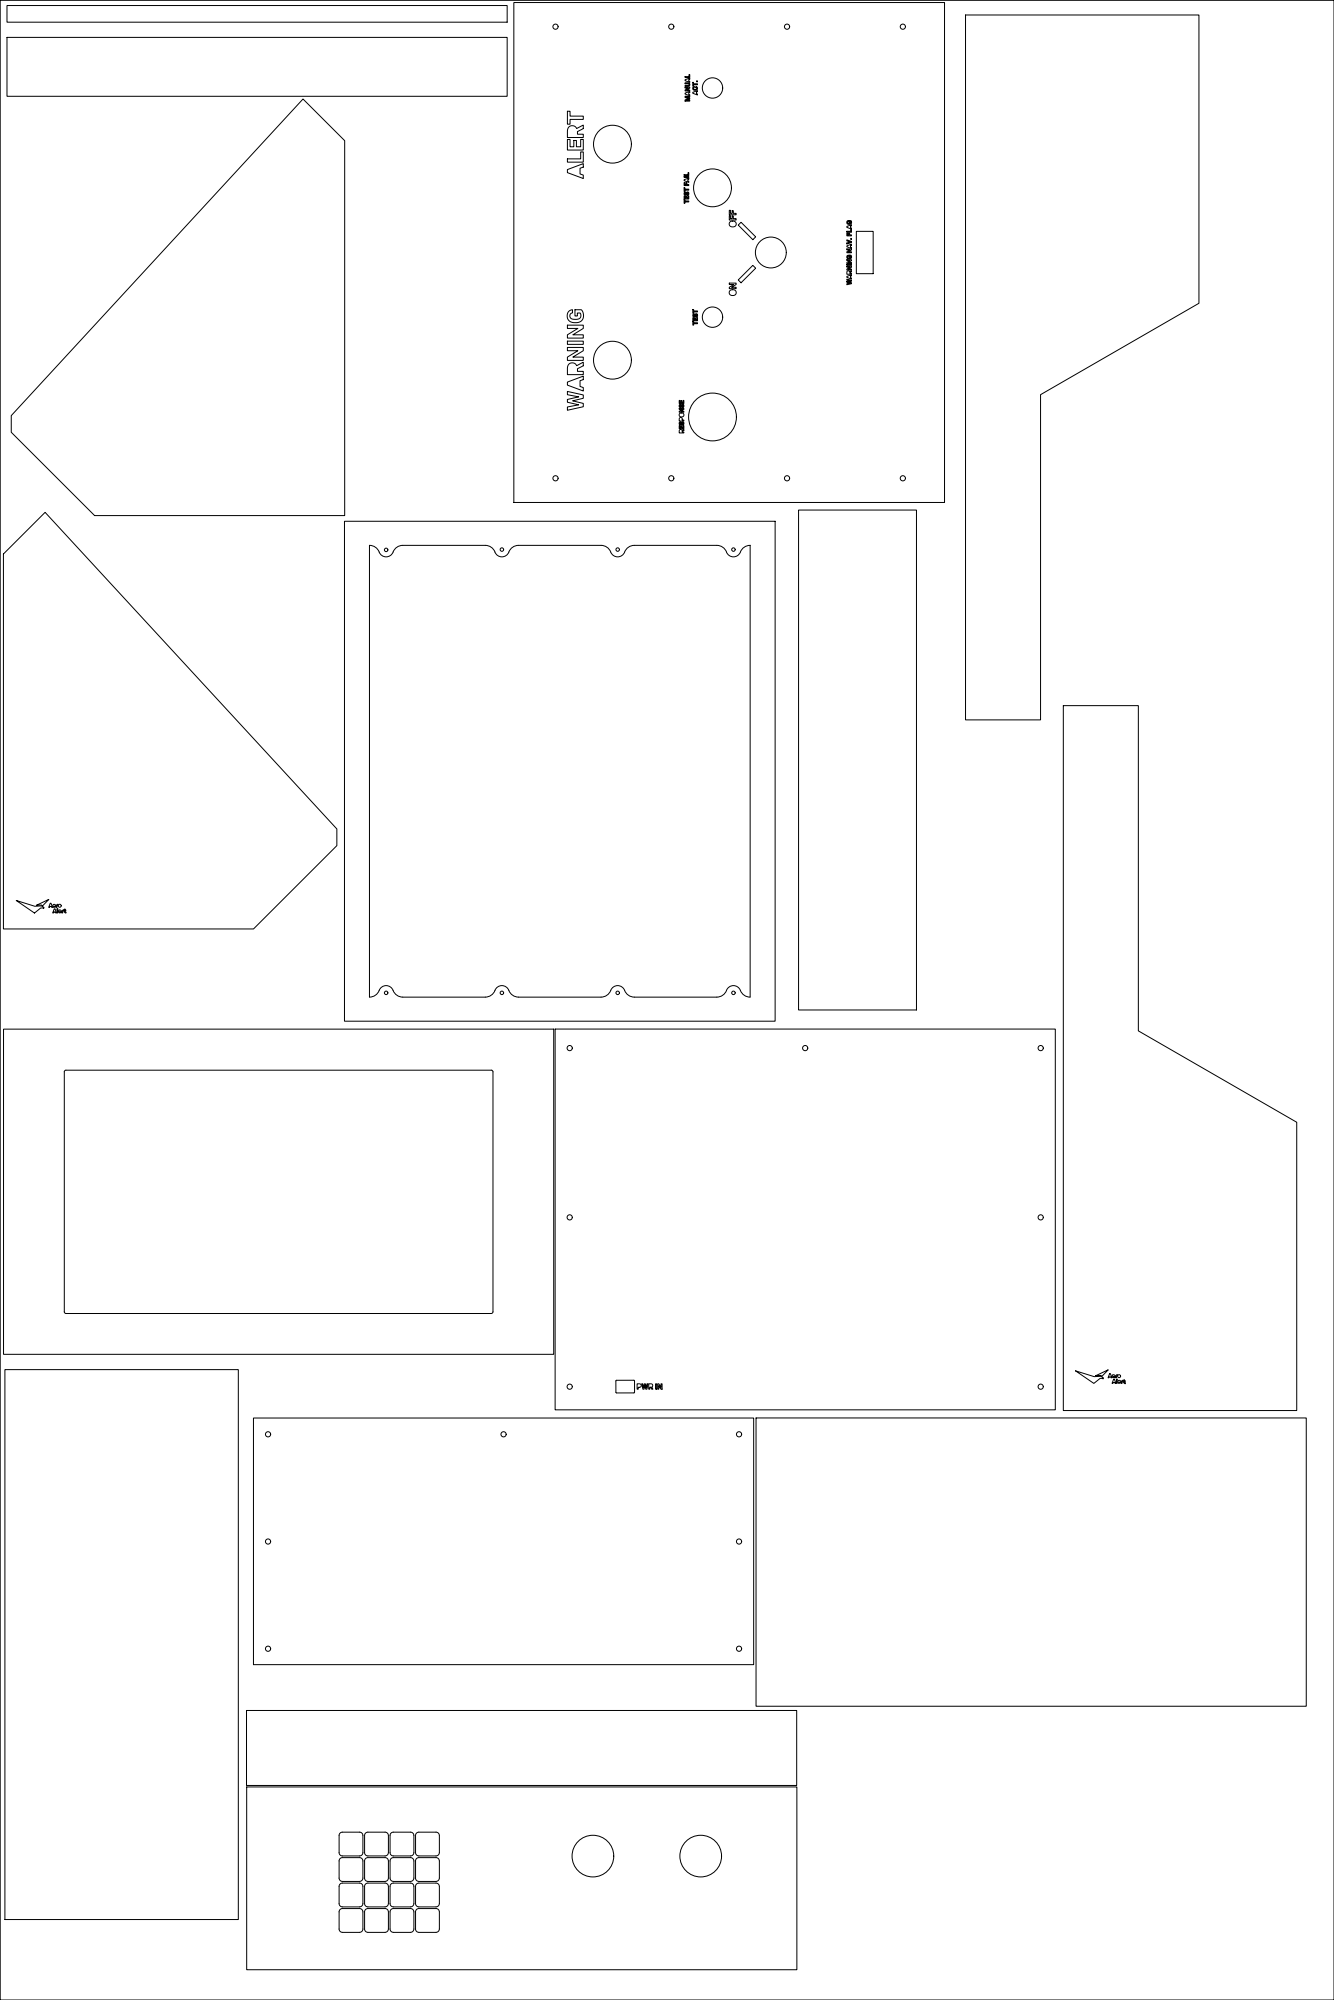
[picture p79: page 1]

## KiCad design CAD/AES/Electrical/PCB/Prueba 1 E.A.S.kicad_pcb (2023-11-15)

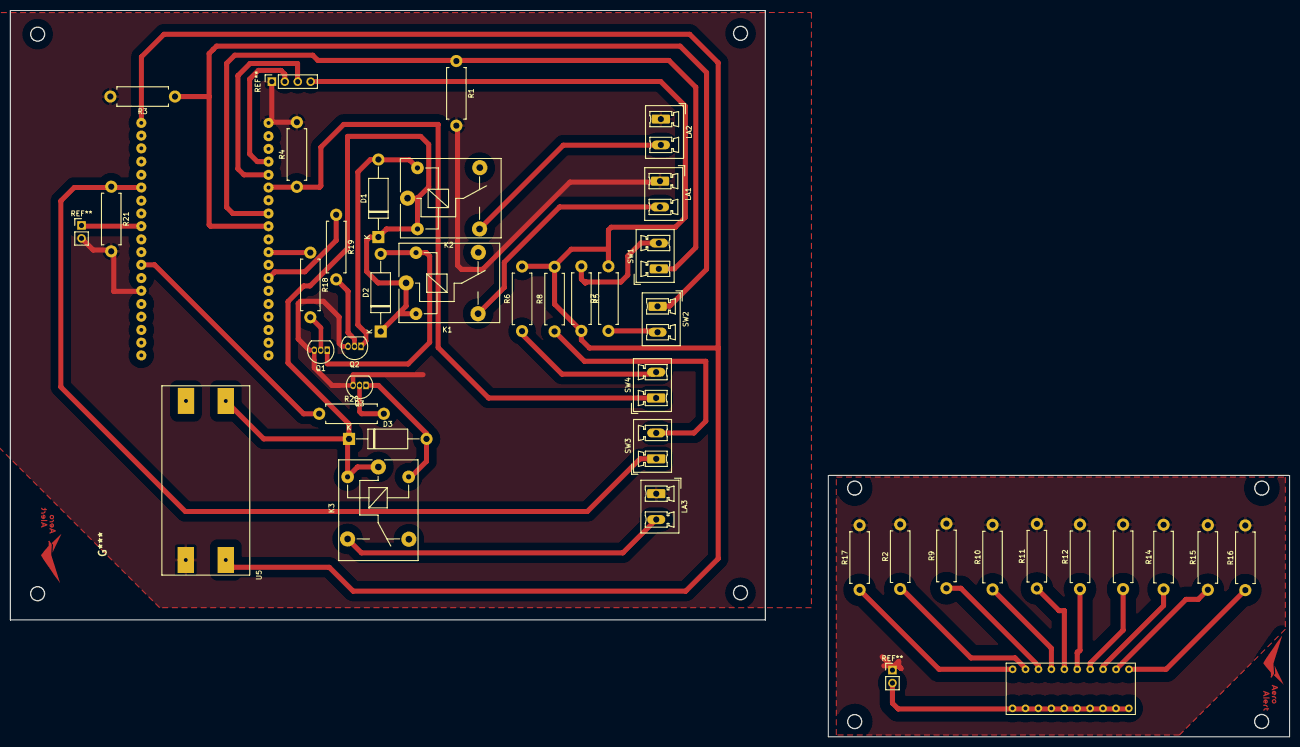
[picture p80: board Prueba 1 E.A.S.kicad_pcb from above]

Board: 2 copper layers, 251.5 x 142.8 mm, 40 parts (0 on the bottom side), 34 nets.

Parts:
BAR1: HDSP-4830_2; Led Bar Display
D1, D2, D3: D; D_DO-15_P15.24mm_Horizontal
K1, K2, K3: ADW11; Relay_SPDT_SANYOU_SRD_Series_Form_C
LA1: Alert; PhoenixContact_MCV_1,5_2-G-5.08_1x02_P5.08mm_Vertical
LA2: Warning; PhoenixContact_MCV_1,5_2-G-5.08_1x02_P5.08mm_Vertical
LA3: Test Fail; PhoenixContact_MCV_1,5_2-G-5.08_1x02_P5.08mm_Vertical
Q1, Q2, Q3: BC337; TO-92_Inline
R1, R2, R3, R4, R5, R6, R7, R8, R9, R10, R11, R12, R13, R14, R15, R16, R17, R18, R19, R20, R21: R; R_Axial_DIN0411_L9.9mm_D3.6mm_P12.70mm_Horizontal
SW1: Reaction; PhoenixContact_MCV_1,5_2-G-5.08_1x02_P5.08mm_Vertical
SW2: Test; PhoenixContact_MCV_1,5_2-G-5.08_1x02_P5.08mm_Vertical
SW3: Keylock (On/Off); PhoenixContact_MCV_1,5_2-G-5.08_1x02_P5.08mm_Vertical
SW4: Manual; PhoenixContact_MCV_1,5_2-G-5.08_1x02_P5.08mm_Vertical
U1: ESP32-WROOM-32; ESP32 NODEMCU
U5: Entrada 12V; MT 3608

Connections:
3V3: R5.2, R6.2, R7.2, R8.2, U1.1 (GND), U5.1 (Vin+)
12V: D1.1 (K), D2.1 (K), D3.1 (K), K1.1, K1.2, K2.1, K2.2, K3.1, K3.2, U5.3 (Vout+)
A: BAR1.1 (A), BAR1.2 (A), BAR1.3 (A), BAR1.4 (A), BAR1.5 (A), BAR1.6 (A), BAR1.7 (A), BAR1.8 (A), BAR1.9 (A), BAR1.10 (A), U1.10 (IO25)
FAIL: R20.1, U1.13 (IO14)
GNDREF: LA1.1 (-), LA2.1 (-), LA3.1 (-), Q1.3 (E), Q2.3 (E), Q3.3 (E), R1.2, R2.2, R3.2, R4.2, R9.2, R10.2, R11.2, R12.2, R13.2, R14.2, R15.2, R16.2, R17.2, R21.2, U1.2 (VDD), U1.15 (GND), U5.2 (Vin-)
unnamed: BAR1.11 (K), R16.1
unnamed: BAR1.12 (K), R15.1
unnamed: BAR1.13 (K), R14.1
unnamed: BAR1.14 (K), R13.1
unnamed: BAR1.15 (K), R12.1
unnamed: BAR1.16 (K), R11.1
unnamed: BAR1.17 (K), R10.1
unnamed: BAR1.18 (K), R9.1
unnamed: BAR1.19 (K), R2.1
unnamed: BAR1.20 (K), R17.1
unnamed: D1.2 (A), K2.5, Q2.1 (C)
unnamed: D2.2 (A), K1.5, Q1.1 (C)
unnamed: D3.2 (A), K3.5, Q3.1 (C)
unnamed: K1.3, LA1.2 (+)
unnamed: K2.3, LA2.2 (+)
unnamed: K3.3, LA3.2 (+)
unnamed: Q1.2 (B), R18.2
unnamed: Q2.2 (B), R19.2
unnamed: Q3.2 (B), R20.2
unnamed: R5.1, SW1.2
unnamed: R6.1, SW4.2
unnamed: R7.1, SW2.2
unnamed: R21.1, SW3.1 (C), U1.7 (IO35)
unnamed: R8.1, SW3.2 (D)
unnamed: R19.1, U1.31 (IO19)
unnamed: R18.1, U1.29 (IO5)
unnamed: R3.1, SW2.1, U1.27 (IO16)
unnamed: R1.1, SW1.1, U1.26 (IO4)
unnamed: R4.1, SW4.1, U1.24 (IO2)

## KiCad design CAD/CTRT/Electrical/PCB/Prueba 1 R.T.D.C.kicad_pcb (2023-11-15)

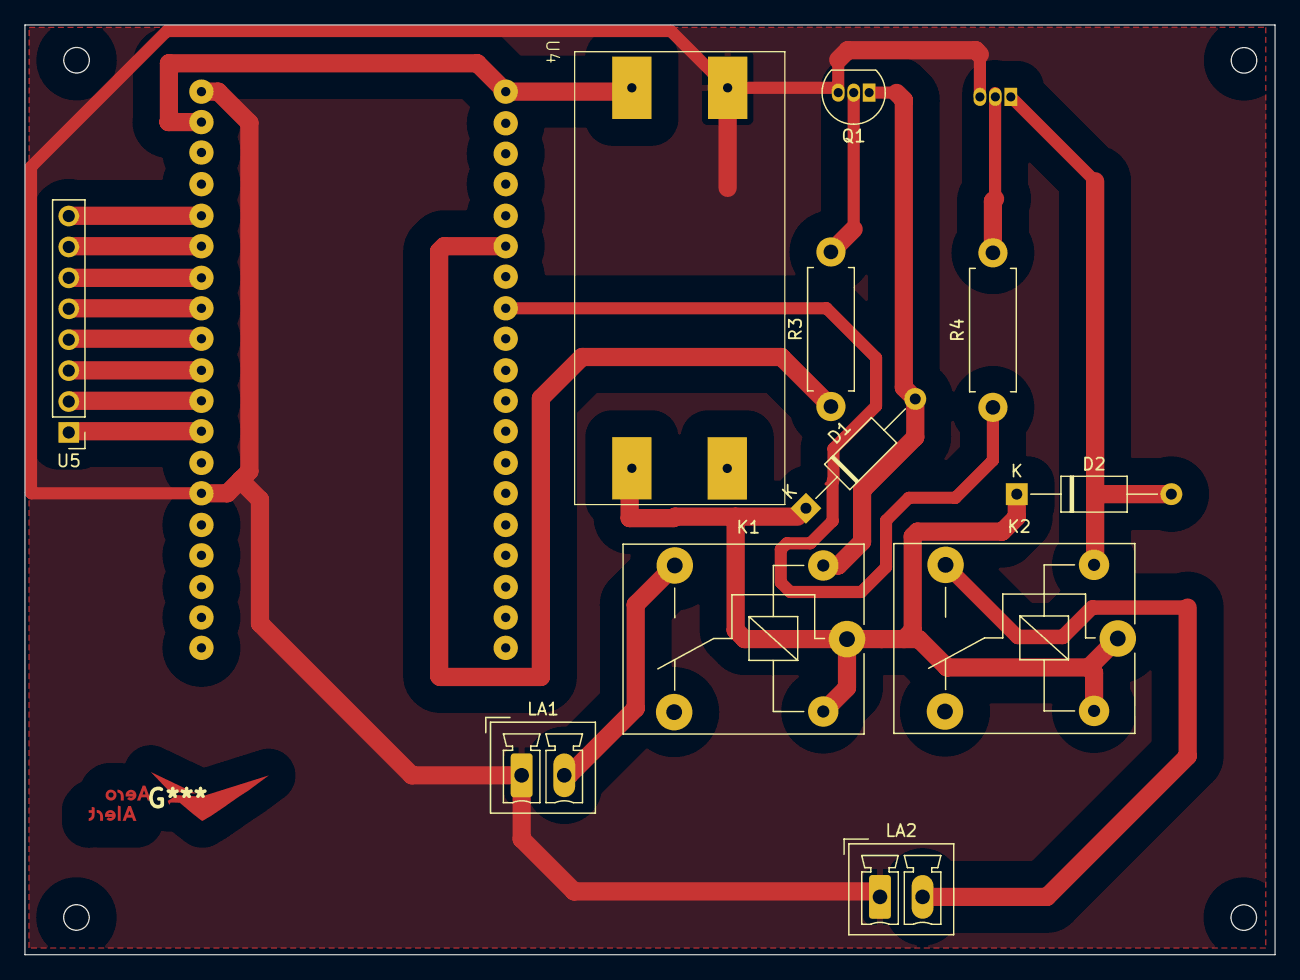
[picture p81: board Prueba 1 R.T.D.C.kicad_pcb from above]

Board: 2 copper layers, 102.7 x 76.4 mm, 13 parts (1 on the bottom side), 19 nets.

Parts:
D1, D2: D; D_A-405_P12.70mm_Horizontal
K1, K2: ADW11; Relay_SPDT_SANYOU_SRD_Series_Form_C
LA1: Alert; PhoenixContact_MCV_1,5_2-G-3.5_1x02_P3.50mm_Vertical
LA2: Warning; PhoenixContact_MCV_1,5_2-G-3.5_1x02_P3.50mm_Vertical
Q1, Q2: BC337; TO-92_Inline
R3, R4: 10K; R_Axial_DIN0411_L9.9mm_D3.6mm_P12.70mm_Horizontal
U1: ESP32-WROOM-32; ESP32 NODEMCU
U4: Entrada 12V; MT 3608
U5: PinHeader_1x08_P2.54mm_Vertical

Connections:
1: U1.13 (IO14), U5.1 (C4)
2: U1.12 (IO27), U5.2 (C3)
3: U1.11 (IO26), U5.3 (C2)
3V3: U1.2 (VDD), U1.3 (EN), U4.1 (Vin+)
4: U1.10 (IO25), U5.4 (C1)
5: U1.9 (IO33), U5.5 (R4)
6: U1.8 (IO32), U5.6 (R3)
7: U1.7 (IO35), U5.7 (R2)
8: U1.6 (IO34), U5.8 (R1)
12V: D1.1 (K), D2.1 (K), K1.1, K1.3, K2.1, K2.3, U4.3 (Vout+)
GNDREF: LA1.1 (-), LA2.1 (-), Q1.3 (E), Q2.3 (E), U1.1 (GND), U1.15 (GND), U4.2 (Vin-)
IO4: R4.1, U1.26 (IO4)
unnamed: D1.2 (A), K1.2, Q1.1 (C)
unnamed: D2.2 (A), K2.6, Q2.1 (C)
unnamed: K1.5, LA1.2 (+)
unnamed: K2.5, LA2.2 (+)
unnamed: Q1.2 (B), R3.2
unnamed: Q2.2 (B), R4.2
unnamed: R3.1, U1.24 (IO2)

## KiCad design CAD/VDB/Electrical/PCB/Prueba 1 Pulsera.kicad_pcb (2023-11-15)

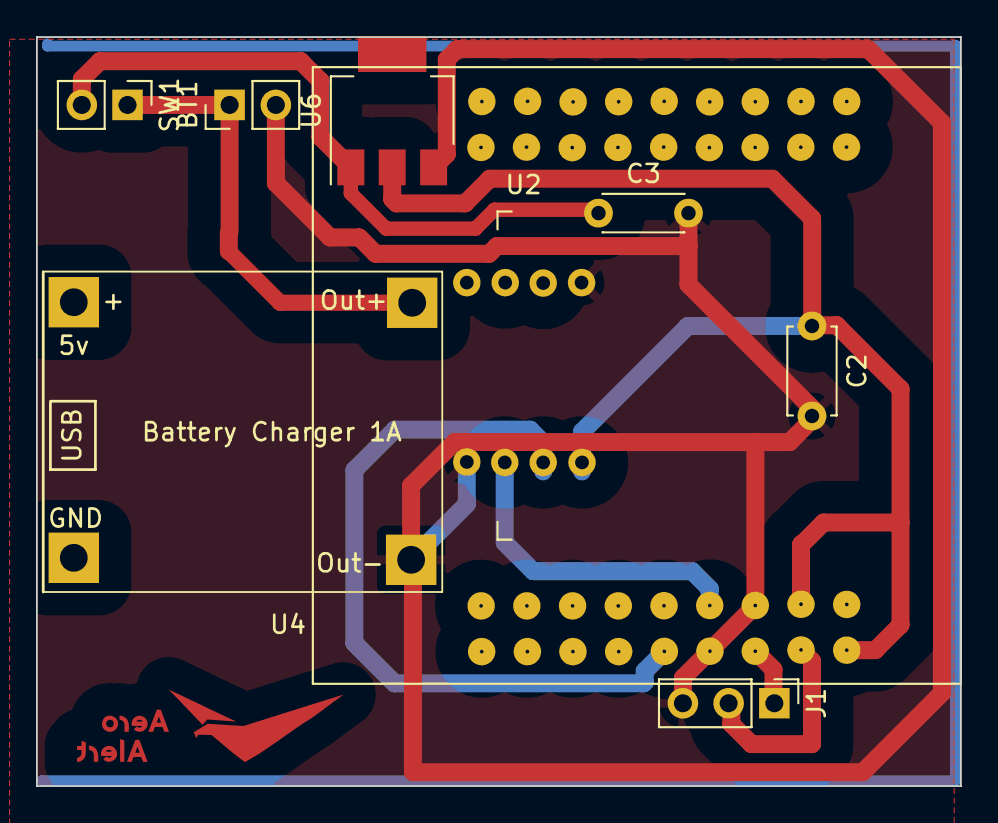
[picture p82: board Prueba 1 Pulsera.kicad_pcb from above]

Board: 2 copper layers, 51.3 x 41.6 mm, 9 parts (1 on the bottom side), 8 nets.

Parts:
BT1: 3.7V; PinHeader_1x02_P2.54mm_Vertical
C2: 10u; C_Disc_D4.7mm_W2.5mm_P5.00mm
C3: 10u; C_Disc_D4.3mm_W1.9mm_P5.00mm
J1: Conn_01x03_Socket; PinHeader_1x03_P2.54mm_Vertical
SW1: SW_DIP_x01; PinHeader_1x02_P2.54mm_Vertical
U1: MAX30102
U2: ESP32-WROOM-32
U4: TP4056; TP4056-18650
U6: LM1117DT-3.3; SOT-223

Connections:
GNDREF: BT1.2 (-), C2.2, C3.2, J1.3, U1.4 (PGND), U1.12 (GND), U1.13 (~INT), U2.1 (GND), U2.37 (IO23), U2.38 (GND), U4.4 (OUT-), U6.3 (VI)
unnamed: J1.1, U2.35 (TXD0/IO1)
unnamed: J1.2, U2.34 (RXD0/IO3)
unnamed: C3.1, SW1.2, U6.1 (GND)
PWR: BT1.1 (+), SW1.1, U4.3 (OUT+)
SCK: U1.2 (SCL), U2.36 (IO22)
SDA: U1.3 (SDA), U2.33 (IO21)
VDD: C2.1, U1.11 (VDD), U2.2 (VDD), U2.3 (EN), U6.2 (VO)

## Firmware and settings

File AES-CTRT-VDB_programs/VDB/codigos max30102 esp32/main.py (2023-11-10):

import utime
utime.sleep(2)

from pulsometro import Pulso
from machine import Pin
import _thread, utime, gc
import stationv9 as station                                                                                               # Se va a ir cambiando el nombre, cuidado



sensor = Pulso()                                # Creo objecto clase pulso
pin_conectado = Pin(17, mode=Pin.IN)                                                                                        # pin_prendido.value(1)     porque es el boton y tiene 
pin_led = Pin(19, mode=Pin.OUT)                                                                                                     # que estar prendido para que ande
conectado = pin_conectado.value()
client_socket = 0
                                                                                    
def mediciones():
    sensor.muestra()     # Realiza las mediciones

def mostrar():
    utime.sleep(0.5)
    global client_socket
    while True:
        #if pin_prendido.value() == 0:
        print("intentando conectar al AES")
        client_socket, sta_if = station.do_connect()    
        print("conectado al AES", client_socket)
        station.send_type(client_socket, sta_if)

        while True:
            """
            while pin_prendido.value():
                if led_prendido == 0:
                    pin_led.value(1)
                    led_prendido = 1
                    """
            beats = sensor.datos
            spo2 = sensor.datos2
            temp = sensor.datos3
            conectado = 1 #pin_conectado.value()
            try:
                #if beats > 55 and beats < 140:
                station.send_message(beats, spo2, temp, 
                                     conectado, client_socket, sta_if)
                print("enviado")
                print('',beats,'', spo2,'', temp,'', conectado)
            except Exception as error:
                print("No enviado",error)
            gc.collect()
            utime.sleep(4)

        utime.sleep(3)
_thread.start_new_thread(mediciones,()) # Proceso paralelo que mide el sensor
utime.sleep(0.5)
_thread.start_new_thread(mostrar,()) #Proceso paralelo agarra valores y envia

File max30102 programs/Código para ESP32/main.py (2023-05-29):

import pulsometro
from pulsometro import Pulso
from machine import Timer
import _thread
import time

import stationv5 as stationv5 #se va a ir cambiando el nombre, cuidado

#creo objecto clase pulso
sensorsito = Pulso()

def mediciones():
    sensorsito.muestra()     #hace las mediciones

def enviar (Timer):
    print()
    #asigna valores de las mediciones a las variables
    beats = sensorsito.datos
    spo2 = sensorsito.datos2
    temp = sensorsito.datos3
    
    global client_socket
    #imprime las variables
    print(beats, spo2, temp) #"bpm={:02} SpO2= {:02}% Temp {:02}°C".format
    stationv5.send_message(beats, spo2, temp, client_socket)
    
client_socket = 1
def mostrar():
    #crea un timer
    temporiza = Timer(0)
    global client_socket
    client_socket = stationv5.do_connect()
    print(client_socket)
    #genera un desborde cada vez que el timer alcanza 350 llamando a la funcion "desborde"
    #temporiza.init(period=10000,mode=Timer.PERIODIC,callback=enviar)
    while True:
        print()
        #asigna valores de las mediciones a las variables
        beats = sensorsito.datos
        spo2 = sensorsito.datos2
        temp = sensorsito.datos3
    
        #imprime las variables
        print(beats, spo2, temp) #"bpm={:02} SpO2= {:02}% Temp {:02}°C".format
        stationv5.send_message(beats, spo2, temp, client_socket)
        time.sleep(5)
    
#hago un thread para la funcion "mediciones"
_thread.start_new_thread(mediciones, ())

#hago un thread para la funcion "mostrar"
_thread.start_new_thread(mostrar, ())

"""
def enviar_wifi():
    stationv4.do_connect()
    while True:
        stationv4.send_message(1)
        time.sleep(3)
"""

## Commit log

2023-05-05 docs: Corrección de cambio hecho previamente al documento
2023-05-09 chore: add programs sensor esp32
2023-05-09 docs: add documentacion max30102
    docs: datasheet sensor
    docs: datasheet infrarrojo
    docs: oximetria
2023-05-12 chore: adjust time
    se trababa por imprimir mucho "not finger"
2023-05-15 feat: mide temperatura
2023-05-16 style: sensar temperatura comentado
2023-05-16 refactor: cambiar import station para mantenerlo
2023-07-11 feat: .py prueba de sensor
    principal: archivo a continuar desarrollando
2023-07-11 fix: cant stop esp32 mini when program uploaded
    [pulsometro.py]
2023-08-08 wifi working perfectly with sensor and sae
2023-08-11 envio de datos, r4ecepcion y casos masomenos
2023-08-16 feat swithces de prueba copiloto
2023-08-28 feat: uart
2023-09-18 probar uart
2023-10-08 fix: receive info PC and analyze
    [GUI.py, accesssv8.py, stationPCv1.py]
2023-10-09 feat: use info from PC switches
2023-10-09 feat: request landing information
2023-10-10 fix: pc info usage
    [GUI.py, accesssv8.py, stationPCv1.py]
2023-10-18 feat: send airport for landing
2023-10-18 feat: diccionario para tabla de vuelos
2023-10-18 fix: diccionario para lista de vuelos
2023-10-20 Cambios en caps deploying y corte de suministro de combustible.
2023-10-21 fix: band not finger constantly
    [main.py, pulsometro.py]
2023-10-21 feat: calibration for bpm
2023-10-22 Modificar activación de vertical speed y condición de approach
2023-10-22 fix: max30102 calibration bpms
    [main.py, pulsometro.py]
2023-10-24 Modificar curso de referencia (en grados) para aproximación
2023-10-25 fix: ctrt tables not creating
    [main.py]
2023-10-26 feat: mas de los protocolos ayuda tengo sueño
2023-11-04 Optimizar fase de aterrizaje
2023-11-04 Fase de aterrizaje optimizada
2023-11-15 Documentación actualizada a la fecha (15/11/2023)
2023-11-15 Modelado 3D, ensamblaje y vista explotada (VDB)
    [VDB - Main Struct.stl, VDB - Top Cover.stl]
2023-11-15 Modelado 3D, Ensamblaje y Vista Explotada (CTRT)
    [CTRT - Keycaps.stl, CTRT - Main Struct.stl]
2023-11-15 Archivos de Esquemático, PCB, PDF para impresión
    [Prueba 1 Pulsera.kicad_pcb, Prueba 1 Pulsera.kicad_sch]
2023-11-15 Archivos de Esquemático, PCB, PDF para impresión
    [Prueba 1 E.A.S.kicad_pcb, Prueba 1 E.A.S.kicad_sch]
2023-11-15 Logotipos de marca
2023-11-15 Banner para exposición del proyecto
2023-11-15 Recursos adicionales para banners y documentación
2023-11-17 saque una "de"
2023-11-17 arregle en lo que me equivoque
2023-11-17 Corrección de mis redes
2023-11-17 Cambios del orden de documentación
    Cambio dentro del orden de los documentos, se creo dos carpetas una relacionada los documentos del prototipo y otra relacionada a los documentos del funcionamiento en la aviación
2023-11-17 Docs: Agregar documentos faltantes
    Faltaban 2 documentos: Anteproyecto y Manual de Usuario
2023-11-17 Docs: Documentos faltantes del Funcionamientos en la Aviación
    Terminar de actualizar la ducumentación del proyecto
2023-11-17 Docs: Corrección de ortografía
    Corrección ortografía de los titulos de los documentos
2023-11-17 chore: Comentar UART_X-Plane
2023-11-18 Archivo .step PCB A.E.S
    [A.E.S - STEP File.step]
2023-11-18 Archivo .step PCB C.T.R.T
2023-11-18 Archivo .setp PCB V.D.B
2023-11-18 Archivo .step PCB V.D.B
2023-11-18 Solicitud de Materiales
2023-11-19 feat: nueva carpeta y traslado de archivos
2023-11-19 Facturación de Compras
2023-11-19 Agregado del documento "Administración de presupuesto"
    [Administracion de presupuesto Proyecto Aeroalert.xlsx]
2023-11-19 Corrección de CV
2023-11-21 Certificados de participación (Pagano y Ruiz)
2023-11-21 Iconos para historias destacadas
2023-11-21 Actualización de planilla de compras
    [Administracion de presupuesto Proyecto Aeroalert.xlsx]
2023-11-21 Corrección
    [Planilla de compras Proyecto Aeroalert.xlsx]
2023-11-22 Docs: Subir Certificado Oniet
    Subo el certificado de Oniet
2023-11-22 Docs: Presentación de Ventas (Entrepiso)
2023-11-22 Elementos de alcances inconclusos
2023-11-22 Fotos de AES y CTRT
2023-11-22 QR de Difusión
2023-11-22 Agregado de certificado ONIET
2023-11-23 Docs: Manual de Usuario Actualizado
2023-11-23 Docs: Arreglo de links a redes profesionales defectuosos
2023-11-23 Create a folder "htmls" and add de file "Acercade.html"
2023-11-23 resubida de archivos
2023-11-24 resubida de archivos CTRT
2023-11-24 resubida de archivos AES
2023-11-24 Revert "test"
    This reverts commit 75337bd3fbc72137d0644d74614b593ee438620f.
    [CTRT.py]
2023-11-24 Arreglo para que se vea la imagen
2023-11-24 cambiar el codigo
2023-11-28 Docs: Corrección de ruta a imagen grupal
2023-11-28 feat: Archivos .step y .sldprt para ensamblajes
    [10-Pin Header - Female - 2.54mm.step, 10-Pin Header - Male - 2.54mm.step, 11-Pin Header - Female - 2.54mm.step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]
2023-11-29 Docs: Archivos de Routeado CNC (Carcasas AES / CTRT)
    [C1 Main Case - Part 1-2.dxf, C1 Main Case - Part 1-3.dxf, C1 Main Case - Part 1-4.dxf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]
